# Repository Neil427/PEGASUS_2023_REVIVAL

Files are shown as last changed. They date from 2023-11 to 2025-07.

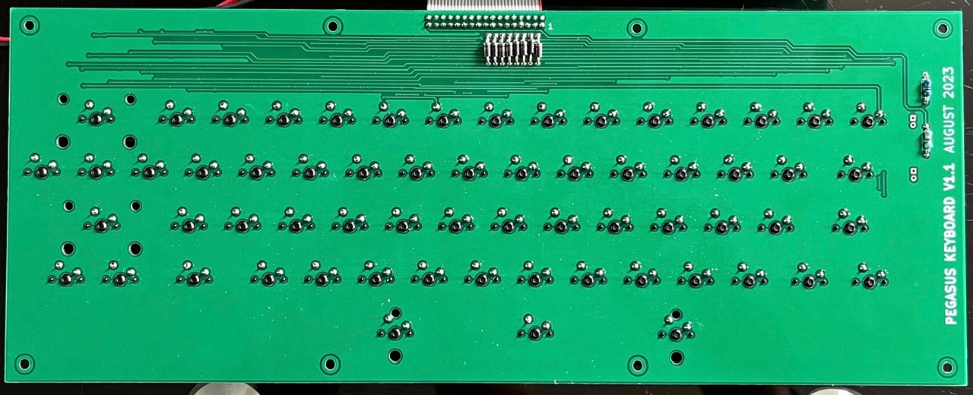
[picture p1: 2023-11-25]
Images/PegasusKeyboardRear.jpeg

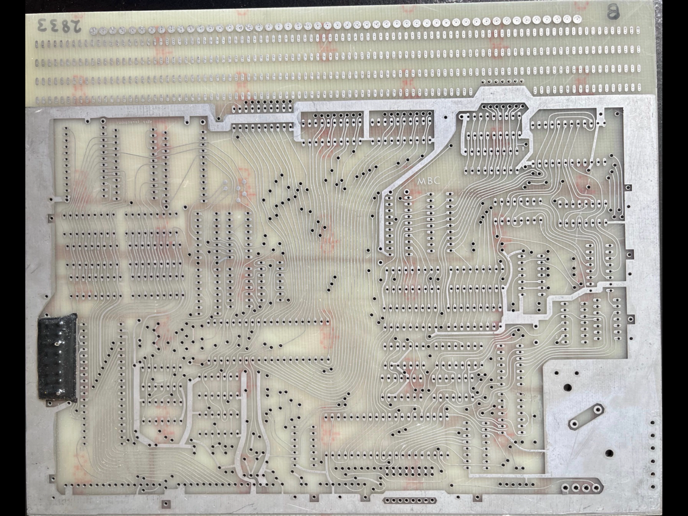
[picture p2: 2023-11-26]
Images/OriginalPCBtop.png

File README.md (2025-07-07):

# PEGASUS_2023_REVIVAL
:

NOTE: FROM 2025 ON DEVELOPMENT WILL CONTINUE ON MY DEDICATED VINTAGE COMPUTER GITHUB "NeilsVintageComputers"

:
AamberPegasus6809

This is a reproduction of the first computer I owned back in 1981
After many years and house moves I now dont know whatever happened to it, it may have been sold or dumped, I have no idea.

One day while sorting through floppy disk backups I found all the Pegasus eprom files I had saved dated 1988, including some extra monitor eproms I had made that I think one was for Baudot printer output and the other was for a modification I had made fitting a 6845 CRT controller.
The discovery of the Eprom files and manual with schematics gave me the idea of building a replica, I mentioned this to a mate Gavin who told me he had a unused blank Pegasus circuit board that I could have and build up.  I decided not to build up the board as a bare board is probably quite rare, and without components on it was a great help in verifying the original schematic and designing this new pcb.

Searching found a huge repository on github of Aamber Pegasus software and information (github/Neoncluster/Aamber-Pegasus-remake), the information is a great recource and thanks to Neoncluster for preserving it. 

It looked like this remake was not completed so I decided to start from scratch from the original Pegasus schematics.
I drew the original schematics from the Pegasus manual into Kicad (thanks to Neoncluster for your Kicad Library), finding a few errors in the original documentation which I could verify on the blank PCB. Then started a new Kicad project for the new PCB, I added in the video jitter mods that were done to correct problems with the original Pegasus video design one of which was designed by Gavin back in the 80s.   NOTE: These jitter mds require the use of MON23a monitor eprom.

I have added a 16K Eprom to the board so as to be able to have the three Xbasic eproms on board without needing an expansion board like I used back in 1981, there is also a switch to select two halves of a 32K eprom giving the equivalent of 8 original 4K eproms. 
Also added are option jumpers for the three TMS2532 eprom sockets to allow selection of either TMS2532 or TMS2732 eproms as the TMS2532 is not easy to find these days, and a LED for tape data indication. 

All ICs used are the original ones as in the original pegasus bom, the 74LS logic chips are still available and most of the rareish chips were available on Ebay and other places. The only expensive (read very rare) one was the MCM66710 character generator which I found on Ebay only.

Amazingly it worked first time! All the hours of tracing out what I thought were errors in the original schematic had paid off. 
There was one minor problem I found, if you have no memory/eprom expansion board plugged in but have the LS245 buffer fitted the firmware can read in random data from the expansion bus when doing its check of RamEnd. This causes Basic (or any other program using RamEnd) to crash when trying to use non-existing memory. By luck after trying a few brands (inclding 74HCT245s) I discovered that a Ti brand SN74LS245N worked (Maybe that brand was used in the original Pegasus as I dont remember this being a problem back in 1981), the memory check now doesnt find non-existant memory on the expansion bus. Some pullup resistors on the expansion bus side of these buffers would be a good idea.

Now I had a working Pegasus all I needed was a keyboard. The manual doesnt have the keyboard schematic so this was a lot of work systematically producing key closures and seeing what character they produced!  The first pcb mostly worked, a few of the non printing keys were wrong, so it took another board to correct these. I havent found any errors yet with the current board.  You cant buy cheap Chinese keycaps exactly the same as the old Pegasus keyboard so I have found a set with logical alternatives (i.e."END" for the Break key etc.), you could of course print some stickers with the correct name.
The keyboard has a 34-pin IDC connector as I am going to use it with another board I am working on. For use on the Pegasus main board the "even" side of the idc connector (pins 2-----32) plug into the SIL connector on the main board, alternatively a 16-pin SIL header can be inserted in keyboard pcb connector positions 2-----32 to allow use of SIL connectors as in the original Pegasus (Though my sketchy memory is telling me the KB end of the cable might have been soldered direct to the pcb).  
There are two unused LEDs on the Keyboard pcb intended for use as Power On and Cassette Data, these appear on the 34-pin connector but are not brought out on the main board.

NOTES/ISSUES:
- The resistor on the rear of the pcb is a pullup on the bit7 input to the video output shift register (not in the original Pegasus design) to try and remove a small video disturbance at the top of the screen before the first video character line when in graphics mode. It definalely helped but there is still a small disturbance. Need to look into this further.
Further investigation found a faulty 6809 driving one or two of the address lines to only about 2.5V
Needs further investigation and maybe a "improved" design board to be produced as it looks like the original Pegasus design has many more than 4 LS-TTL loads, as specified in the 6809 datasheet, on the address and data lines. It did still work ok with six out of seven 6809 chips I tried. Just one didnt work 100% reliably.
- The 127p capacitor C10 on the dotclock oscillator can be adjusted to trim the dotclock frequency. I noticed on my build that the shift register was clocking out a extra bit making the characters wider than they should be, not really noticeable in text mode but in inverse char graphics mode there would be a "lit up" column of dots at the right of each character.  If the dotclock is too slow the oposite will happen which is noticeable in both text and graphics mode as trimming of the right most dot of a character. I ended up with 138pF (120p + 18p).
- The PCB although the same dimension as the original cant be slid into the original Pegasus square white case as I inadvertently laid the power tracks too close to the edge of the pcb!
- The resistor footprint used is a bit large, needs reducing if producing a update to the board.
  
Here are some phtos of the finished "Pegasus"

AamberPegasus1

AamberPegasus2

Neil

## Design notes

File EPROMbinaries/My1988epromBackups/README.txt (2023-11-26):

These eprom binaries will not all work in a Pegasus board, some of them are experimental ones that I made which I will try to remember/discover what for and update this readme.
Anyone building this should use the Mon23a monitor and the combined eprom files set up to go in Rom4 socket.

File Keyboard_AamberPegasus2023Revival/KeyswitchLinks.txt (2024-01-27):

7.5V 3A PLUGPACK

https://www.aliexpress.com/item/1005006269859150.html

NOTE: THERE IS A AU PLUG OPTION ON THIS LISTING

KEYBOARD SWITCHES

https://vi.aliexpress.com/item/32810197006.html?spm=a2g0o.cart.0.0.352b38daK8j2Au&mp=1&gatewayAdapt=glo2vnm

NOTE: ORDER 5-PIN CHERRY TYPE, THE BLACK ONES HAVE THE MOST VINTAGE FEEL.

KEYBOARD KEYCAPS

THESE ARE ONES I FOUND THAT WILL FIT THE SWITCH SPACINGS ON THE PCB

https://vi.aliexpress.com/item/1005005924340896.html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

NOTE: OTHER SETS DON'T ALLWAYS HAVE THE CORRECT LENGTH AND SWITCH CENTER FOR ALL THE CONTROL TYPE KEYS

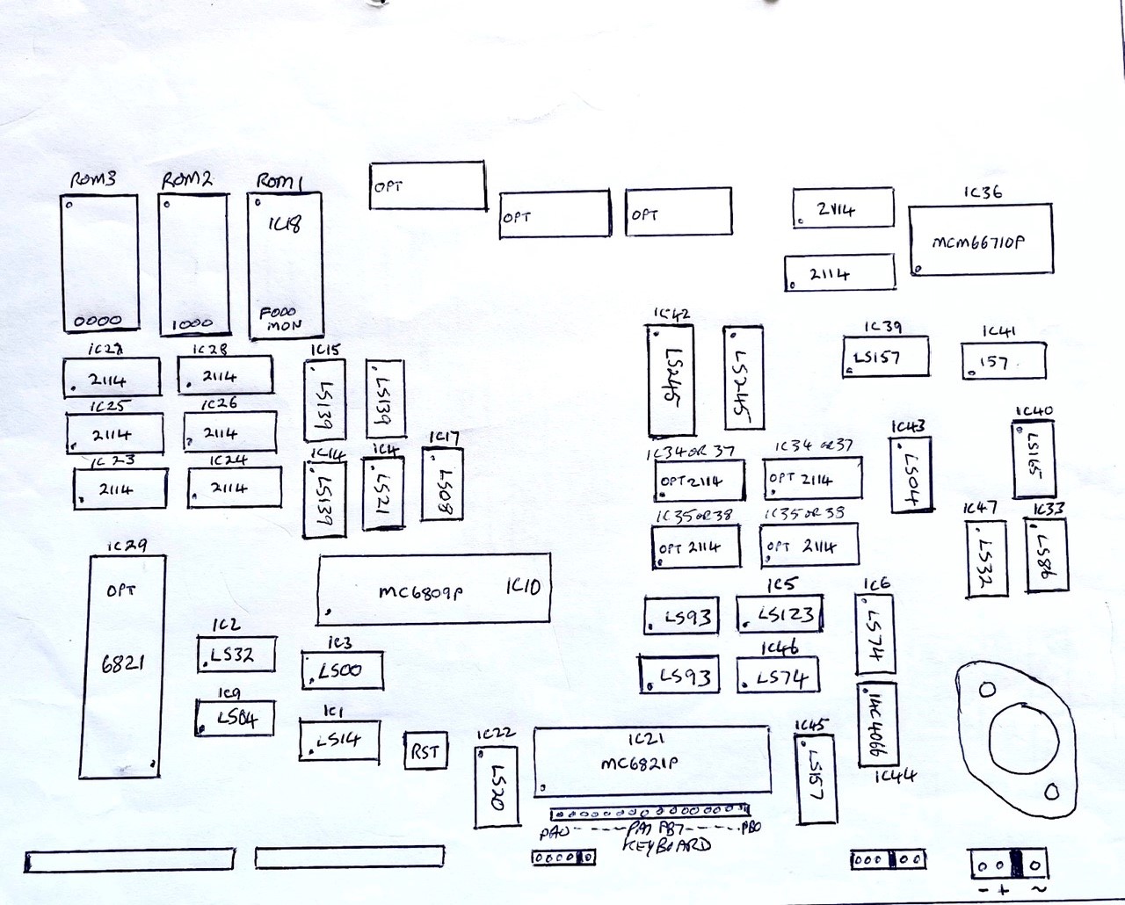
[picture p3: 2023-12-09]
OriginalPegasusSchematic/AamberPegasusOriginalPCBchipLayout.png

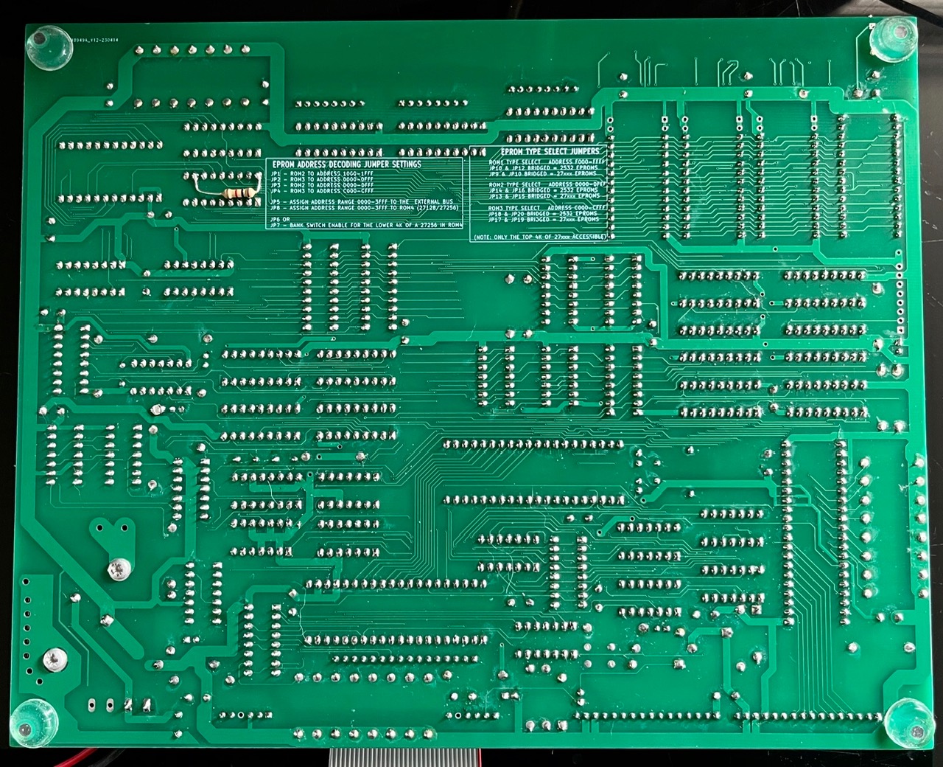
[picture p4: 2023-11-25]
Images/PegasusPcbRear.jpeg

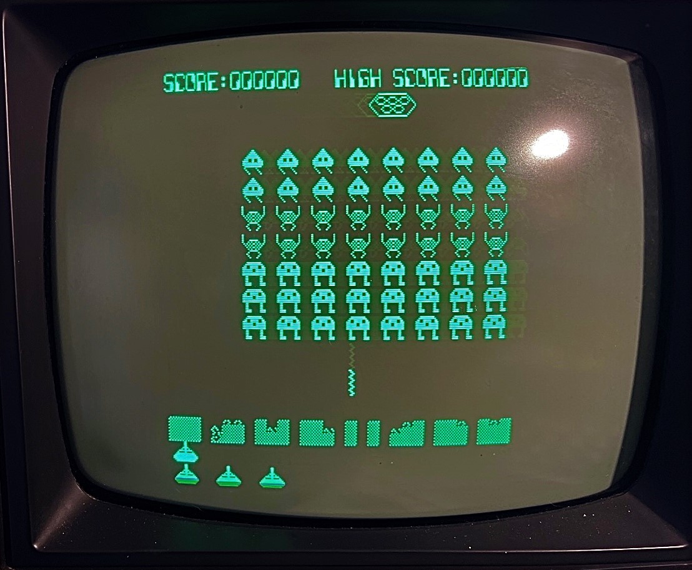
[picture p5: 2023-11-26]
Images/PegasusInvaders (2).jpg

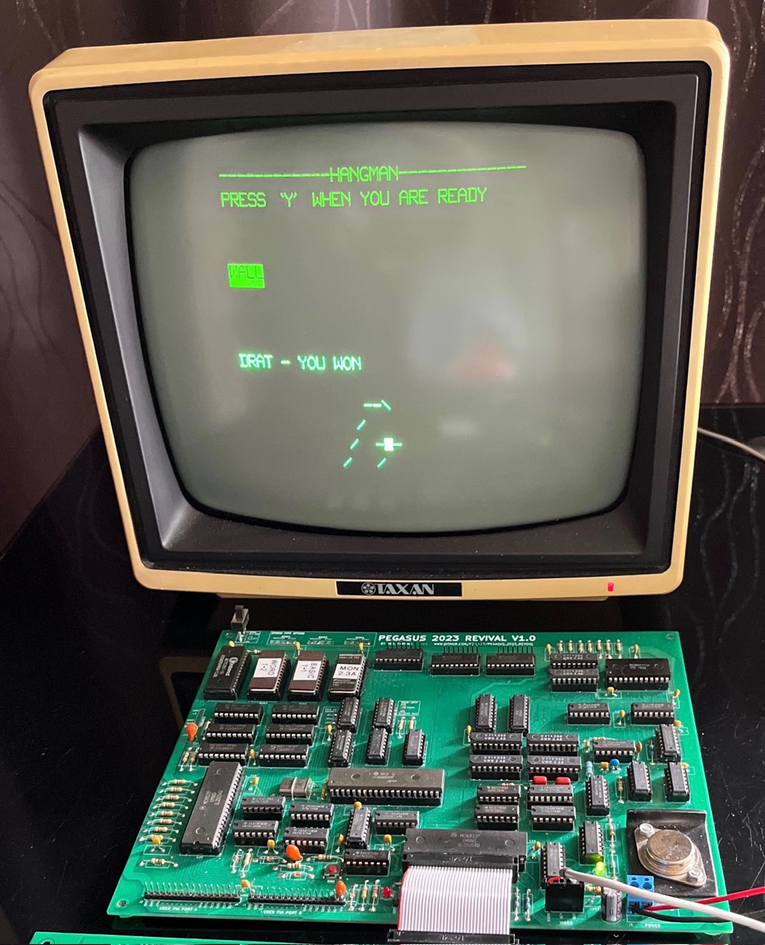
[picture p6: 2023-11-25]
Images/PegasusHangman2.jpeg

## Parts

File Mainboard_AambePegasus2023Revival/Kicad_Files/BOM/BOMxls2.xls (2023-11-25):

Item | Qty | Reference(s) | Value
1 | 1 | C1 | 150N
2 | 1 | C2 | 330N
3 | 1 | C3 | 100N
4 | 1 | C4 | 1uF 35V
5 | 2 | C5, C6 | 27p
6 | 1 | C7 | 1uF 35V Tant
7 | 22 | C8, C12, C13, C14, C15, C16, C17, C18, C19, C20, C21, C22, C23, C24, C25, C26, C27, C28, C29, C30, C31, C103 | 100N
8 | 1 | C9 | 47p | Status
9 | 1 | C10 | 127p
10 | 1 | C11 | 1uF 35V T
11 | 1 | C32 | 1N
12 | 1 | C33 | 47pF
13 | 1 | C34 | 47uF
14 | 1 | D1 | 3mmLED
15 | 1 | D2 | GreenLED
16 | 4 | D3, D4, D5, D6 | 1N4148
17 | 1 | J1 | PIA PortB
18 | 1 | J2 | PIA PortA
19 | 1 | J3 | Cassette Tape
20 | 1 | J4 | Video Out
21 | 1 | J5 | Power
22 | 1 | J8 | External Data Bus
23 | 2 | J9, J10 | External Address Bus
24 | 1 | J11 | SPARE
25 | 1 | J12 | Keyboard
26 | 1 | JP1 | rom2
27 | 1 | JP2 | rom3
28 | 1 | JP3 | rom2 alt
29 | 1 | JP4 | rom3 alt
30 | 2 | JP5, JP8 | opt.
31 | 1 | JP6 | romL
32 | 1 | JP7
33 | 6 | JP9, JP11, JP13, JP15, JP17, JP19 | 27Cxxx
34 | 6 | JP10, JP12, JP14, JP16, JP18, JP20 | 2532
35 | 2 | R1, R2 | 100R
36 | 1 | R3 | 8K2
37 | 1 | R4 | 27K
38 | 1 | R5 | 100K
39 | 1 | R6 | 1M
40 | 24 | R7, R8, R9, R10, R11, R12, R13, R16, R17, R18, R19, R20, R21, R22, R23, R28, R29, R30, R31, R32, R33, R34, R35, R44 | 1K
41 | 1 | R14 | 470R
42 | 10 | R15, R36, R37, R38, R39, R40, R41, R42, R43, R45 | 4K7
43 | 1 | R24 | 220R
44 | 1 | R25 | 470
45 | 1 | R26 | 390R
46 | 1 | R27 | 2K7
47 | 1 | SW1 | NMI
48 | 1 | U1 | 74LS14
49 | 2 | U2, U47 | 74LS32
50 | 1 | U3 | 74LS00
51 | 1 | U4 | 74LS21
52 | 1 | U5 | 74LS123
53 | 2 | U6, U46 | 74LS74
54 | 2 | U7, U8 | 74LS93
55 | 2 | U9, U43 | 74LS04
56 | 1 | U10 | MC6809
57 | 3 | U11, U30, U42 | 74LS245
58 | 2 | U12, U13 | 74LS241
59 | 3 | U14, U15, U16 | 74LS139
60 | 1 | U17 | 74LS08
61 | 3 | U18, U19, U20 | EPROM
62 | 2 | U21, U29 | 6821
63 | 2 | U22, U49 | 74LS20
64 | 6 | U23, U24, U25, U26, U27, U28 | MC2114RAM
65 | 6 | U31, U32, U34, U35, U37, U38 | MC2114
66 | 1 | U33 | 74LS86
67 | 1 | U36 | MC66710
68 | 3 | U39, U41, U45 | 74LS157
69 | 1 | U40 | 74LS165
70 | 1 | U44 | 4066
71 | 1 | U48 | 4020
72 | 1 | U50 | 27128/27256
73 | 1 | Ureg1 | LM309K
74 | 1 | Y1 | 4MHz
 |  |  |  | Obsolete NonStock
 |  |  |  | Status
 |  |  |  | Obsolete NonStock

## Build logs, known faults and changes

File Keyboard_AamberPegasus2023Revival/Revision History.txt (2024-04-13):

V1.0 	- Development version with only alpha-numeric switches routed
V1.1 	- First production version
V1.2 	- Spacebar moved to row 7 as original Pegasus KB(works in row 5 as well as in V1.1)
	- Swapped ESC and BREAK keys, they were inadvertently swapped in V1.1
	- Added unused Repeat Key and 2x unused extra keys

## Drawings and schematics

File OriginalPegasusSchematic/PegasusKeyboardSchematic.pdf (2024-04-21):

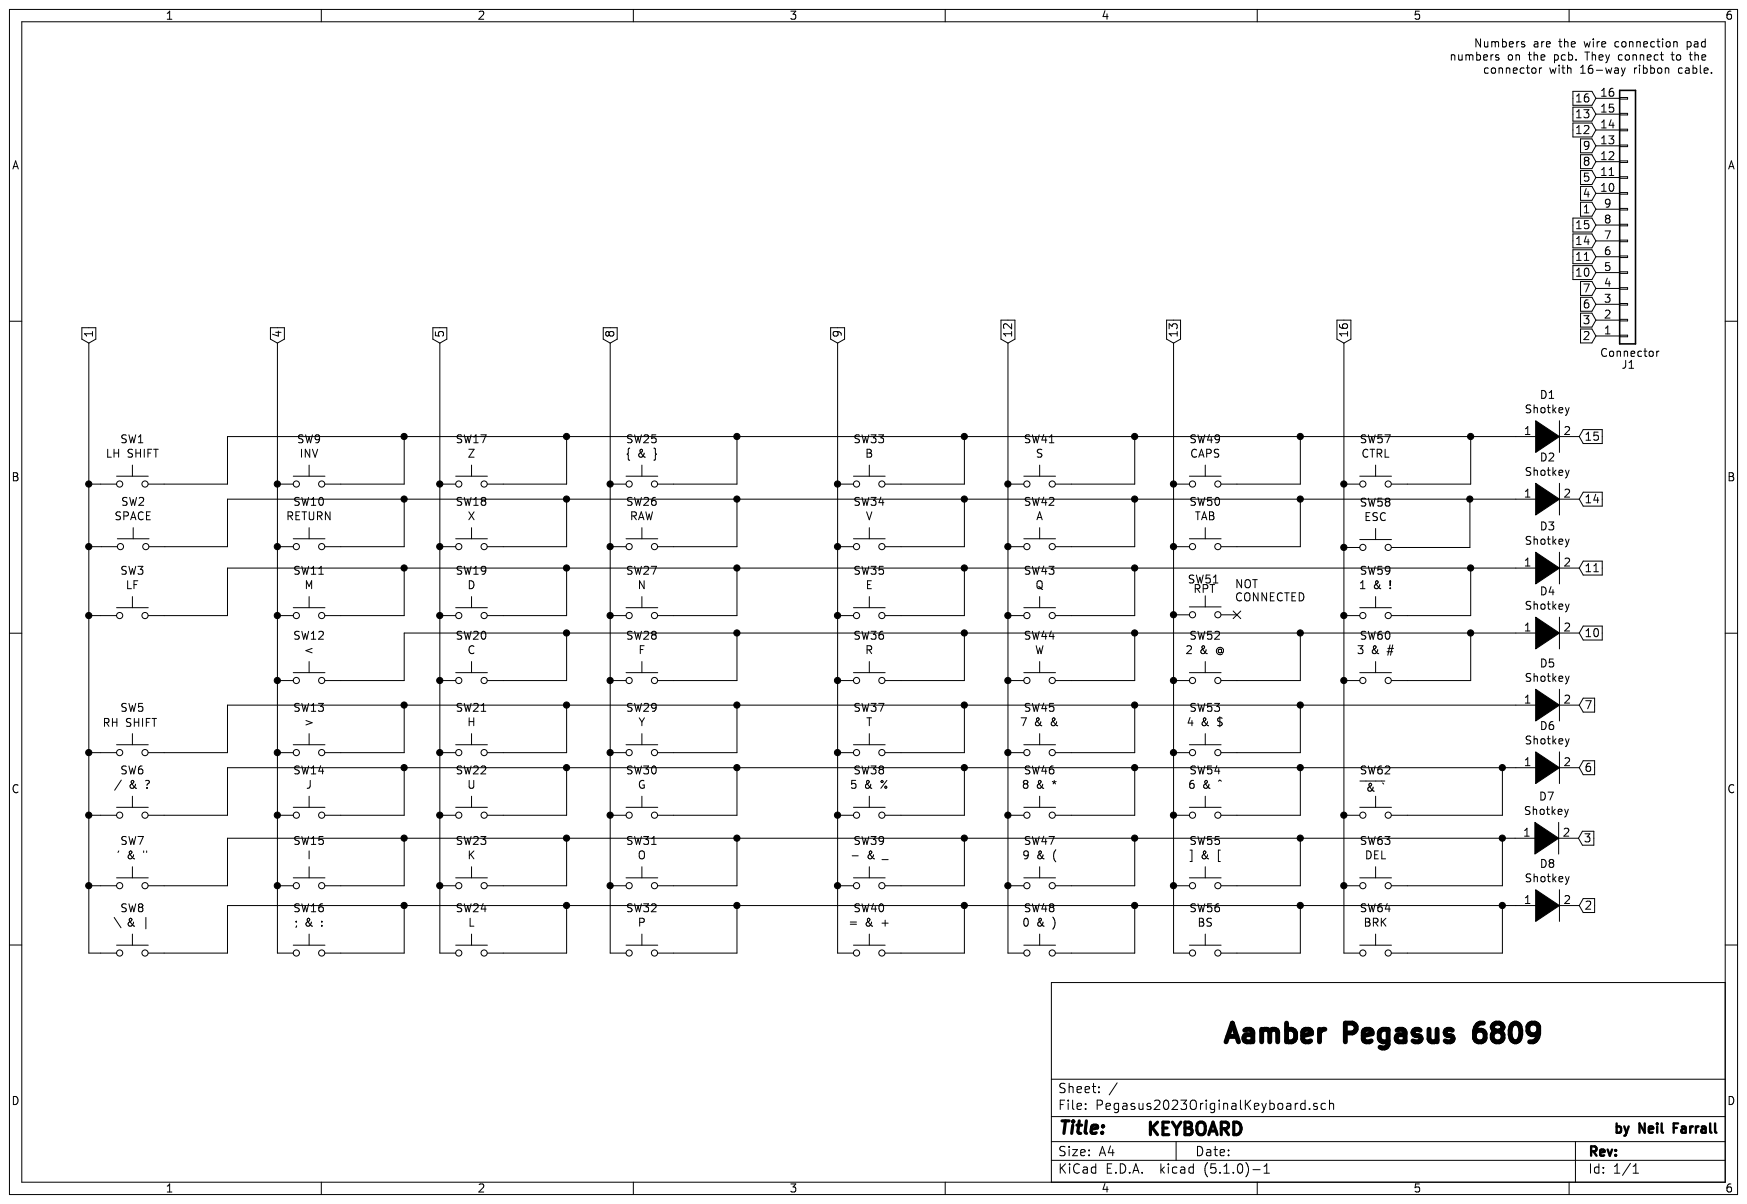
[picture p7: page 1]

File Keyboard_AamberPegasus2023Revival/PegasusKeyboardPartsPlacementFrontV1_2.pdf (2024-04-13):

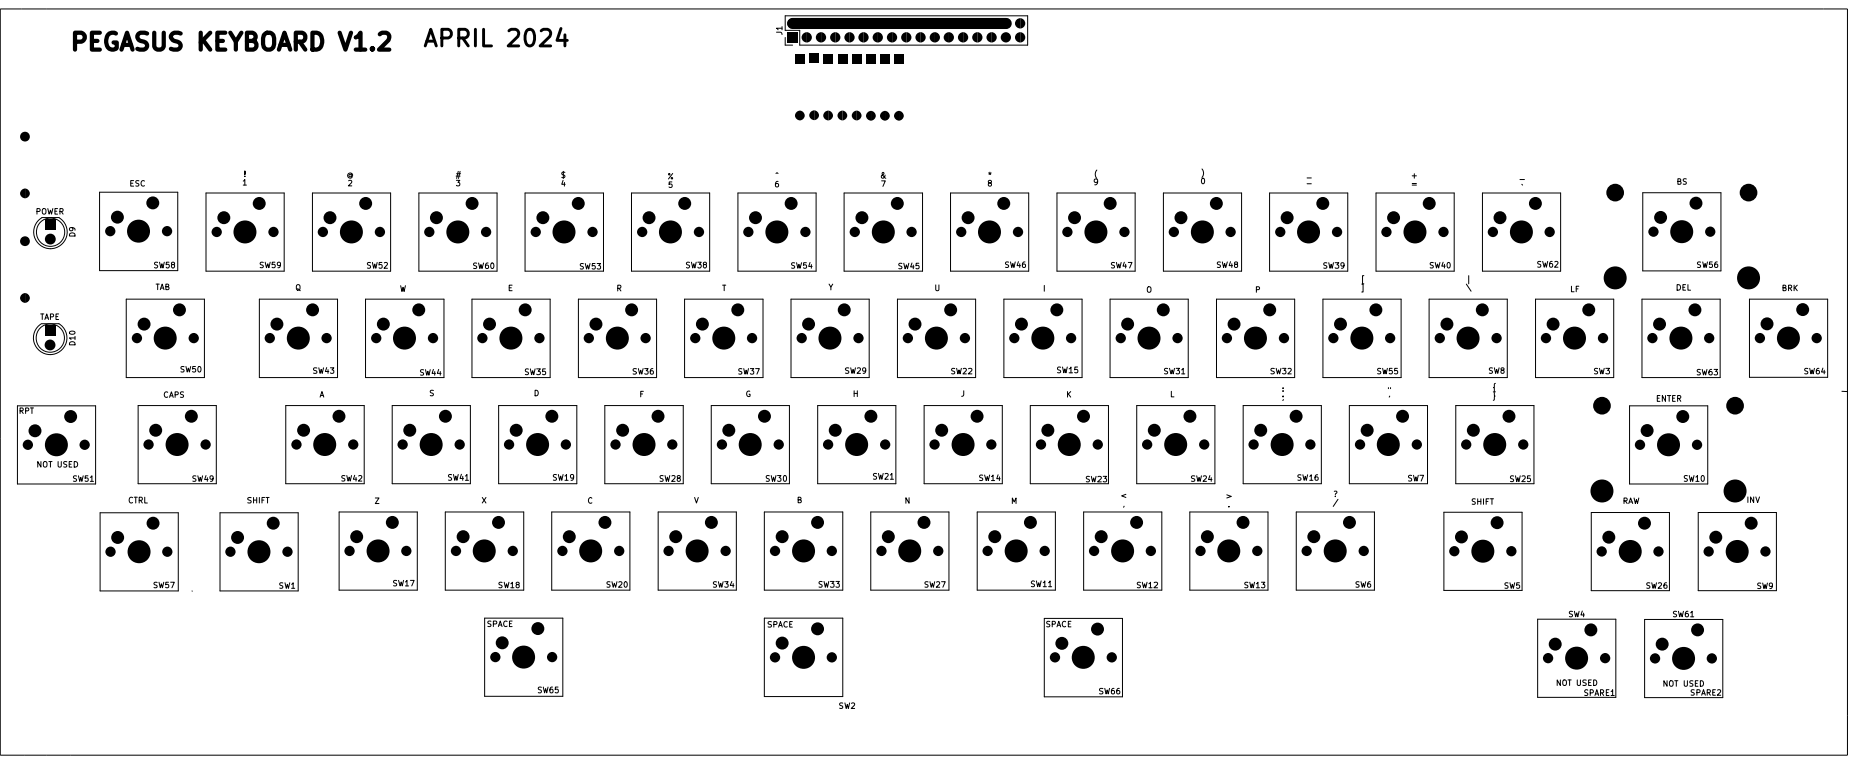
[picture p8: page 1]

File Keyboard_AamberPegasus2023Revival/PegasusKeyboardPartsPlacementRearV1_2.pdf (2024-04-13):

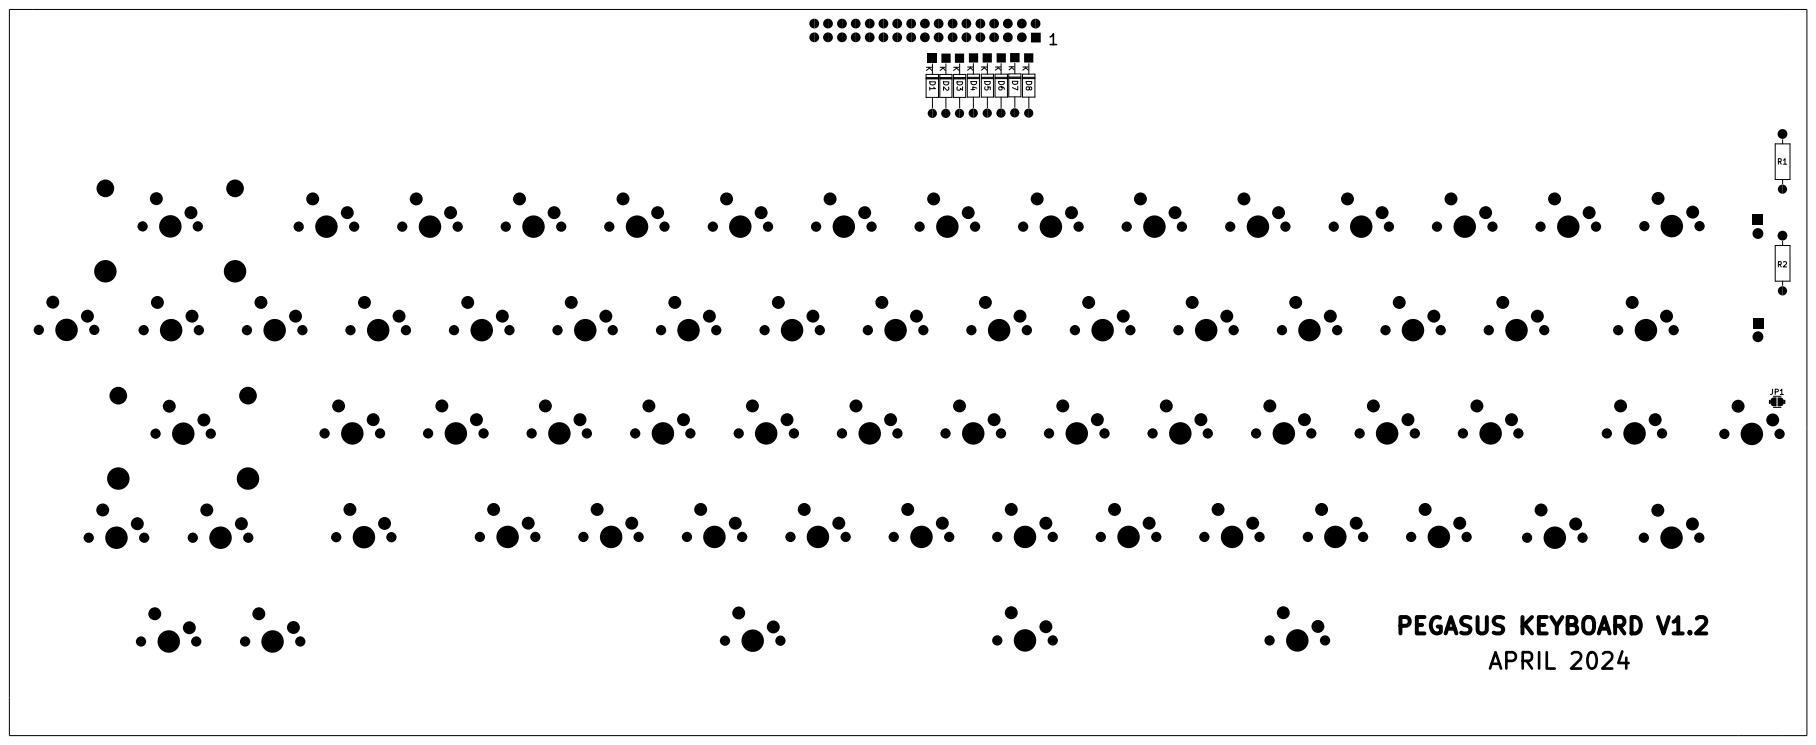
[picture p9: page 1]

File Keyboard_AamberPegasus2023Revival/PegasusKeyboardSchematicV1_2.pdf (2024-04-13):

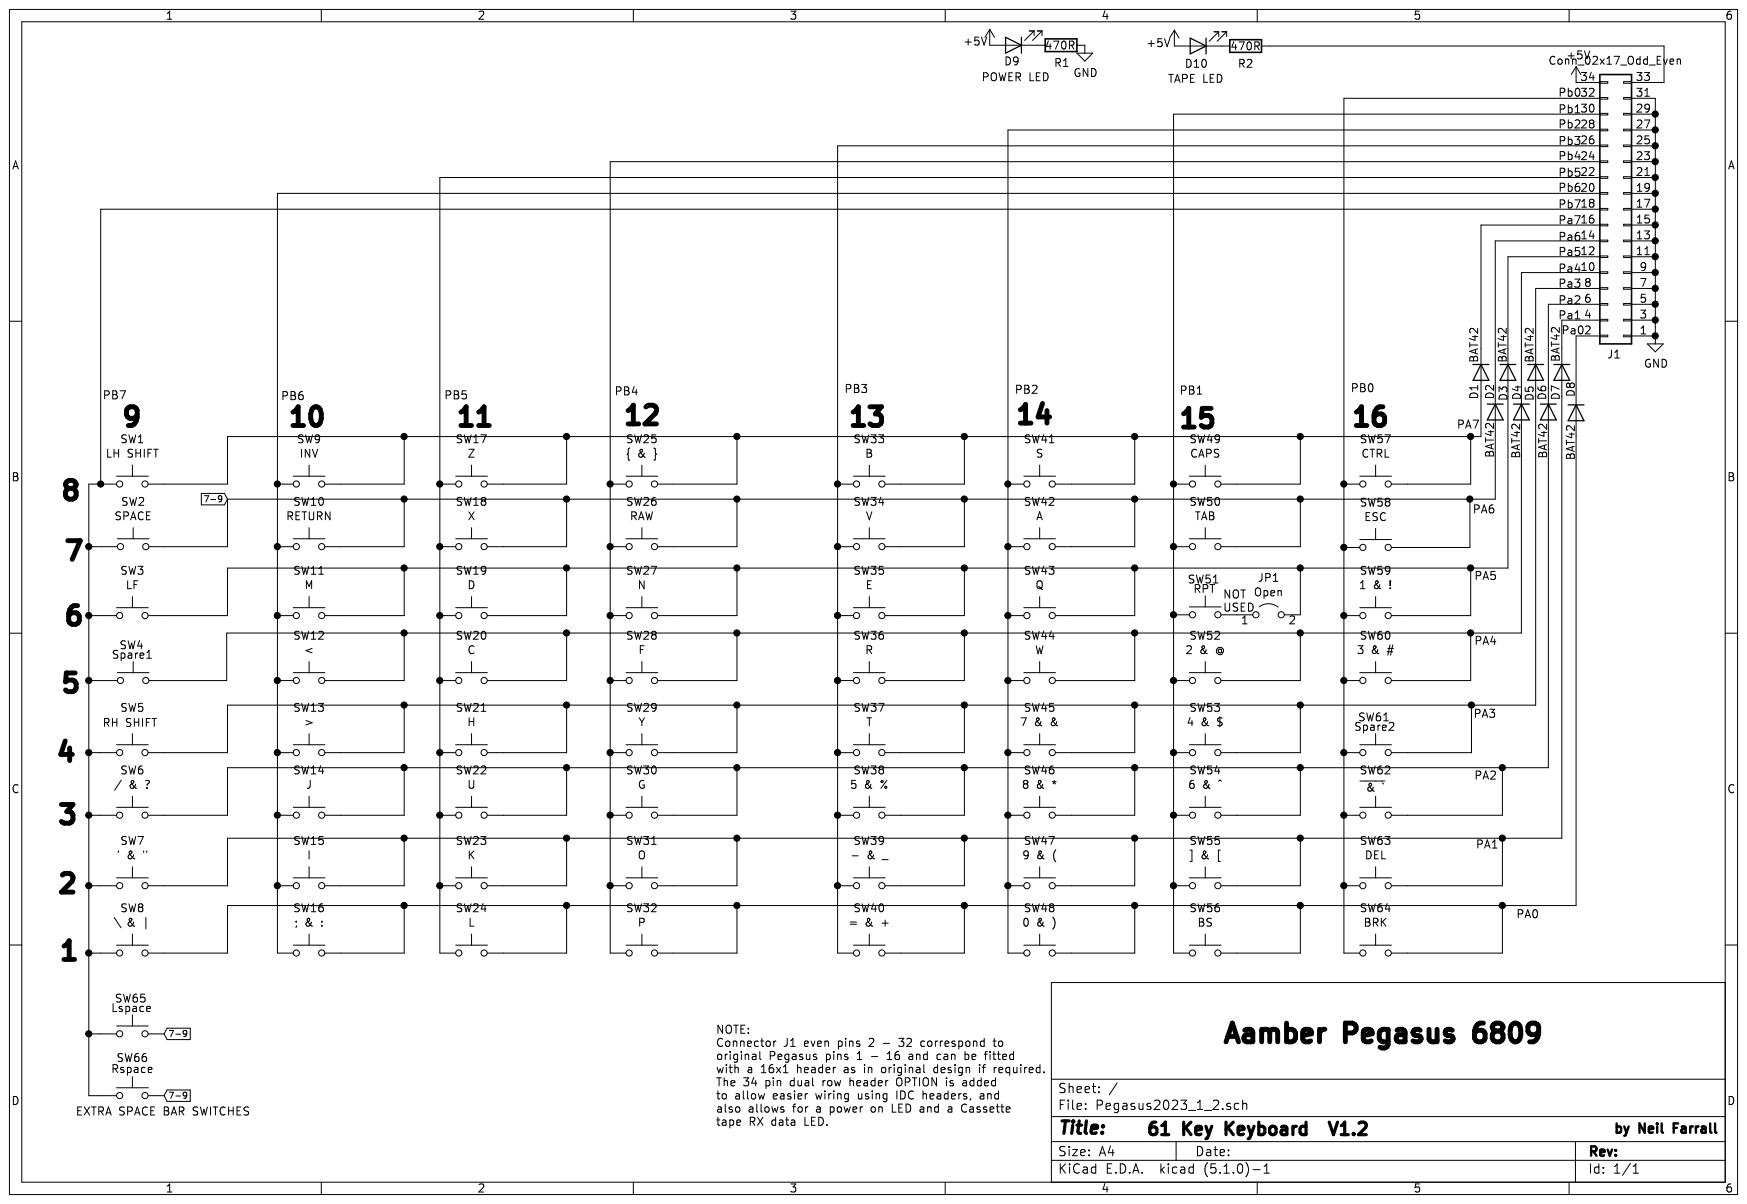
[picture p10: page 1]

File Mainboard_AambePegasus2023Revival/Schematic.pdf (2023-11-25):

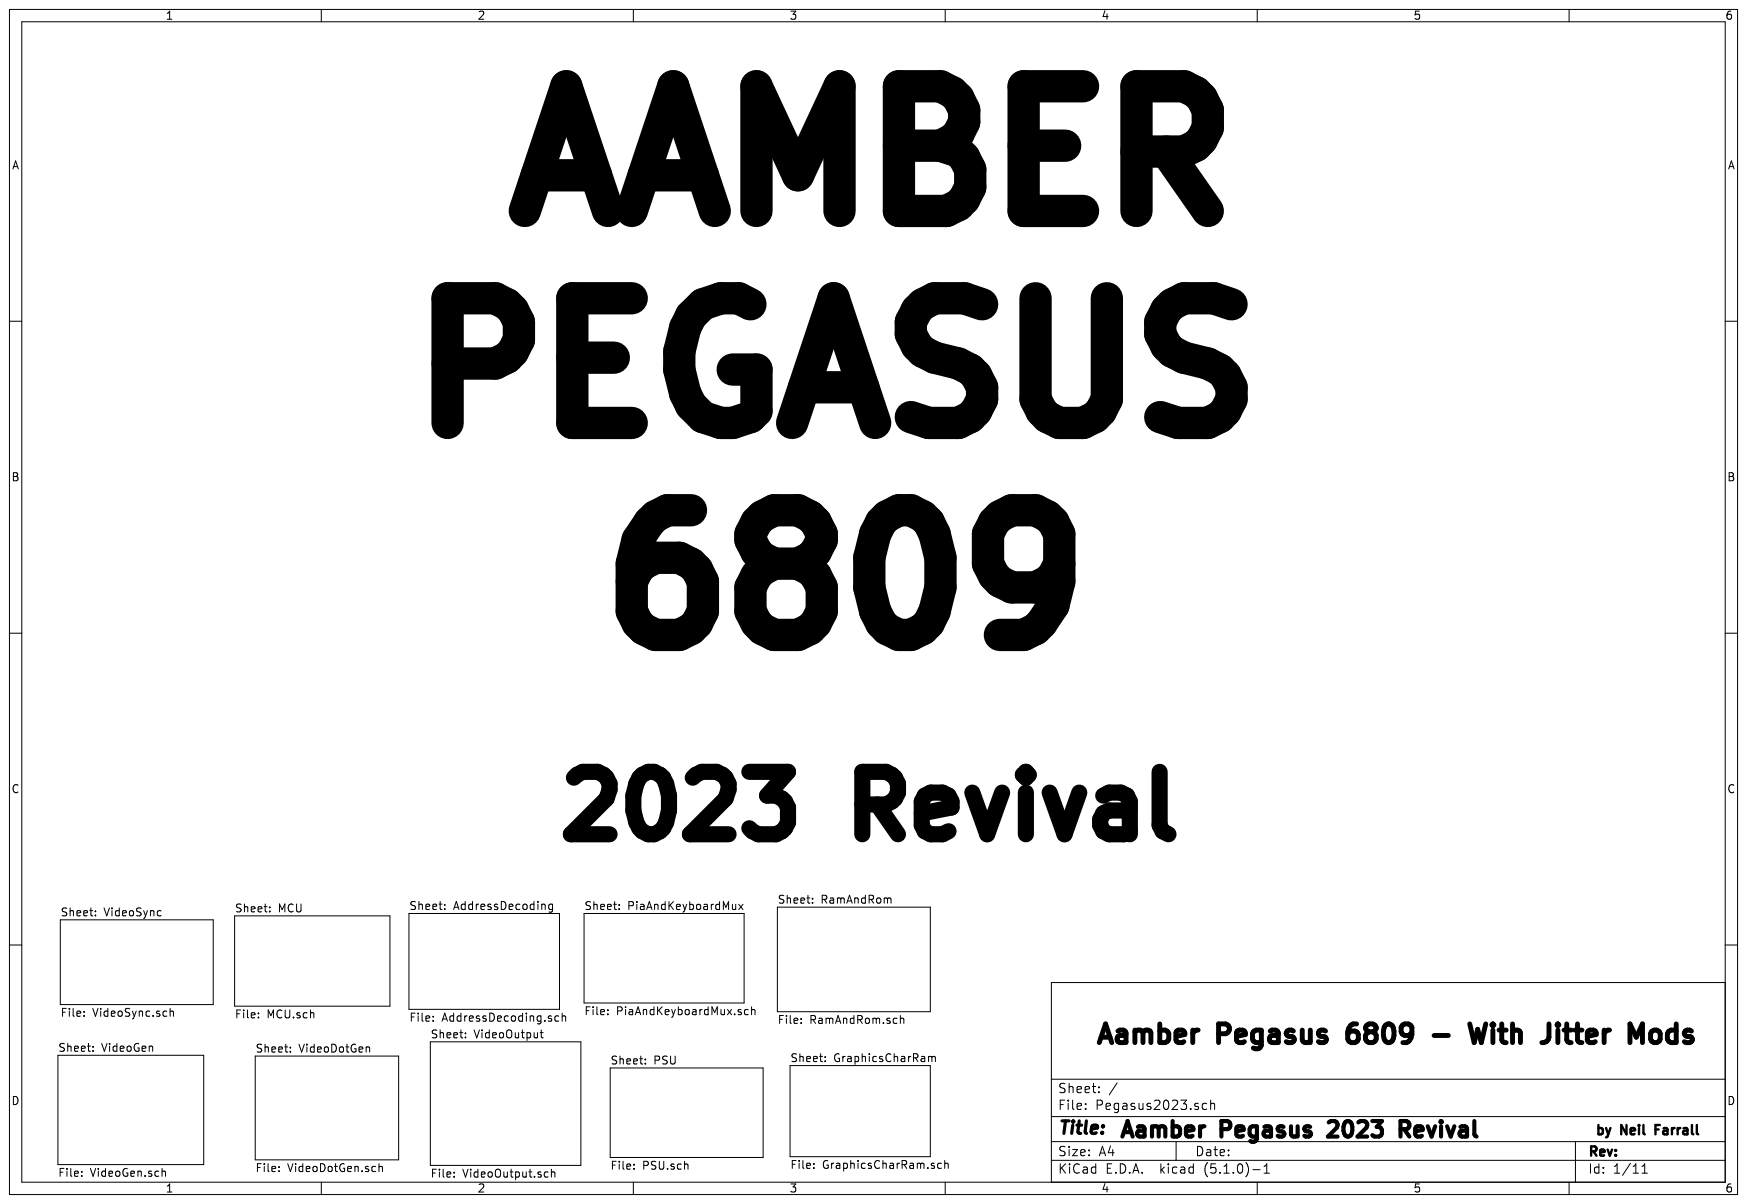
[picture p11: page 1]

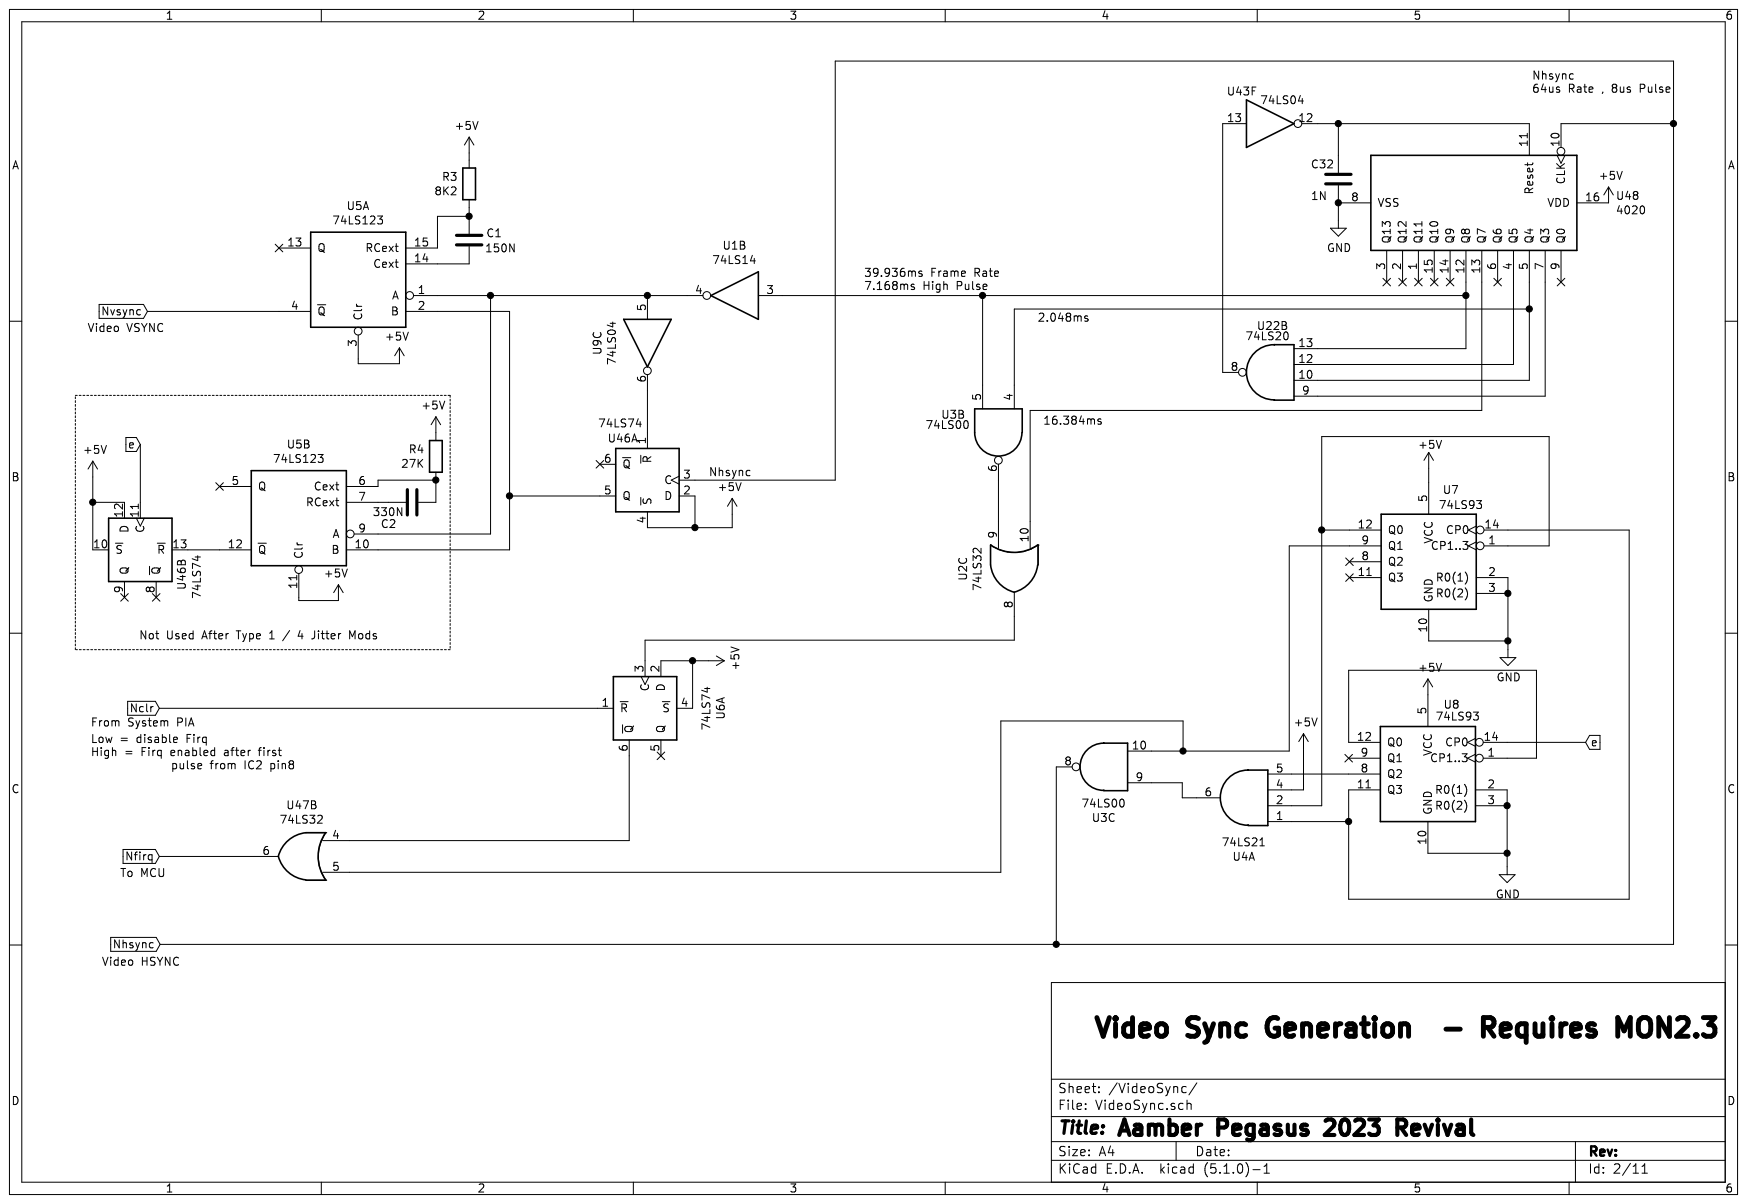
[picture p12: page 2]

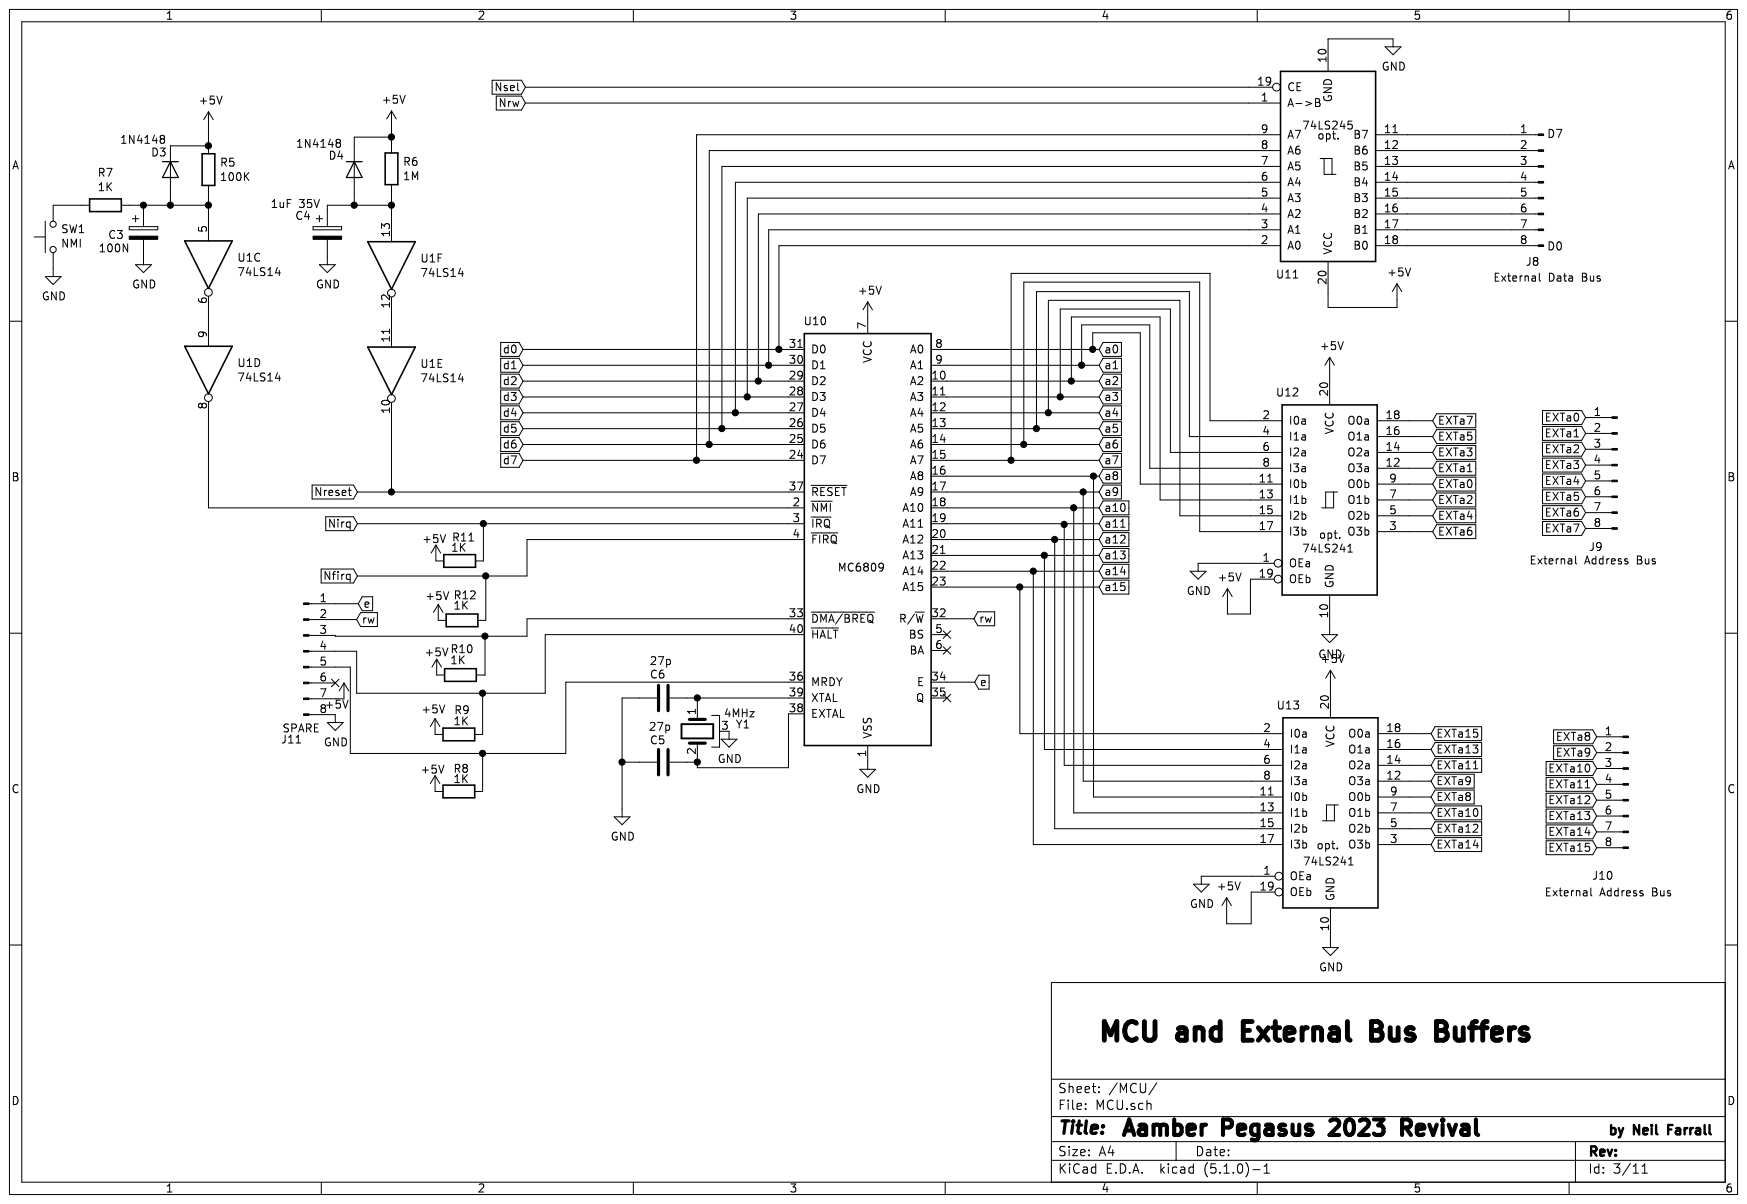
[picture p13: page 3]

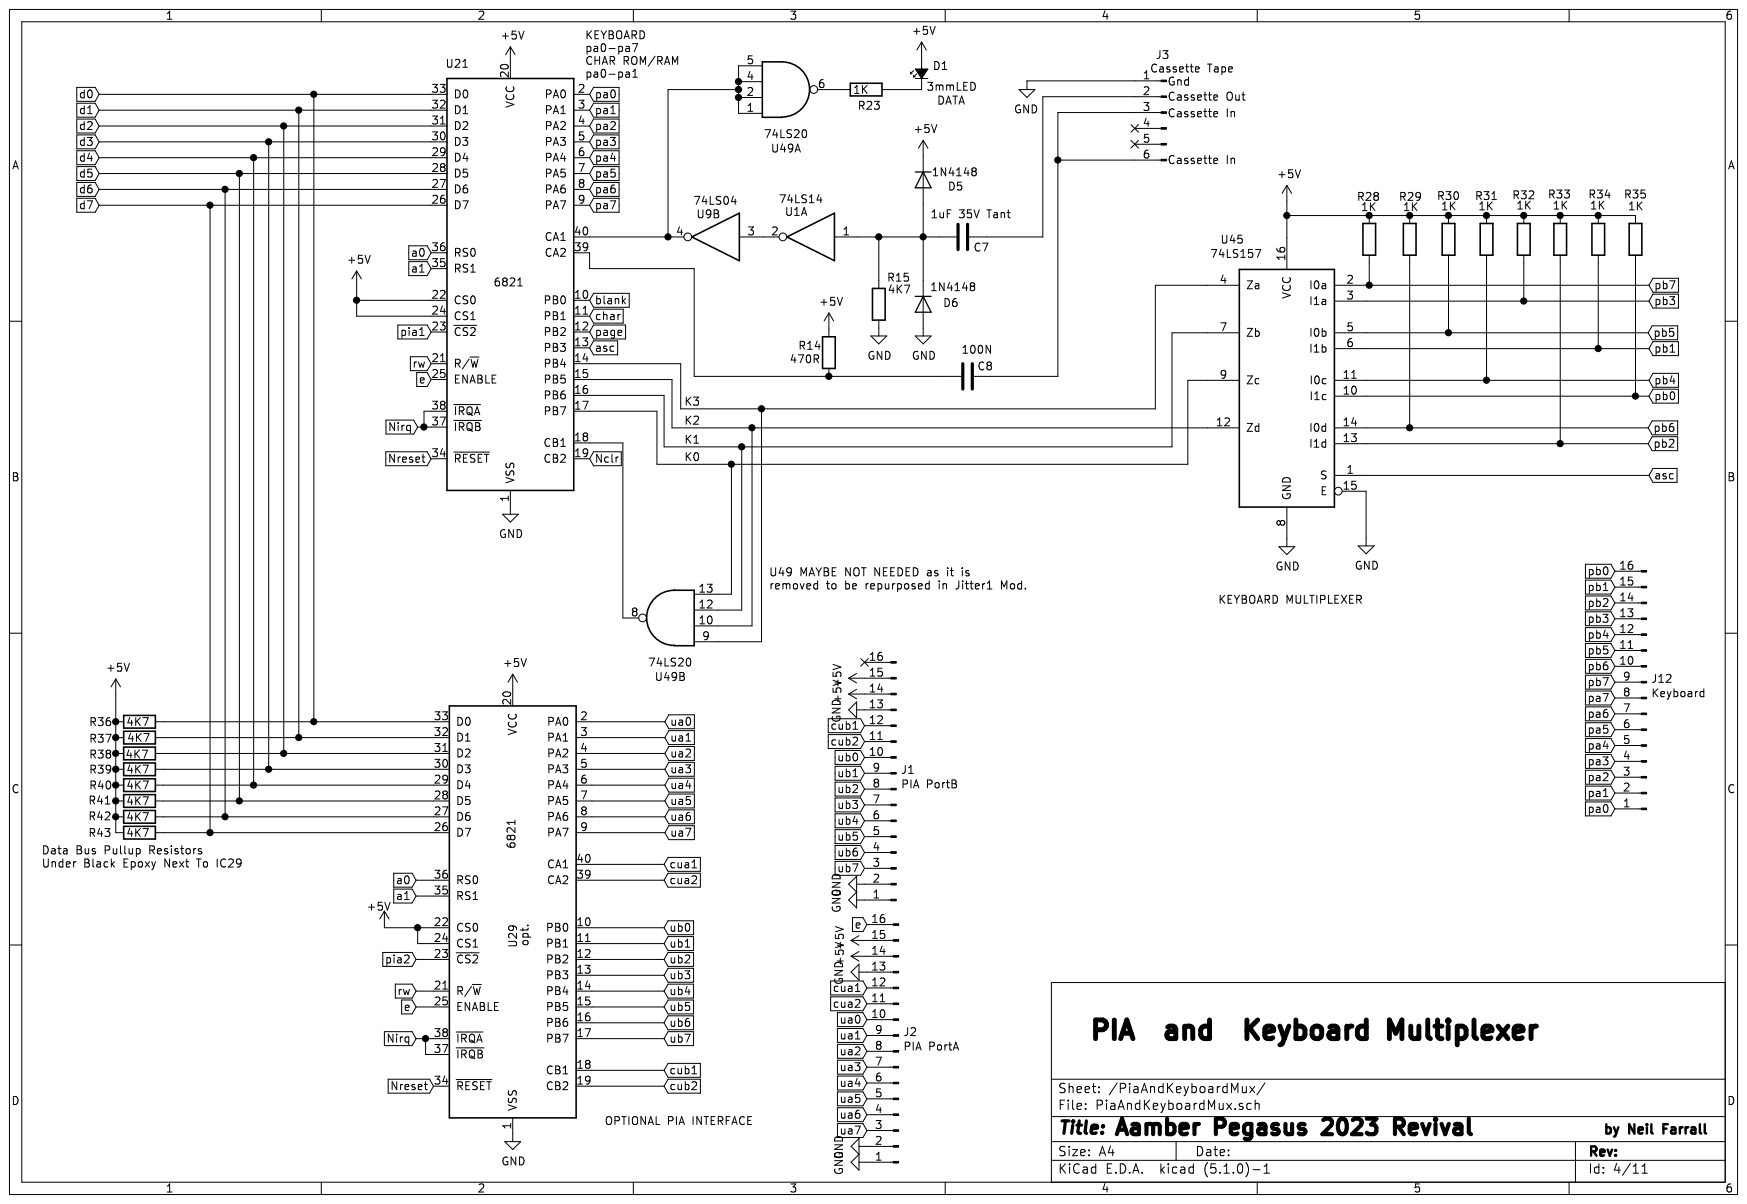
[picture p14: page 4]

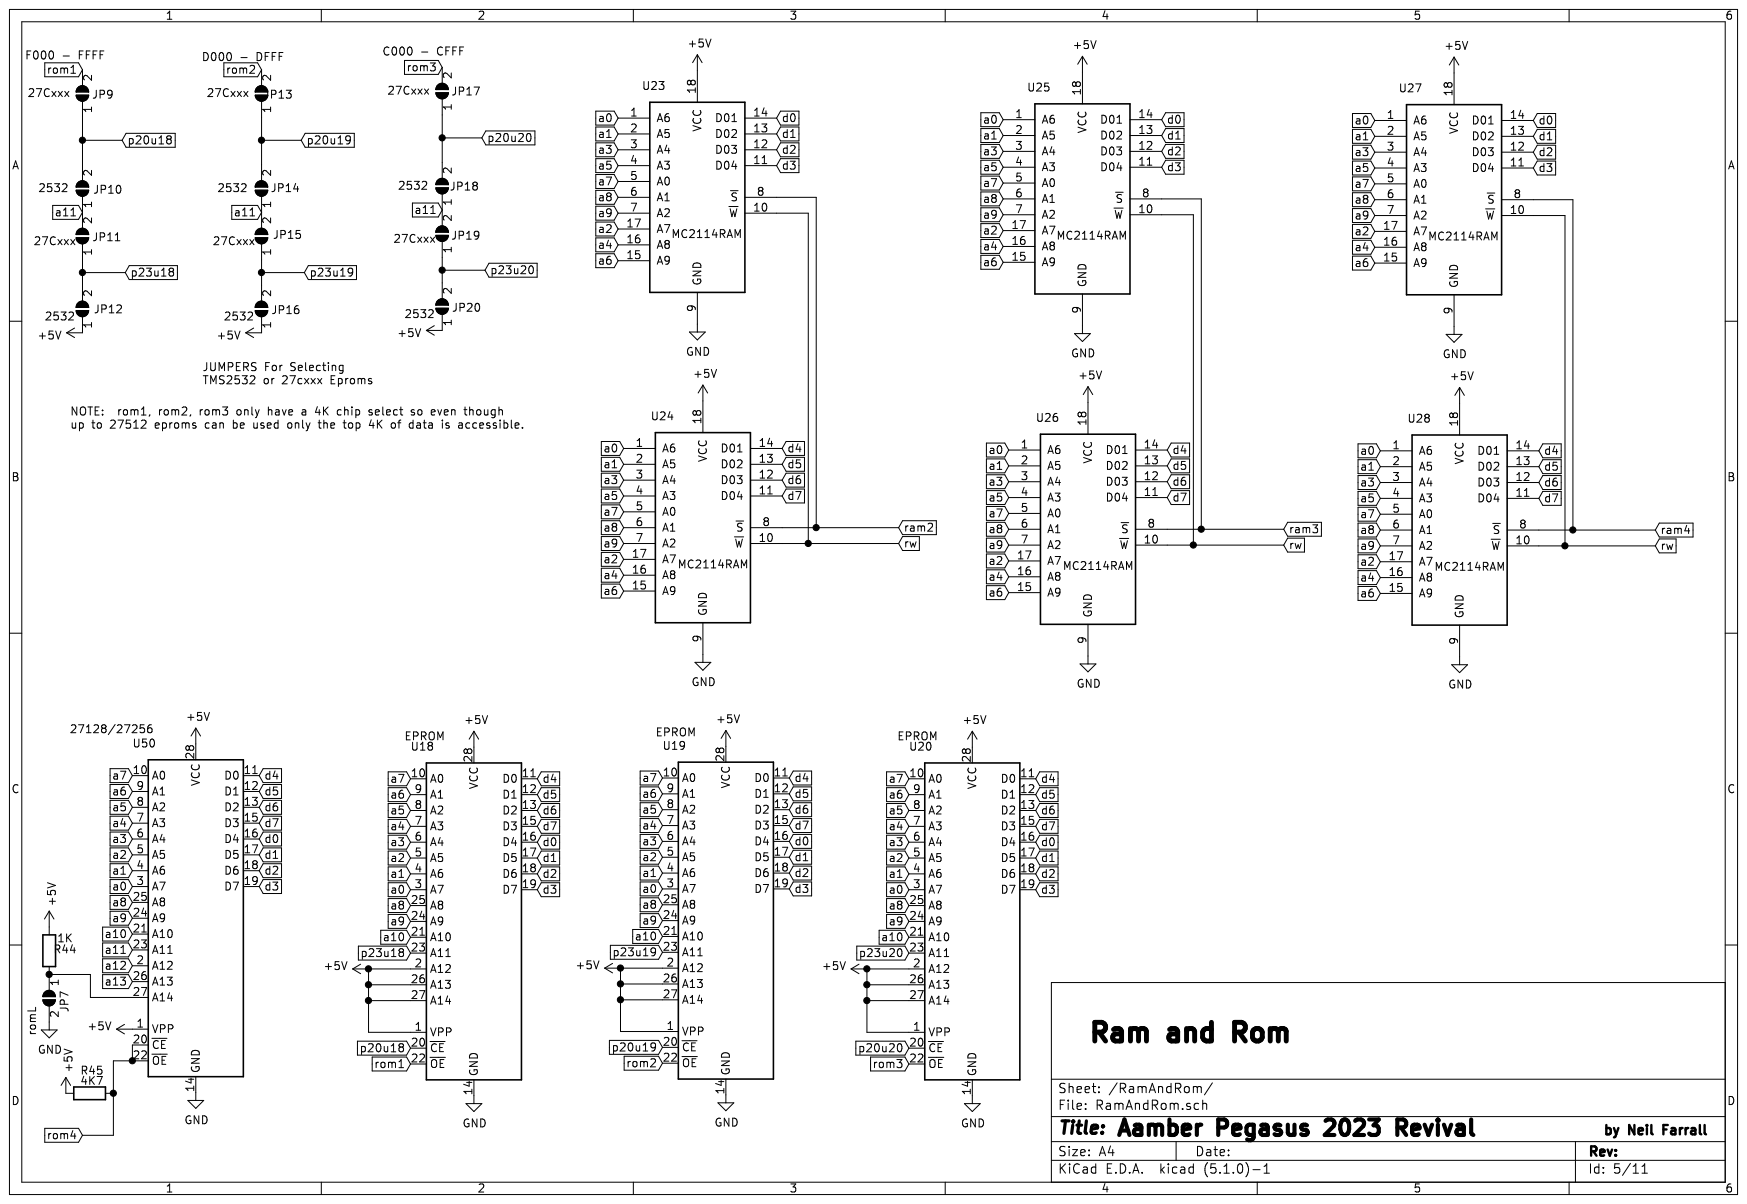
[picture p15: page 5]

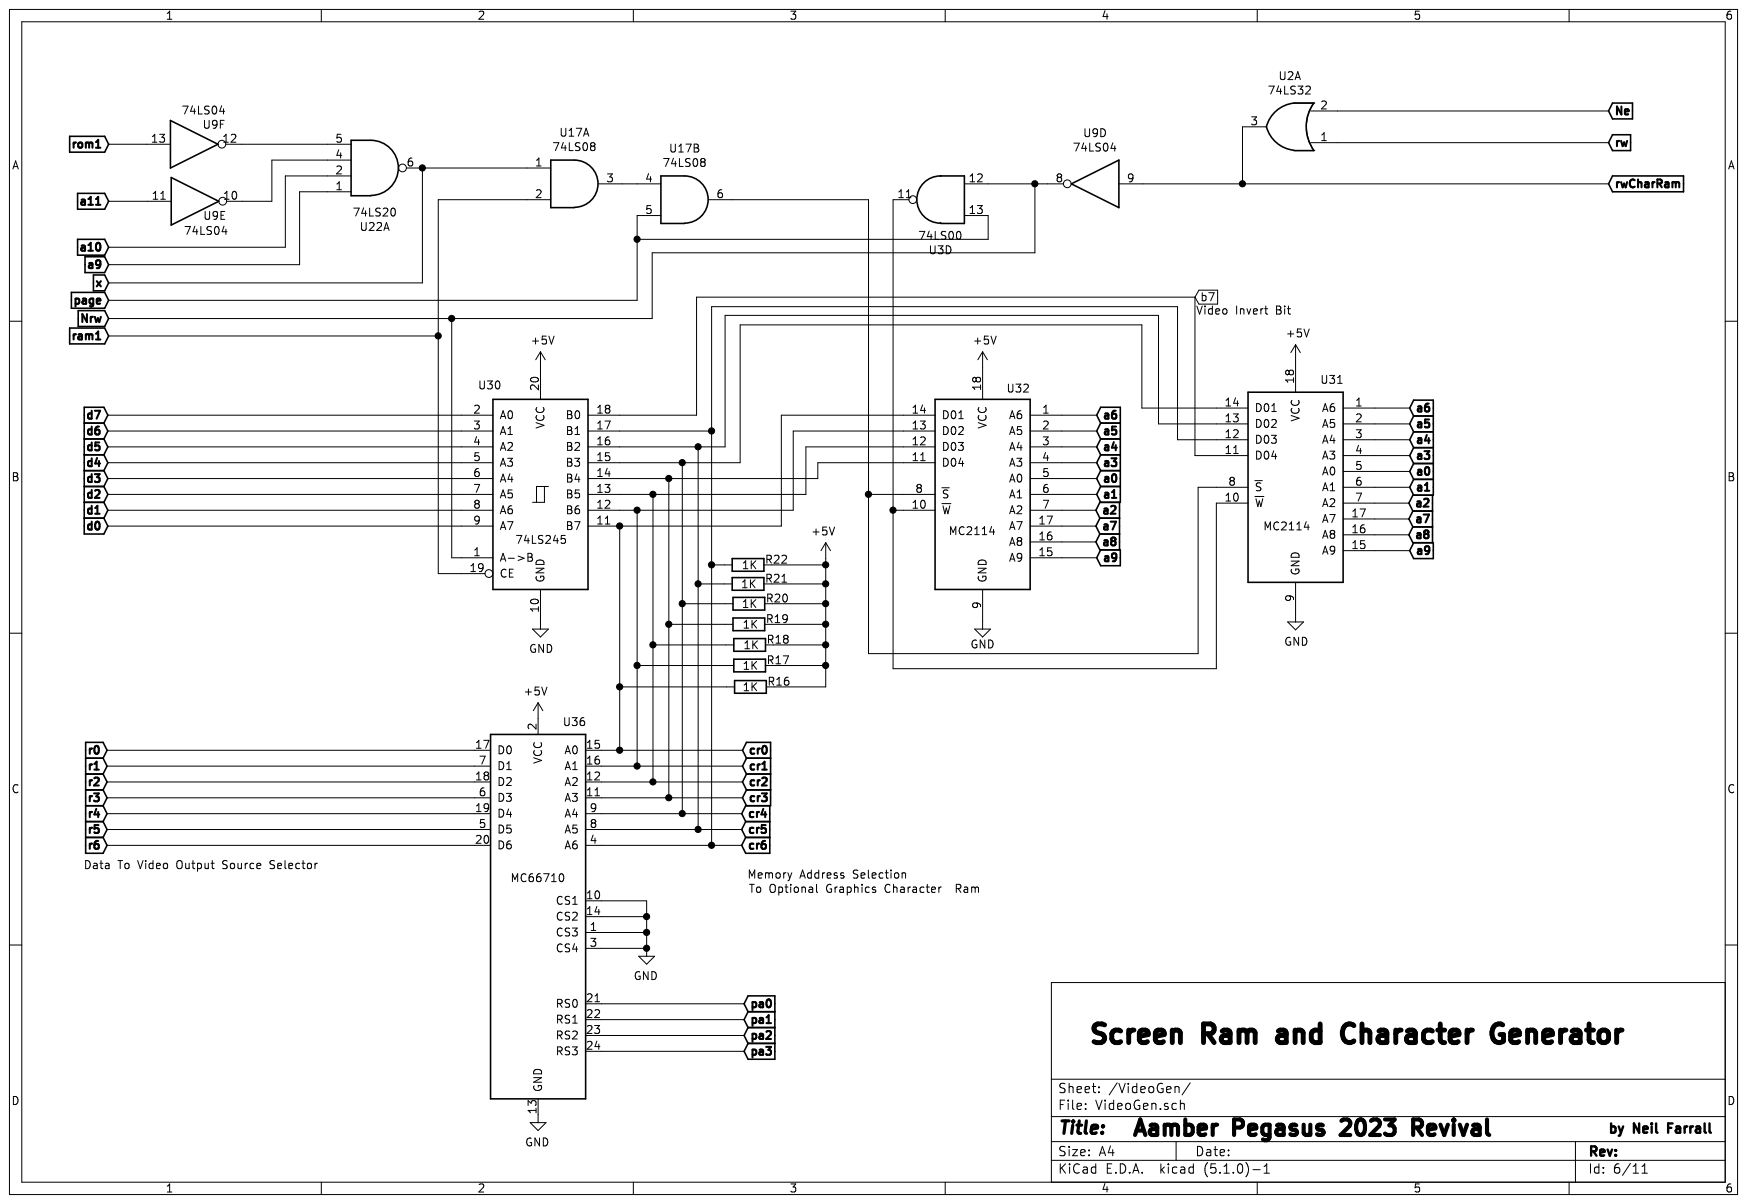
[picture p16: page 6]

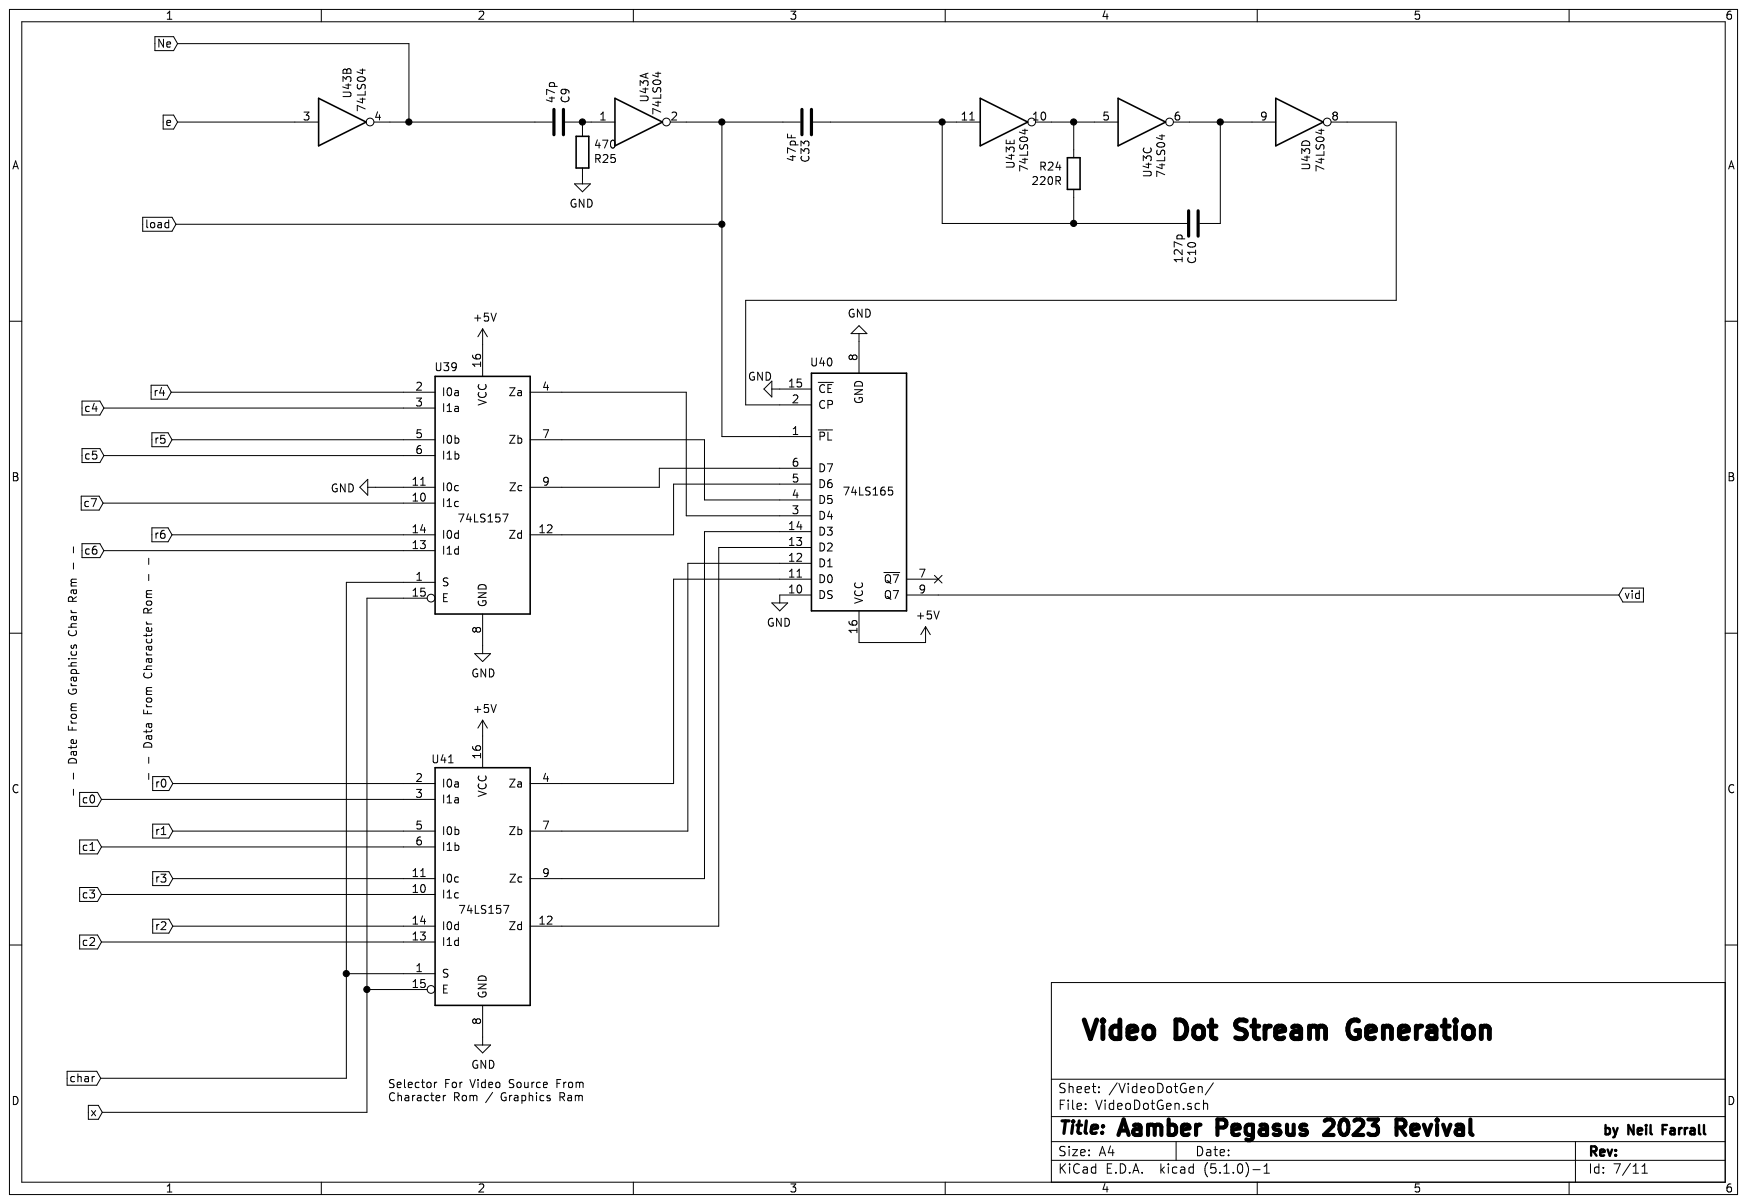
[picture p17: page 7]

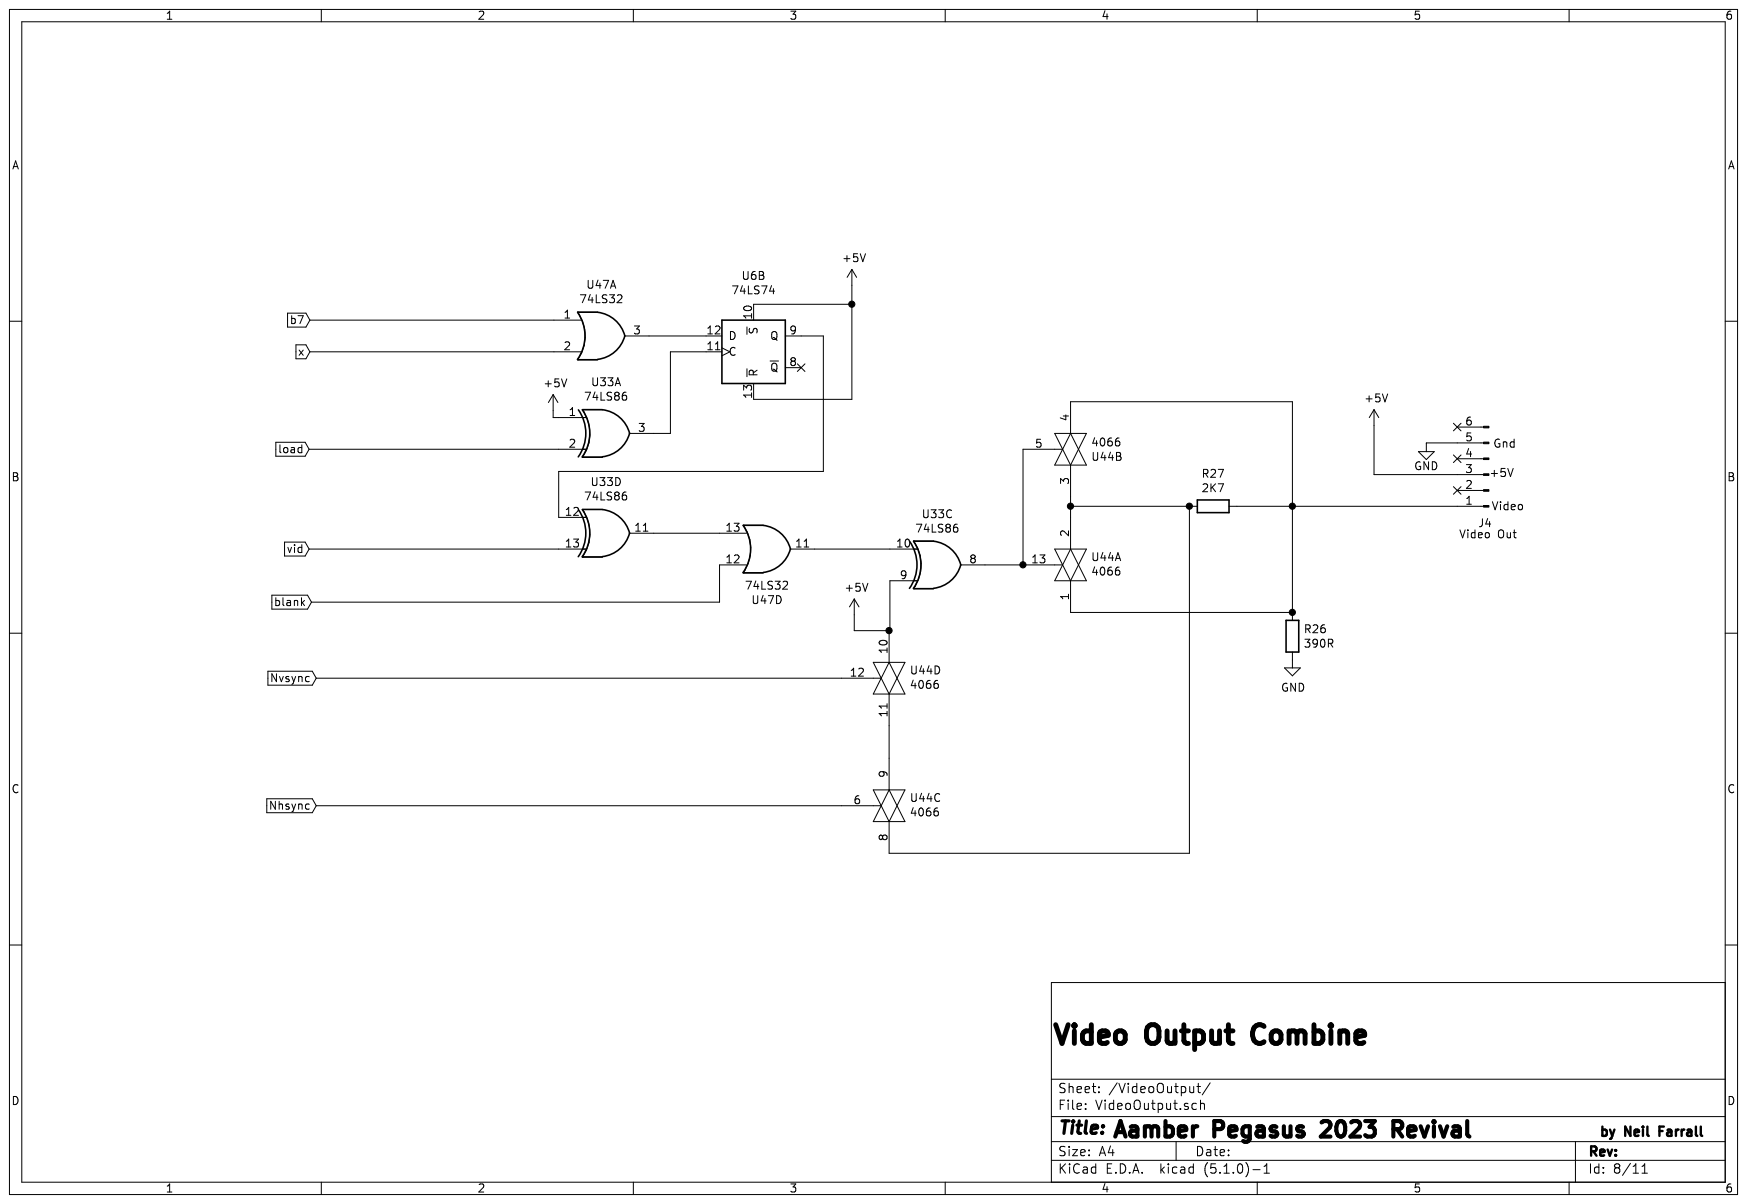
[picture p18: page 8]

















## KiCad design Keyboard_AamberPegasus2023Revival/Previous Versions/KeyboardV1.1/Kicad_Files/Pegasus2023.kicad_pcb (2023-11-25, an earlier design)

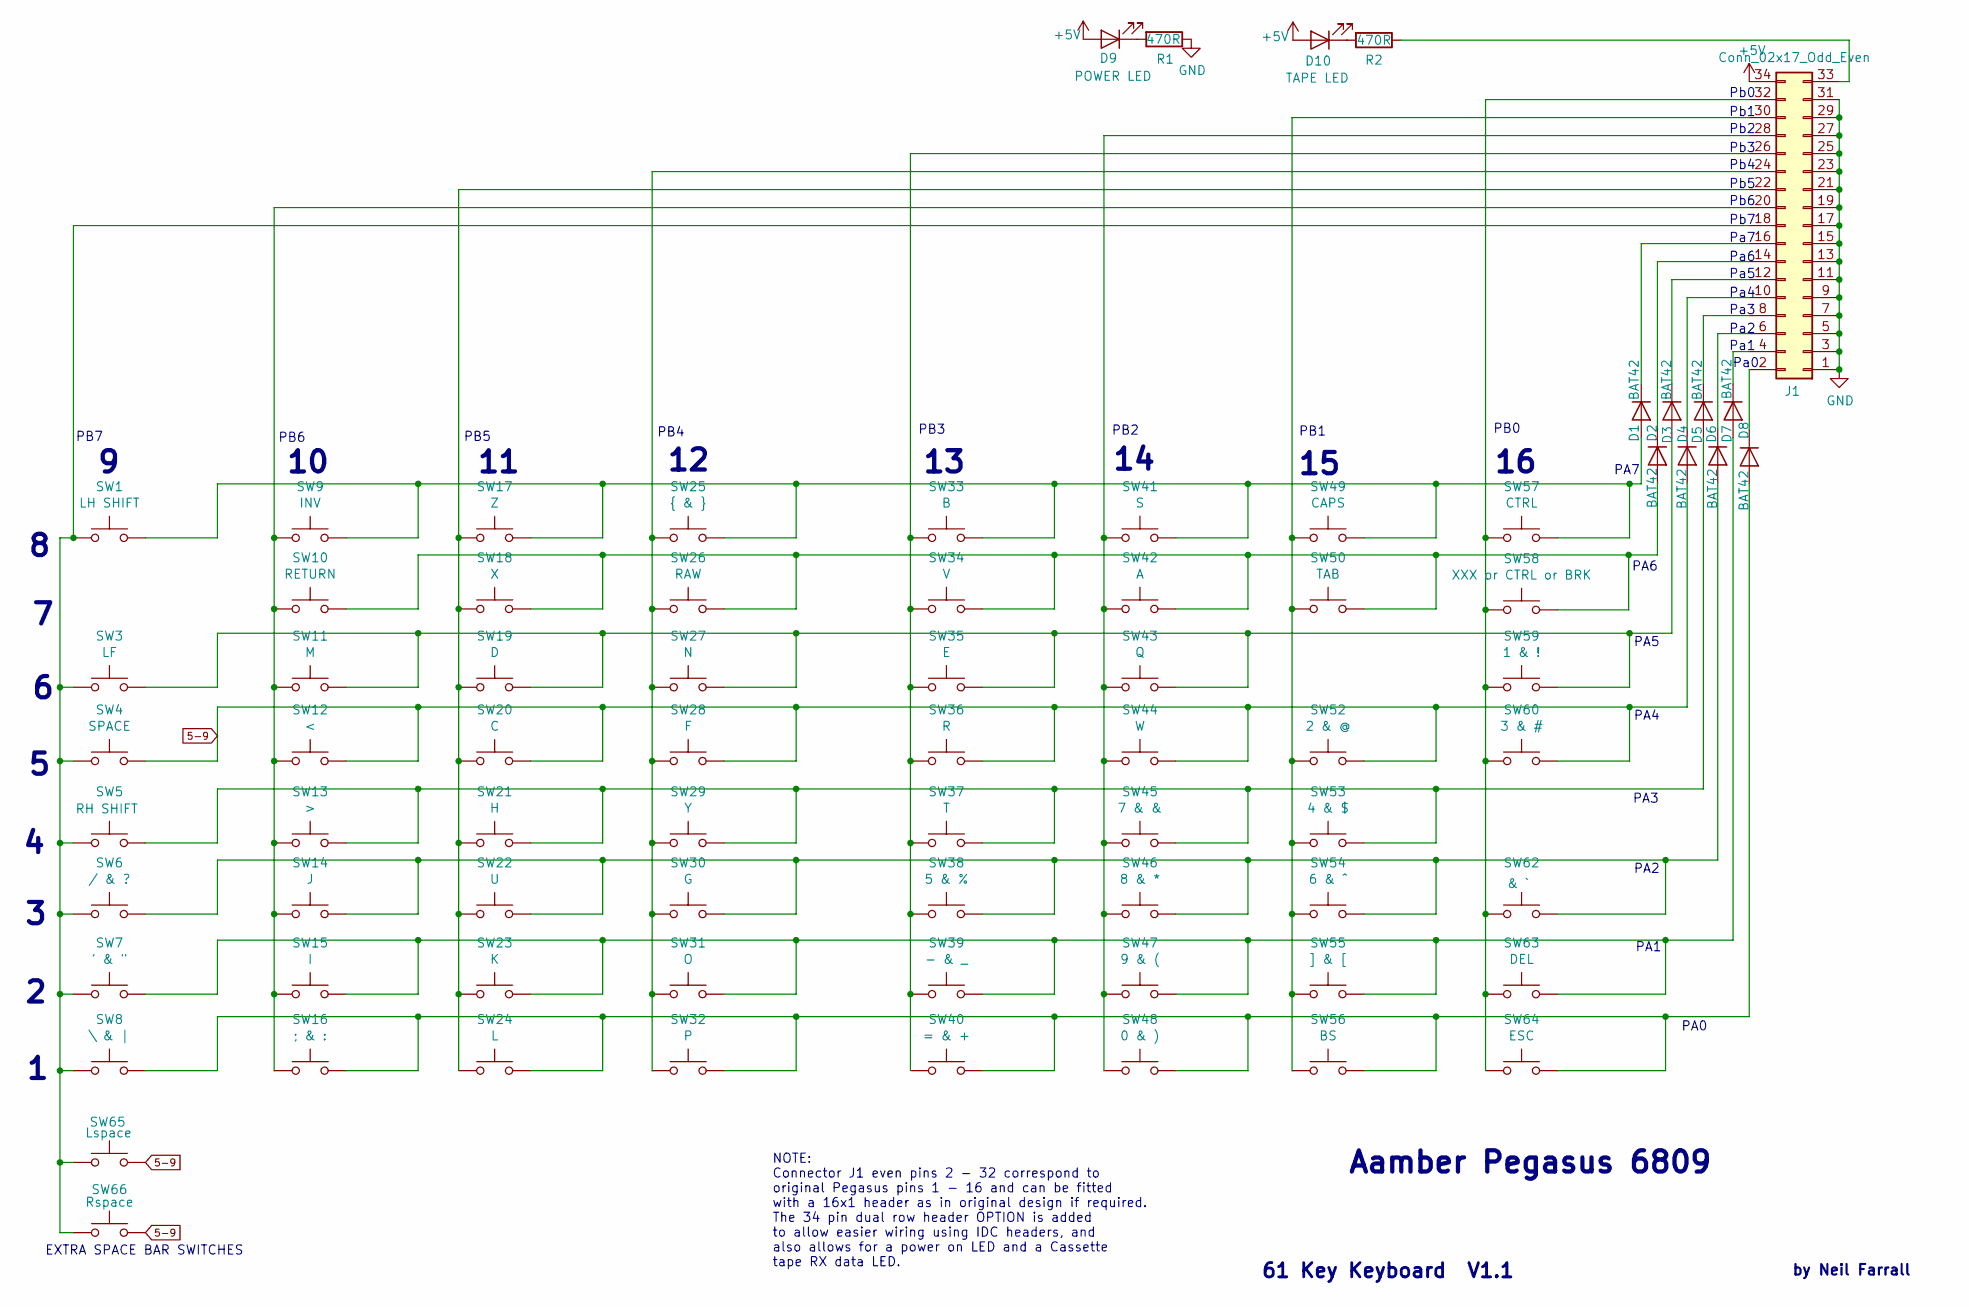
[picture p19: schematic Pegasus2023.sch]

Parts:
D1, D2, D3, D4, D5, D6, D7, D8: BAT42; D_DO-35_SOD27_P10.16mm_Horizontal
D9: POWER LED; LED_D5.0mm
D10: TAPE LED; LED_D5.0mm
J1: Conn_02x17_Odd_Even; PinHeader_2x17_P2.54mm_Vertical
R1, R2: 470R; R_Axial_DIN0309_L9.0mm_D3.2mm_P15.24mm_Horizontal
SW1: LH SHIFT; SW_Cherry_MX_1.00u_PCB
SW3: LF; SW_Cherry_MX_1.00u_PCB
SW4: SPACE; SW_Cherry_MX_1.00u_PCB
SW5: RH SHIFT; SW_Cherry_MX_1.00u_PCB
SW6: / & ?; SW_Cherry_MX_1.00u_PCB
SW7: ' & \"; SW_Cherry_MX_1.00u_PCB
SW8: \\ & |; SW_Cherry_MX_1.00u_PCB
SW9: INV; SW_Cherry_MX_1.00u_PCB
SW10: RETURN; SW_Cherry_MX_1.00u_PCB
SW11: M; SW_Cherry_MX_1.00u_PCB
SW12: <; SW_Cherry_MX_1.00u_PCB
SW13: >; SW_Cherry_MX_1.00u_PCB
SW14: J; SW_Cherry_MX_1.00u_PCB
SW15: I; SW_Cherry_MX_1.00u_PCB
SW16: ; & :; SW_Cherry_MX_1.00u_PCB
SW17: Z; SW_Cherry_MX_1.00u_PCB
SW18: X; SW_Cherry_MX_1.00u_PCB
SW19: D; SW_Cherry_MX_1.00u_PCB
SW20: C; SW_Cherry_MX_1.00u_PCB
SW21: H; SW_Cherry_MX_1.00u_PCB
SW22: U; SW_Cherry_MX_1.00u_PCB
SW23: K; SW_Cherry_MX_1.00u_PCB
SW24: L; SW_Cherry_MX_1.00u_PCB
SW25: { & }; SW_Cherry_MX_1.00u_PCB
SW26: RAW; SW_Cherry_MX_1.00u_PCB
SW27: N; SW_Cherry_MX_1.00u_PCB
SW28: F; SW_Cherry_MX_1.00u_PCB
SW29: Y; SW_Cherry_MX_1.00u_PCB
SW30: G; SW_Cherry_MX_1.00u_PCB
SW31: O; SW_Cherry_MX_1.00u_PCB
SW32: P; SW_Cherry_MX_1.00u_PCB
SW33: B; SW_Cherry_MX_1.00u_PCB
SW34: V; SW_Cherry_MX_1.00u_PCB
SW35: E; SW_Cherry_MX_1.00u_PCB
SW36: R; SW_Cherry_MX_1.00u_PCB
SW37: T; SW_Cherry_MX_1.00u_PCB
SW38: 5 & %; SW_Cherry_MX_1.00u_PCB
SW39: - & _; SW_Cherry_MX_1.00u_PCB
SW40: = & +; SW_Cherry_MX_1.00u_PCB
SW41: S; SW_Cherry_MX_1.00u_PCB
SW42: A; SW_Cherry_MX_1.00u_PCB
SW43: Q; SW_Cherry_MX_1.00u_PCB
SW44: W; SW_Cherry_MX_1.00u_PCB
SW45: 7 & &; SW_Cherry_MX_1.00u_PCB
SW46: 8 & *; SW_Cherry_MX_1.00u_PCB
SW47: 9 & (; SW_Cherry_MX_1.00u_PCB
SW48: 0 & ); SW_Cherry_MX_1.00u_PCB
SW49: CAPS; SW_Cherry_MX_1.00u_PCB
SW50: TAB; SW_Cherry_MX_1.00u_PCB
SW52: 2 & @; SW_Cherry_MX_1.00u_PCB
SW53: 4 & $; SW_Cherry_MX_1.00u_PCB
SW54: 6 & ^; SW_Cherry_MX_1.00u_PCB
SW55: ] & [; SW_Cherry_MX_1.00u_PCB
SW56: BS; SW_Cherry_MX_1.00u_PCB
SW57: CTRL; SW_Cherry_MX_1.00u_PCB
SW58: XXX or CTRL or BRK; SW_Cherry_MX_1.00u_PCB
SW59: 1 & !; SW_Cherry_MX_1.00u_PCB
SW60: 3 & #; SW_Cherry_MX_1.00u_PCB
SW62: ~ & `; SW_Cherry_MX_1.00u_PCB
SW63: DEL; SW_Cherry_MX_1.00u_PCB
SW64: ESC; SW_Cherry_MX_1.00u_PCB
SW65: Lspace; SW_Cherry_MX_1.00u_PCB
SW66: Rspace; SW_Cherry_MX_1.00u_PCB

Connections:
5-9: D4.2 (A), SW4.2, SW12.2, SW20.2, SW28.2, SW36.2, SW44.2, SW52.2, SW60.2, SW65.2, SW66.2
+5V: D9.2 (A), D10.2 (A), J1.34
GND: J1.1, J1.3, J1.5, J1.7, J1.9, J1.11, J1.13, J1.15, J1.17, J1.19, J1.21, J1.23, J1.25, J1.27, J1.29, J1.31, R1.1
unnamed: D1.1 (K), J1.16
unnamed: D1.2 (A), SW1.2, SW9.2, SW17.2, SW25.2, SW33.2, SW41.2, SW49.2, SW57.2
unnamed: D2.1 (K), J1.14
unnamed: D2.2 (A), SW10.2, SW18.2, SW26.2, SW34.2, SW42.2, SW50.2, SW58.2
unnamed: D3.1 (K), J1.12
unnamed: D3.2 (A), SW3.2, SW11.2, SW19.2, SW27.2, SW35.2, SW43.2, SW59.2
unnamed: D4.1 (K), J1.10
unnamed: D5.1 (K), J1.8
unnamed: D5.2 (A), SW5.2, SW13.2, SW21.2, SW29.2, SW37.2, SW45.2, SW53.2
unnamed: D6.1 (K), J1.6
unnamed: D6.2 (A), SW6.2, SW14.2, SW22.2, SW30.2, SW38.2, SW46.2, SW54.2, SW62.2
unnamed: D7.1 (K), J1.4
unnamed: D7.2 (A), SW7.2, SW15.2, SW23.2, SW31.2, SW39.2, SW47.2, SW55.2, SW63.2
unnamed: D8.1 (K), J1.2
unnamed: D8.2 (A), SW8.2, SW16.2, SW24.2, SW32.2, SW40.2, SW48.2, SW56.2, SW64.2
unnamed: D9.1 (K), R1.2
unnamed: D10.1 (K), R2.2
unnamed: J1.18, SW1.1, SW3.1, SW4.1, SW5.1, SW6.1, SW7.1, SW8.1, SW65.1, SW66.1
unnamed: J1.20, SW9.1, SW10.1, SW11.1, SW12.1, SW13.1, SW14.1, SW15.1, SW16.1
unnamed: J1.22, SW17.1, SW18.1, SW19.1, SW20.1, SW21.1, SW22.1, SW23.1, SW24.1
unnamed: J1.24, SW25.1, SW26.1, SW27.1, SW28.1, SW29.1, SW30.1, SW31.1, SW32.1
unnamed: J1.26, SW33.1, SW34.1, SW35.1, SW36.1, SW37.1, SW38.1, SW39.1, SW40.1
unnamed: J1.28, SW41.1, SW42.1, SW43.1, SW44.1, SW45.1, SW46.1, SW47.1, SW48.1
unnamed: J1.30, SW49.1, SW50.1, SW52.1, SW53.1, SW54.1, SW55.1, SW56.1
unnamed: J1.32, SW57.1, SW58.1, SW59.1, SW60.1, SW62.1, SW63.1, SW64.1
unnamed: J1.33, R2.1

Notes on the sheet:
by Neil Farrall
Aamber Pegasus 6809
Pa0
Pa1
Pa2
Pa3
Pa4
Pa5
Pa6
Pa7
Pb0
Pb1
Pb2
Pb3
Pb4
Pb5
Pb6
Pb7
PB7
PB6
PB5
PB4
PB3
PB2
PB1
PB0
PA0
PA1
PA2
PA3
PA4
PA5
PA6
PA7
61 Key Keyboard V1.1
EXTRA SPACE BAR SWITCHES
NOTE: Connector J1 even pins 2 - 32 correspond to original Pegasus pins 1 - 16 and can be fitted with a 16x1 header as in original design if required. The 34 pin dual row header OPTION is added to allow easier wiring using IDC headers, and also allows for a power on LED and a Cassette tape RX data 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

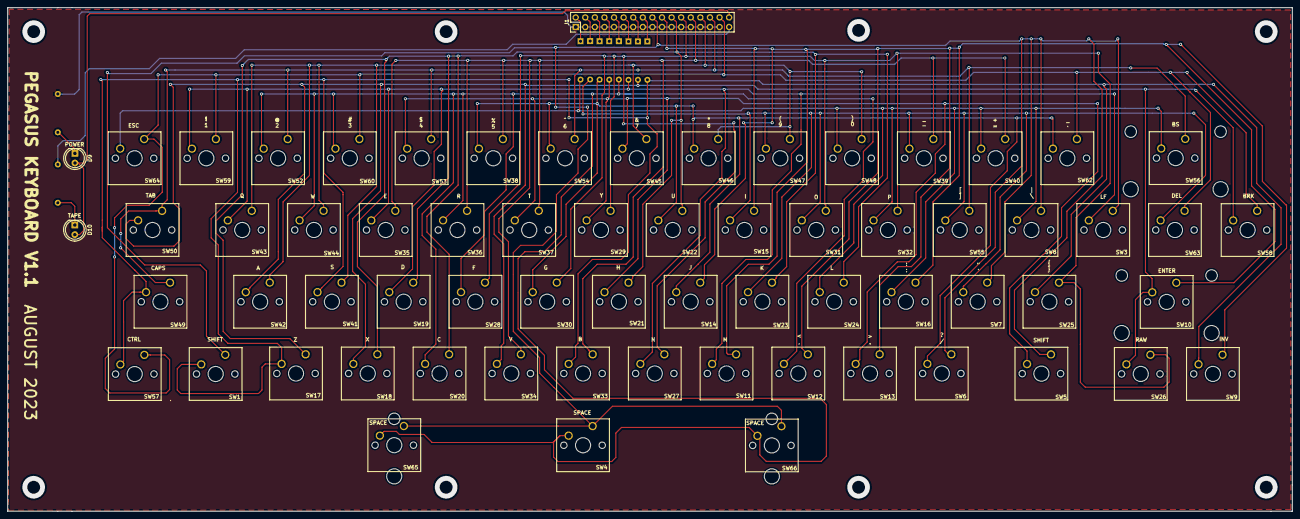
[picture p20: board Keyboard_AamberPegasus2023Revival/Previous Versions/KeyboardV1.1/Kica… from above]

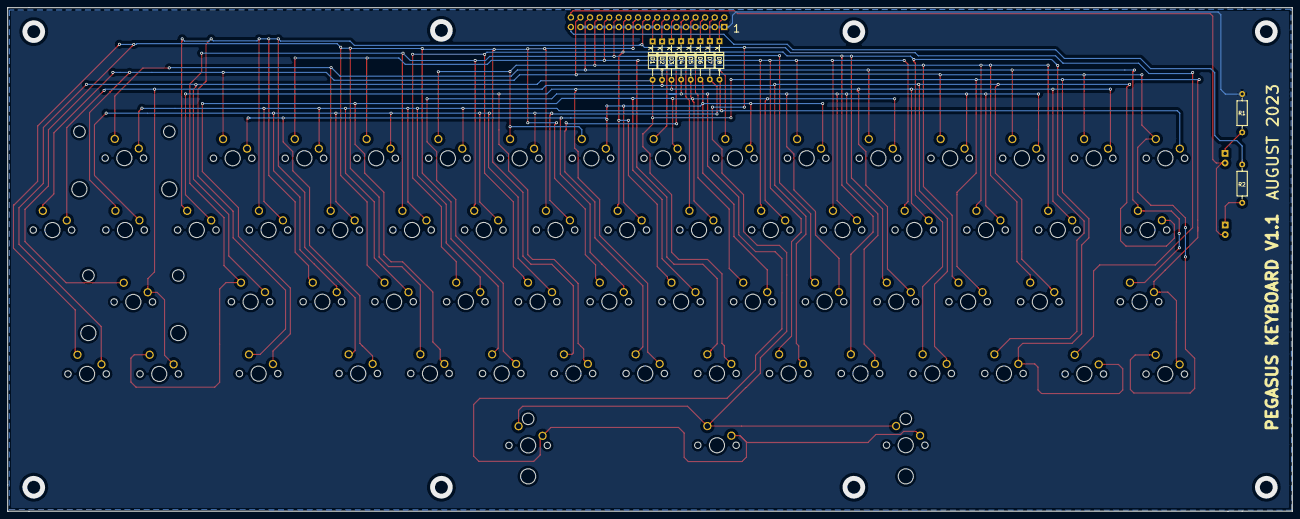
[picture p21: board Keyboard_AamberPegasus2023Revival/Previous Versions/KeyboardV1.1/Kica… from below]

Board: 2 copper layers, 340.2 x 133.4 mm, 76 parts (10 on the bottom side), 29 nets.

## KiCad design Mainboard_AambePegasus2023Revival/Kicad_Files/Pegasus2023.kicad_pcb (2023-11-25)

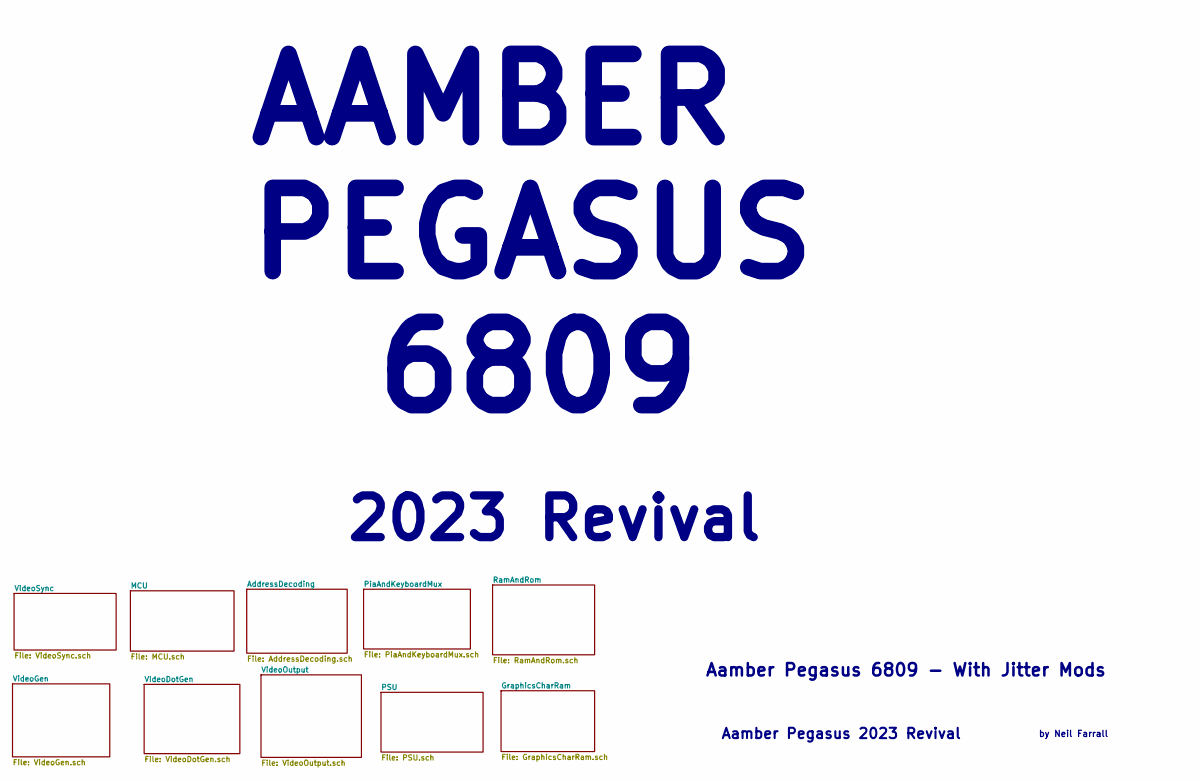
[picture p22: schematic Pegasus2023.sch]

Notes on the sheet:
Aamber Pegasus 2023 Revival
by Neil Farrall
Aamber Pegasus 6809 - With Jitter Mods
AAMBER PEGASUS 6809
2023 Revival

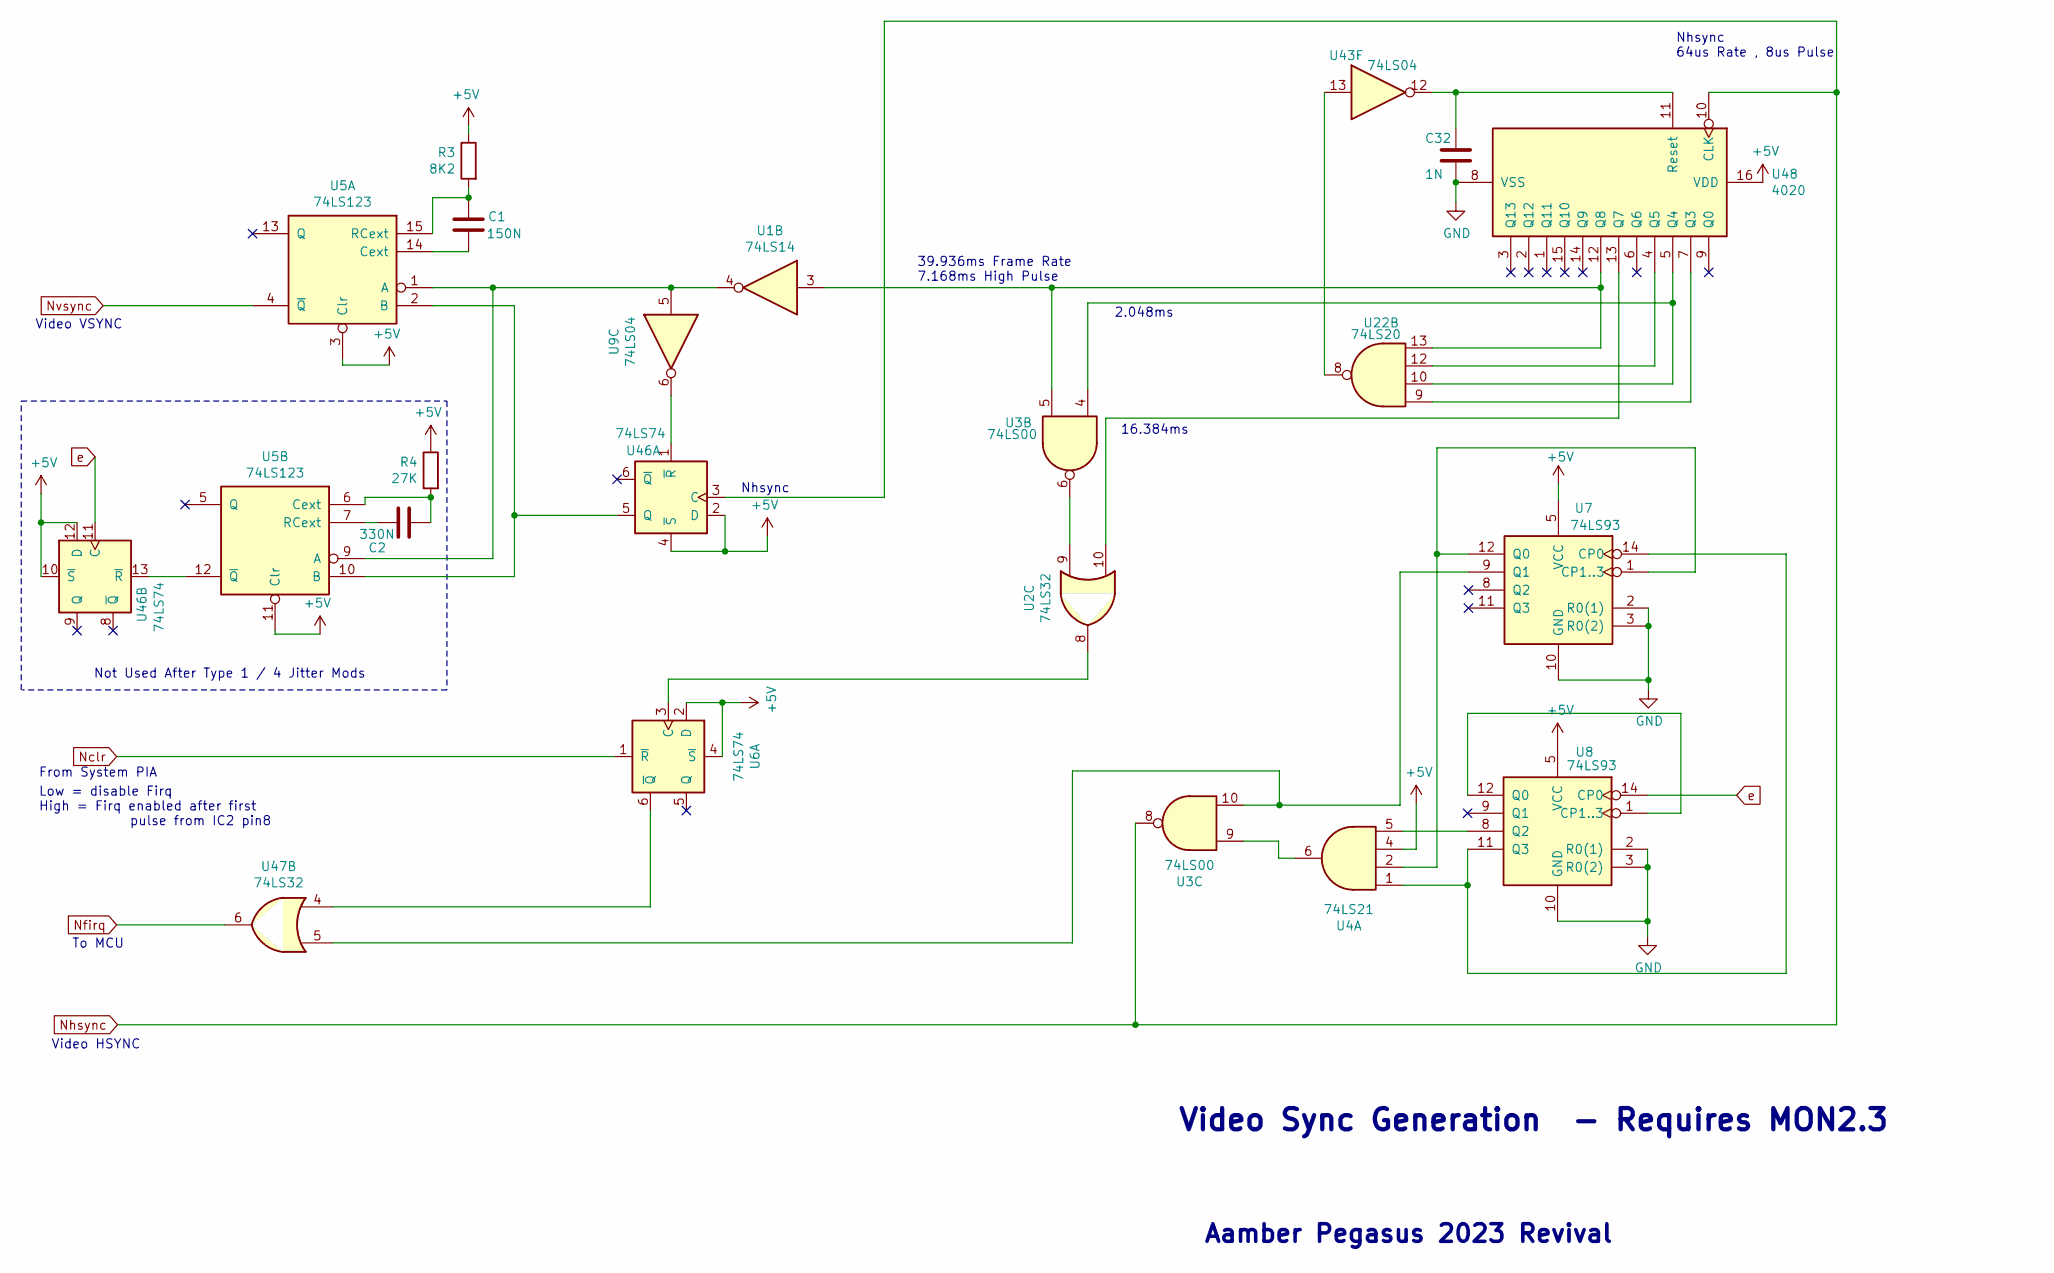
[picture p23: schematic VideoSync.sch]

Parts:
C1: 150N; C_Rect_L7.5mm_W6.5mm_P5.00mm
C2: 330N; C_Rect_L7.5mm_W6.5mm_P5.00mm
C32: 1N; C_Disc_D4.3mm_W1.9mm_P5.00mm
R3: 8K2; R_Axial_DIN0411_L9.9mm_D3.6mm_P15.24mm_Horizontal
R4: 27K; R_Axial_DIN0411_L9.9mm_D3.6mm_P15.24mm_Horizontal
U1: 74LS14; DIP-14_W7.62mm_Socket_LongPads
U2, U47: 74LS32; DIP-14_W7.62mm_Socket_LongPads
U3: 74LS00; DIP-14_W7.62mm_Socket_LongPads
U4: 74LS21; DIP-14_W7.62mm_Socket_LongPads
U5: 74LS123; DIP-16_W7.62mm_Socket_LongPads
U6, U46: 74LS74; DIP-14_W7.62mm_Socket_LongPads
U7, U8: 74LS93; DIP-14_W7.62mm_Socket_LongPads
U9, U43: 74LS04; DIP-14_W7.62mm_Socket_LongPads
U22: 74LS20; DIP-14_W7.62mm_Socket_LongPads
U48: 4020; DIP-16_W7.62mm_Socket_LongPads

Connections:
Nclr: U6.1 (~R); also elsewhere on the board
unnamed: C1.1, R3.2, U5.15 (RCext)
unnamed: C1.2, U5.14 (Cext)
unnamed: C2.1, R4.2, U5.6 (Cext)
unnamed: C2.2, U5.7 (RCext)
unnamed: C32.1, U43.12, U48.11 (Reset)
unnamed: U1.3, U3.5, U22.13, U48.12 (Q8)
unnamed: U1.4, U5.1 (A), U5.9 (A), U9.5
unnamed: U2.8, U6.3 (C)
unnamed: U2.9, U3.6
unnamed: U2.10, U48.13 (Q7)
unnamed: U3.9, U4.6
unnamed: U3.10, U7.9 (Q1), U47.5
unnamed: U4.1, U7.14 (CP0), U8.11 (Q3)
unnamed: U4.2, U7.1 (CP1..3), U7.12 (Q0)
unnamed: U4.5, U8.8 (Q2)
unnamed: U8.1 (CP1..3), U8.12 (Q0)
unnamed: U22.8, U43.13
unnamed: U22.9, U48.7 (Q3)
unnamed: U3.4, U22.10, U48.5 (Q4)
unnamed: U22.12, U48.4 (Q5)
unnamed: U9.6, U46.1 (~R)
unnamed: U5.2 (B), U5.10 (B), U46.5 (Q)
unnamed: U5.12 (~Q), U46.13 (~R)
unnamed: U6.6 (~Q), U47.4
Nfirq: U47.6; also elsewhere on the board
Nhsync: U3.8, U46.3 (C), U48.10 (CLK); also elsewhere on the board
Nvsync: U5.4 (~Q); also elsewhere on the board
e: U8.14 (CP0), U46.11 (C); also elsewhere on the board

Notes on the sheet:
Aamber Pegasus 2023 Revival
Video Sync Generation - Requires MON2.3
From System PIA
To MCU
Video HSYNC
Video VSYNC
Not Used After Type 1 / 4 Jitter Mods
Nhsync
Nhsync 64us Rate , 8us Pulse
Low = disable Firq High = Firq enabled after first pulse from IC2 pin8
39.936ms Frame Rate 7.168ms High Pulse
2.048ms
16.384ms

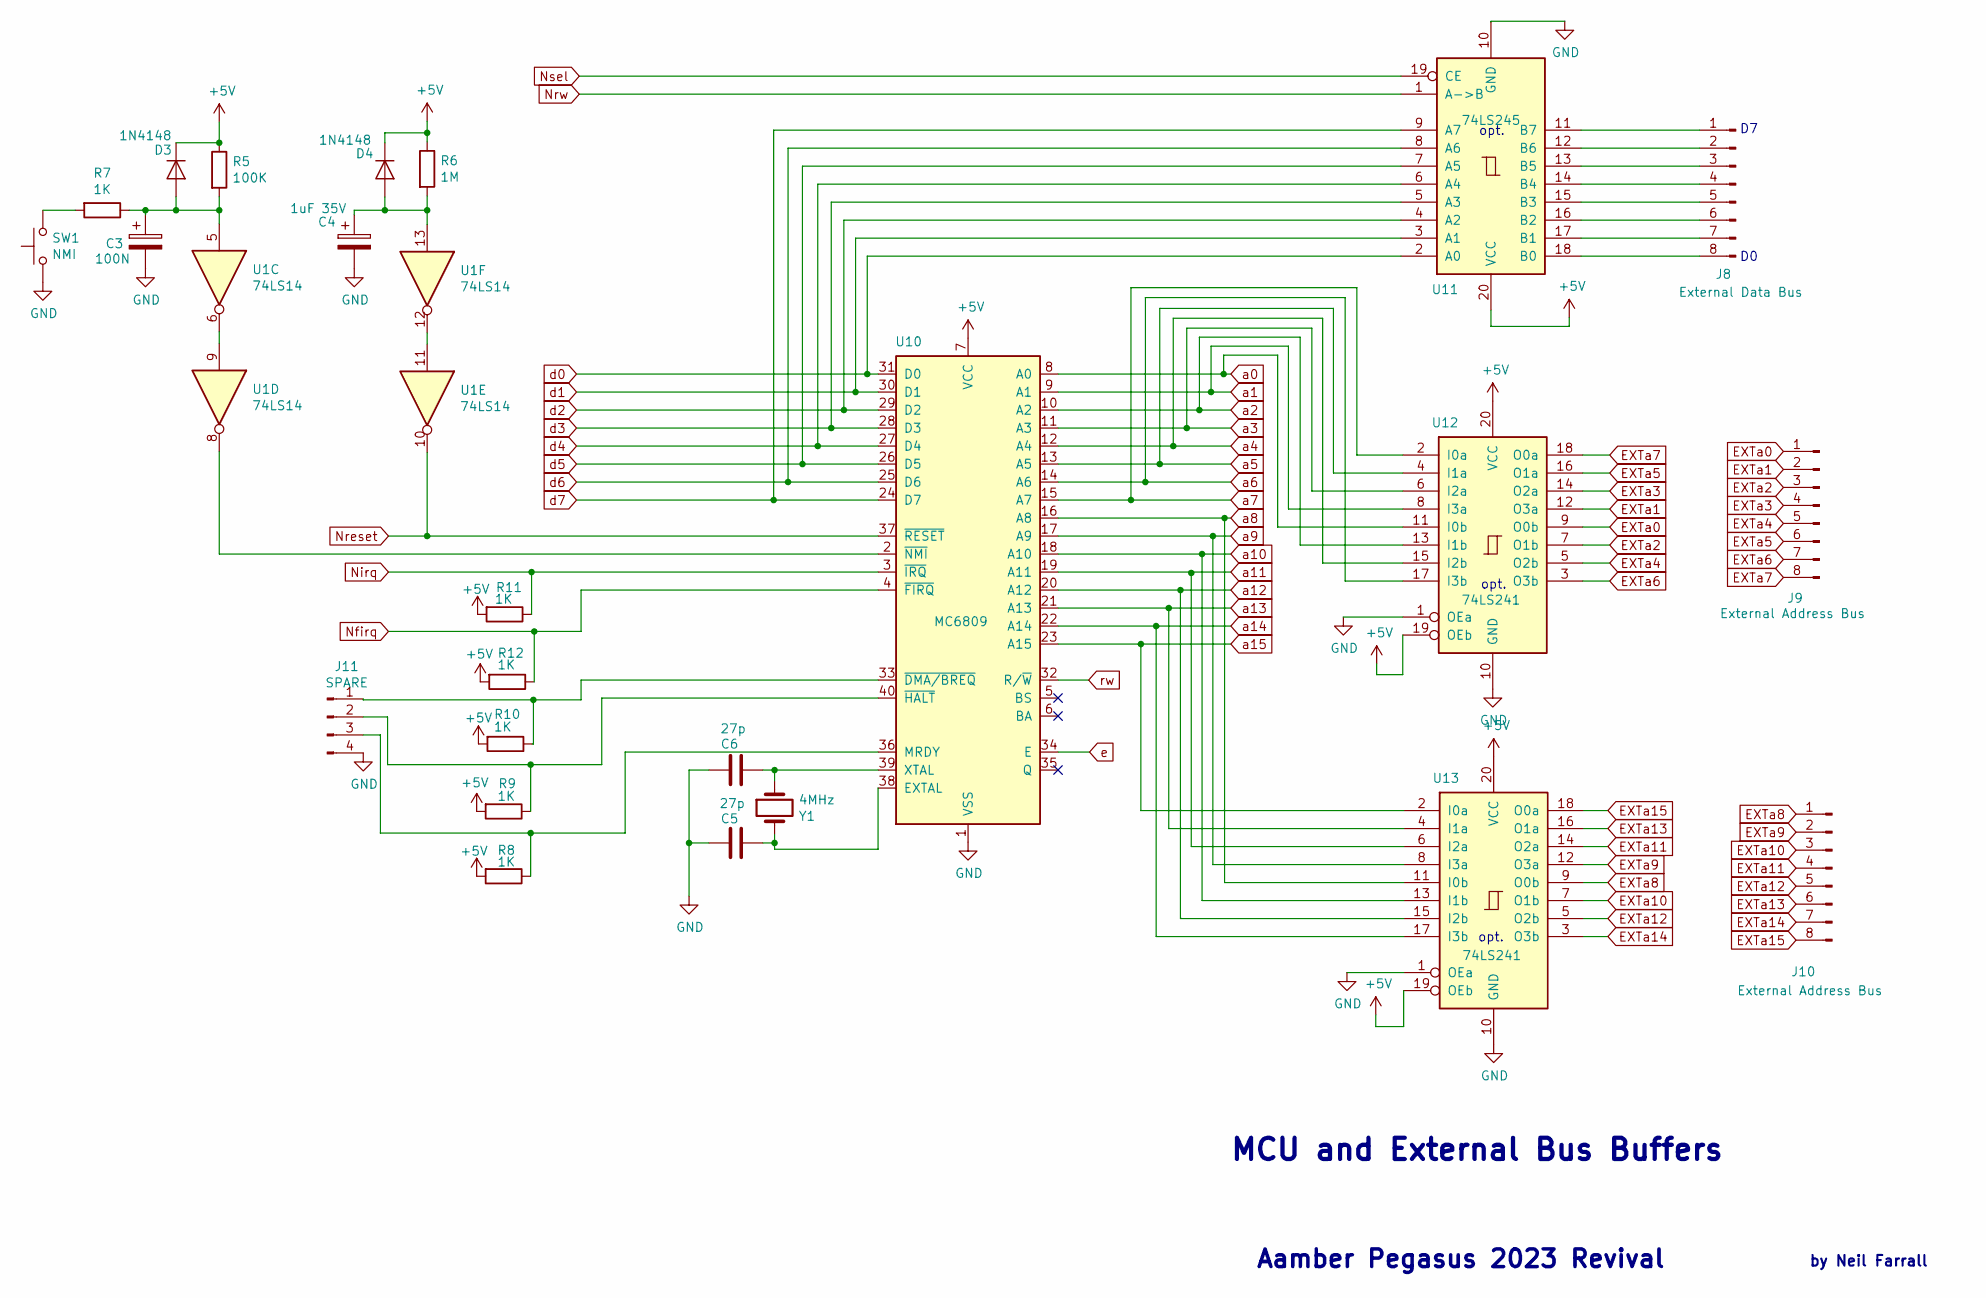
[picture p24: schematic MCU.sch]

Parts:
C3: 100N; C_Disc_D11.0mm_W5.0mm_P5.00mm
C4: 1uF 35V; CP_Radial_D5.0mm_P2.50mm
C5, C6: 27p; C_Disc_D3.8mm_W2.6mm_P2.50mm
D3, D4: 1N4148; D_DO-15_P12.70mm_Horizontal
J8: External Data Bus; PinHeader_1x08_P2.54mm_Horizontal
J9, J10: External Address Bus; PinHeader_1x08_P2.54mm_Horizontal
J11: SPARE; PinHeader_1x04_P2.54mm_Vertical
R5: 100K; R_Axial_DIN0411_L9.9mm_D3.6mm_P15.24mm_Horizontal
R6: 1M; R_Axial_DIN0411_L9.9mm_D3.6mm_P15.24mm_Horizontal
R7, R8, R9, R10, R11, R12: 1K; R_Axial_DIN0411_L9.9mm_D3.6mm_P15.24mm_Horizontal
SW1: NMI; SW_PUSH_6mm_H5mm
U1: 74LS14; DIP-14_W7.62mm_Socket_LongPads
U10: MC6809; DIP-40_W15.24mm_Socket_LongPads
U11: 74LS245; DIP-20_W7.62mm_Socket_LongPads
U12, U13: 74LS241; DIP-20_W7.62mm_Socket_LongPads
Y1: 4MHz; Crystal_HC49-U_Horizontal_1EP_style2

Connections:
EXTa0: J9.1, U12.9 (O0b)
EXTa1: J9.2, U12.12 (O3a)
EXTa2: J9.3, U12.7 (O1b)
EXTa3: J9.4, U12.14 (O2a)
EXTa4: J9.5, U12.5 (O2b)
EXTa5: J9.6, U12.16 (O1a)
EXTa6: J9.7, U12.3 (O3b)
EXTa7: J9.8, U12.18 (O0a)
EXTa8: J10.1, U13.9 (O0b)
EXTa9: J10.2, U13.12 (O3a)
EXTa10: J10.3, U13.7 (O1b)
EXTa11: J10.4, U13.14 (O2a)
EXTa12: J10.5, U13.5 (O2b)
EXTa13: J10.6, U13.16 (O1a)
EXTa14: J10.7, U13.3 (O3b)
EXTa15: J10.8, U13.18 (O0a)
unnamed: C3.1, D3.2 (A), R5.2, R7.1, U1.5
unnamed: C4.1, D4.2 (A), R6.2, U1.13
unnamed: C5.1, U10.38 (EXTAL), Y1.2
unnamed: C6.1, U10.39 (XTAL), Y1.1
unnamed: J8.1, U11.11 (B7)
unnamed: J8.2, U11.12 (B6)
unnamed: J8.3, U11.13 (B5)
unnamed: J8.4, U11.14 (B4)
unnamed: J8.5, U11.15 (B3)
unnamed: J8.6, U11.16 (B2)
unnamed: J8.7, U11.17 (B1)
unnamed: J8.8, U11.18 (B0)
unnamed: J11.1, R10.1, U10.33 (~DMA/BREQ)
unnamed: J11.2, R9.1, U10.40 (~HALT)
unnamed: J11.3, R8.1, U10.36 (MRDY)
unnamed: R7.2, SW1.2
unnamed: U1.6, U1.9
unnamed: U1.8, U10.2 (~NMI)
unnamed: U1.11, U1.12
Nfirq: R12.1, U10.4 (~FIRQ); also elsewhere on the board
Nirq: R11.1, U10.3 (~IRQ); also elsewhere on the board
Nreset: U1.10, U10.37 (~RESET); also elsewhere on the board
Nrw: U11.1 (A->B); also elsewhere on the board
Nsel: U11.19 (CE); also elsewhere on the board
a0: U10.8 (A0), U12.11 (I0b); also elsewhere on the board
a1: U10.9 (A1), U12.8 (I3a); also elsewhere on the board
a2: U10.10 (A2), U12.13 (I1b); also elsewhere on the board
a3: U10.11 (A3), U12.6 (I2a); also elsewhere on the board
a4: U10.12 (A4), U12.15 (I2b); also elsewhere on the board
a5: U10.13 (A5), U12.4 (I1a); also elsewhere on the board
a6: U10.14 (A6), U12.17 (I3b); also elsewhere on the board
a7: U10.15 (A7), U12.2 (I0a); also elsewhere on the board
a8: U10.16 (A8), U13.11 (I0b); also elsewhere on the board
a9: U10.17 (A9), U13.8 (I3a); also elsewhere on the board
a10: U10.18 (A10), U13.13 (I1b); also elsewhere on the board
a11: U10.19 (A11), U13.6 (I2a); also elsewhere on the board
a12: U10.20 (A12), U13.15 (I2b); also elsewhere on the board
a13: U10.21 (A13), U13.4 (I1a); also elsewhere on the board
a14: U10.22 (A14), U13.17 (I3b); also elsewhere on the board
a15: U10.23 (A15), U13.2 (I0a); also elsewhere on the board
d0: U10.31 (D0), U11.2 (A0); also elsewhere on the board
d1: U10.30 (D1), U11.3 (A1); also elsewhere on the board
d2: U10.29 (D2), U11.4 (A2); also elsewhere on the board
d3: U10.28 (D3), U11.5 (A3); also elsewhere on the board
d4: U10.27 (D4), U11.6 (A4); also elsewhere on the board
d5: U10.26 (D5), U11.7 (A5); also elsewhere on the board
d6: U10.25 (D6), U11.8 (A6); also elsewhere on the board
d7: U10.24 (D7), U11.9 (A7); also elsewhere on the board
e: U10.34 (E); also elsewhere on the board
rw: U10.32 (R/~W); also elsewhere on the board

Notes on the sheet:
opt.
MCU and External Bus Buffers
Aamber Pegasus 2023 Revival
by Neil Farrall

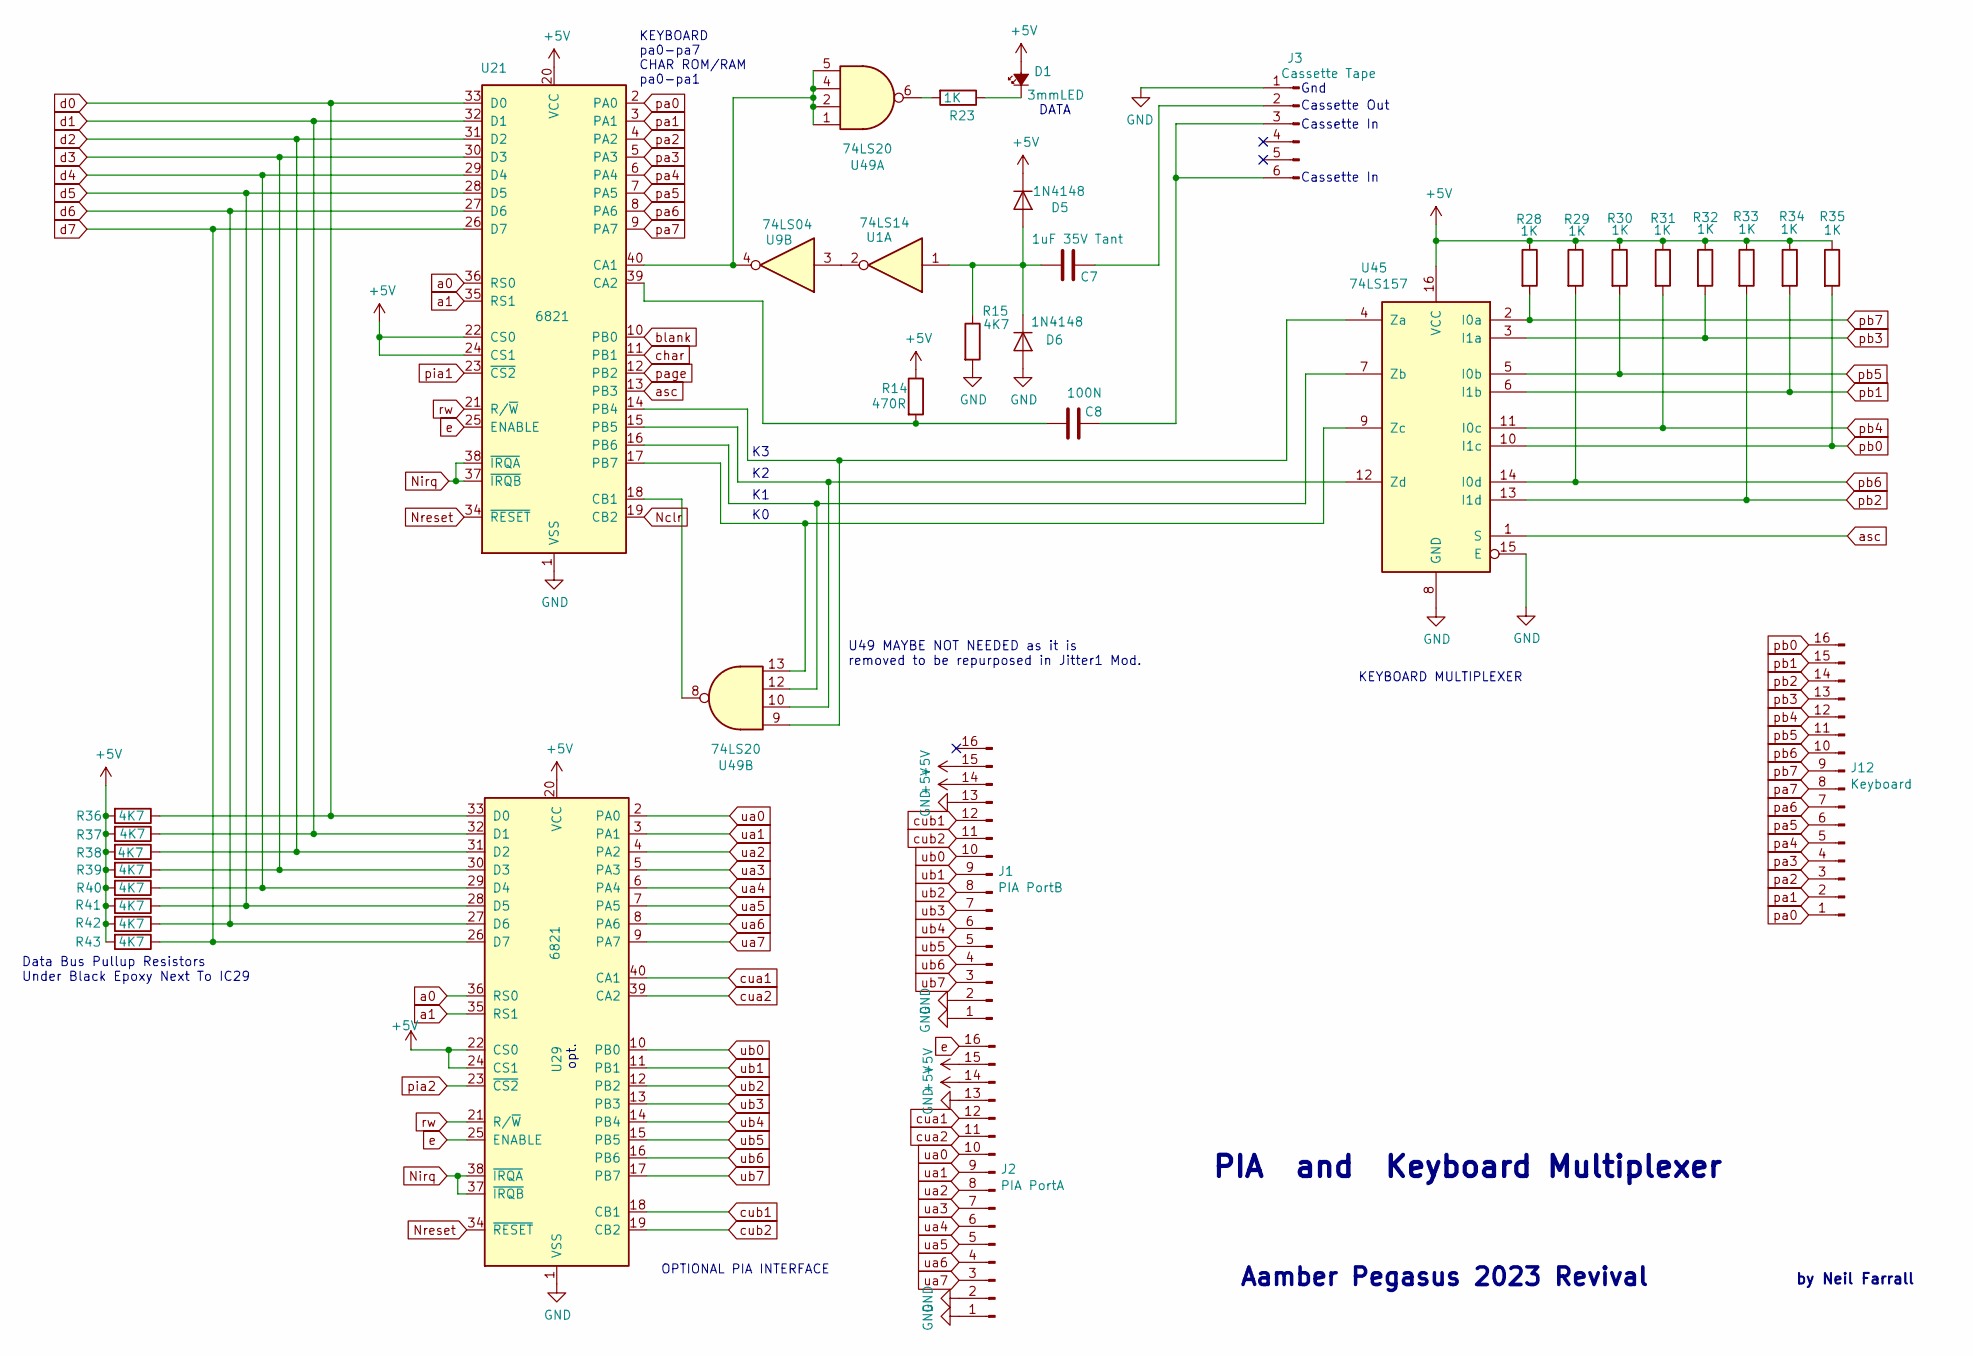
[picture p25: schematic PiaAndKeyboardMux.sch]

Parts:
C7: 1uF 35V Tant; CP_Radial_Tantal_D5.0mm_P2.50mm
C8: 100N; C_Disc_D11.0mm_W5.0mm_P5.00mm
D1: 3mmLED; LED_D5.0mm
D5, D6: 1N4148; D_DO-15_P12.70mm_Horizontal
J1: PIA PortB; PinHeader_1x16_P2.54mm_Horizontal
J2: PIA PortA; PinHeader_1x16_P2.54mm_Horizontal
J3: Cassette Tape; PinHeader_1x06_P2.54mm_Horizontal
J12: Keyboard; PinHeader_1x16_P2.54mm_Horizontal
R14: 470R; R_Axial_DIN0411_L9.9mm_D3.6mm_P15.24mm_Horizontal
R15, R36, R37, R38, R39, R40, R41, R42, R43: 4K7; R_Axial_DIN0411_L9.9mm_D3.6mm_P15.24mm_Horizontal
R23, R28, R29, R30, R31, R32, R33, R34, R35: 1K; R_Axial_DIN0411_L9.9mm_D3.6mm_P15.24mm_Horizontal
U1: 74LS14; DIP-14_W7.62mm_Socket_LongPads
U9: 74LS04; DIP-14_W7.62mm_Socket_LongPads
U21, U29: 6821; DIP-40_W15.24mm_Socket_LongPads
U45: 74LS157; DIP-16_W7.62mm_Socket_LongPads
U49: 74LS20; DIP-14_W7.62mm_Socket_LongPads

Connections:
Nclr: U21.19 (CB2); also elsewhere on the board
unnamed: C7.1, J3.2
unnamed: C7.2, D5.2 (A), D6.1 (K), R15.1, U1.1
unnamed: C8.1, J3.3, J3.6
unnamed: C8.2, R14.2, U21.39 (CA2)
unnamed: D1.1 (K), R23.1
unnamed: R23.2, U49.6
unnamed: U1.2, U9.3
unnamed: U21.14 (PB4), U45.4 (Za), U49.9
unnamed: U21.15 (PB5), U45.12 (Zd), U49.10
unnamed: U21.16 (PB6), U45.7 (Zb), U49.12
unnamed: U21.17 (PB7), U45.9 (Zc), U49.13
unnamed: U21.18 (CB1), U49.8
unnamed: U9.4, U21.40 (CA1), U49.1, U49.2, U49.4, U49.5
Nirq: U21.37 (~IRQB), U21.38 (~IRQA), U29.37 (~IRQB), U29.38 (~IRQA); also elsewhere on the board
Nreset: U21.34 (~RESET), U29.34 (~RESET); also elsewhere on the board
a0: U21.36 (RS0), U29.36 (RS0); also elsewhere on the board
a1: U21.35 (RS1), U29.35 (RS1); also elsewhere on the board
asc: U21.13 (PB3), U45.1 (S)
blank: U21.10 (PB0); also elsewhere on the board
char: U21.11 (PB1); also elsewhere on the board
cua1: J2.12, U29.40 (CA1)
cua2: J2.11, U29.39 (CA2)
cub1: J1.12, U29.18 (CB1)
cub2: J1.11, U29.19 (CB2)
d0: R36.1, U21.33 (D0), U29.33 (D0); also elsewhere on the board
d1: R37.1, U21.32 (D1), U29.32 (D1); also elsewhere on the board
d2: R38.1, U21.31 (D2), U29.31 (D2); also elsewhere on the board
d3: R39.1, U21.30 (D3), U29.30 (D3); also elsewhere on the board
d4: R40.1, U21.29 (D4), U29.29 (D4); also elsewhere on the board
d5: R41.1, U21.28 (D5), U29.28 (D5); also elsewhere on the board
d6: R42.1, U21.27 (D6), U29.27 (D6); also elsewhere on the board
d7: R43.1, U21.26 (D7), U29.26 (D7); also elsewhere on the board
e: J2.16, U21.25 (ENABLE), U29.25 (ENABLE); also elsewhere on the board
pa0: J12.1, U21.2 (PA0); also elsewhere on the board
pa1: J12.2, U21.3 (PA1); also elsewhere on the board
pa2: J12.3, U21.4 (PA2); also elsewhere on the board
pa3: J12.4, U21.5 (PA3); also elsewhere on the board
pa4: J12.5, U21.6 (PA4)
pa5: J12.6, U21.7 (PA5)
pa6: J12.7, U21.8 (PA6)
pa7: J12.8, U21.9 (PA7)
page: U21.12 (PB2); also elsewhere on the board
pb0: J12.16, R35.2, U45.10 (I1c)
pb1: J12.15, R34.2, U45.6 (I1b)
pb2: J12.14, R33.2, U45.13 (I1d)
pb3: J12.13, R32.2, U45.3 (I1a)
pb4: J12.12, R31.2, U45.11 (I0c)
pb5: J12.11, R30.2, U45.5 (I0b)
pb6: J12.10, R29.2, U45.14 (I0d)
pb7: J12.9, R28.2, U45.2 (I0a)
pia1: U21.23 (~CS2); also elsewhere on the board
pia2: U29.23 (~CS2); also elsewhere on the board
rw: U21.21 (R/~W), U29.21 (R/~W); also elsewhere on the board
ua0: J2.10, U29.2 (PA0)
ua1: J2.9, U29.3 (PA1)
ua2: J2.8, U29.4 (PA2)
ua3: J2.7, U29.5 (PA3)
ua4: J2.6, U29.6 (PA4)
ua5: J2.5, U29.7 (PA5)
ua6: J2.4, U29.8 (PA6)
ua7: J2.3, U29.9 (PA7)
ub0: J1.10, U29.10 (PB0)
ub1: J1.9, U29.11 (PB1)
ub2: J1.8, U29.12 (PB2)
ub3: J1.7, U29.13 (PB3)
ub4: J1.6, U29.14 (PB4)
ub5: J1.5, U29.15 (PB5)
ub6: J1.4, U29.16 (PB6)
ub7: J1.3, U29.17 (PB7)

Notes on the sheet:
Aamber Pegasus 2023 Revival
by Neil Farrall
PIA and Keyboard Multiplexer
KEYBOARD MULTIPLEXER
OPTIONAL PIA INTERFACE
opt.
U49 MAYBE NOT NEEDED as it is removed to be repurposed in Jitter1 Mod.
Cassette Out
Cassette In
Gnd
Data Bus Pullup Resistors Under Black Epoxy Next To IC29
KEYBOARD pa0-pa7 CHAR ROM/RAM pa0-pa1
DATA

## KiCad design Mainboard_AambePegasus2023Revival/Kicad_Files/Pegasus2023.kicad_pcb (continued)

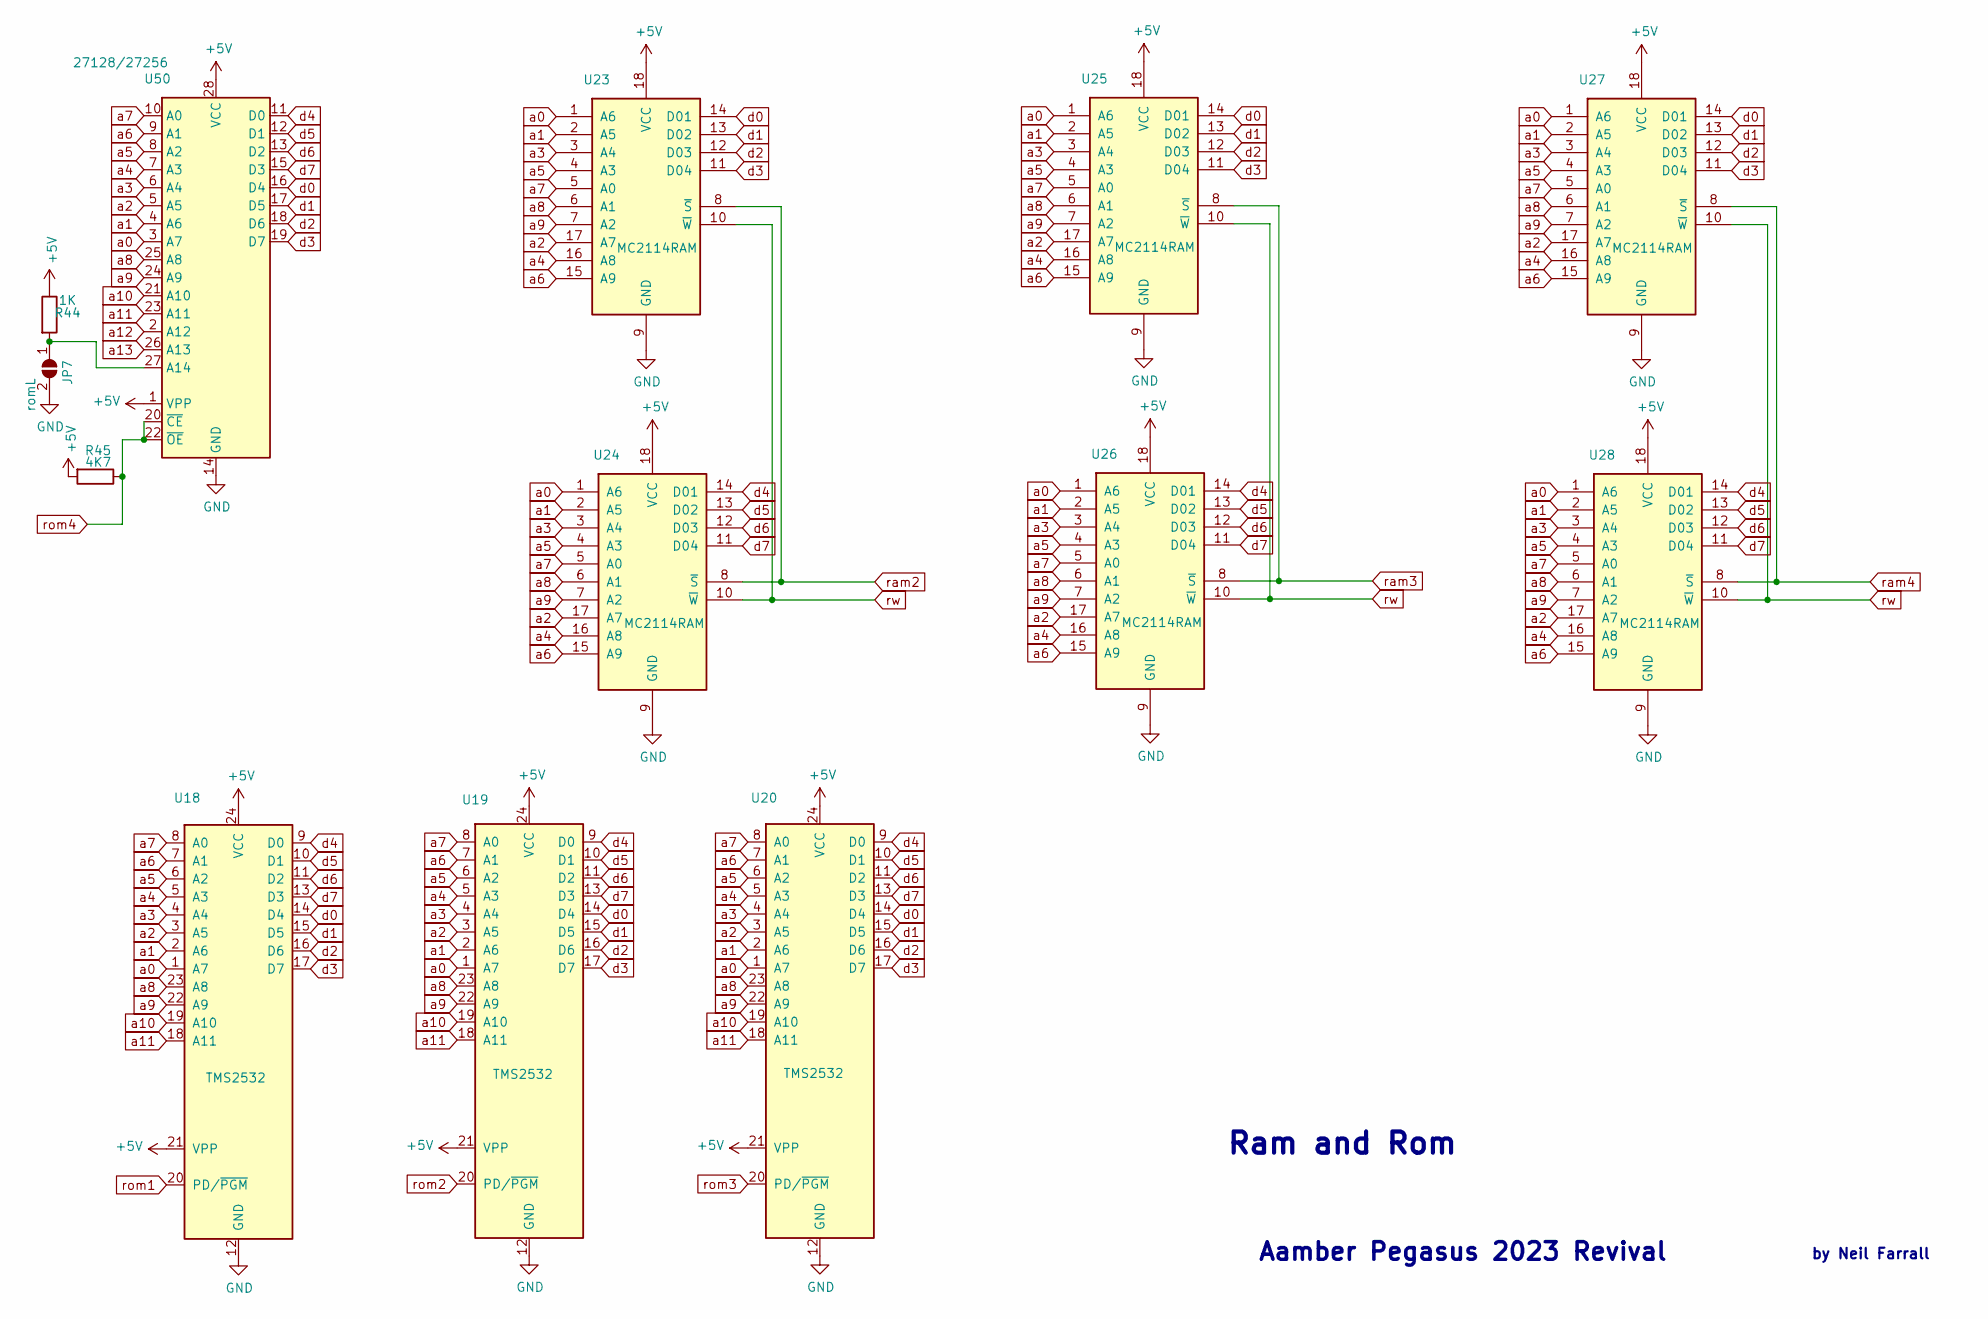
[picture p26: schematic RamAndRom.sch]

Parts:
JP7: romL; SolderJumper-2_P1.3mm_Open_Pad1.0x1.5mm
R44: 1K; R_Axial_DIN0411_L9.9mm_D3.6mm_P15.24mm_Horizontal
R45: 4K7; R_Axial_DIN0411_L9.9mm_D3.6mm_P15.24mm_Horizontal
U18, U19, U20: TMS2532; DIP-24_W15.24mm_Socket_LongPads
U23, U24, U25, U26, U27, U28: MC2114RAM; DIP-18_W7.62mm_Socket_LongPads
U50: 27128/27256; DIP-28_W15.24mm

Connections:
unnamed: JP7.1 (A), R44.2, U50.27 (A14)
a0: U18.1 (A7), U19.1 (A7), U20.1 (A7), U23.1 (A6), U24.1 (A6), U25.1 (A6), U26.1 (A6), U27.1 (A6), U28.1 (A6), U50.3 (A7); also elsewhere on the board
a1: U18.2 (A6), U19.2 (A6), U20.2 (A6), U23.2 (A5), U24.2 (A5), U25.2 (A5), U26.2 (A5), U27.2 (A5), U28.2 (A5), U50.4 (A6); also elsewhere on the board
a2: U18.3 (A5), U19.3 (A5), U20.3 (A5), U23.17 (A7), U24.17 (A7), U25.17 (A7), U26.17 (A7), U27.17 (A7), U28.17 (A7), U50.5 (A5); also elsewhere on the board
a3: U18.4 (A4), U19.4 (A4), U20.4 (A4), U23.3 (A4), U24.3 (A4), U25.3 (A4), U26.3 (A4), U27.3 (A4), U28.3 (A4), U50.6 (A4); also elsewhere on the board
a4: U18.5 (A3), U19.5 (A3), U20.5 (A3), U23.16 (A8), U24.16 (A8), U25.16 (A8), U26.16 (A8), U27.16 (A8), U28.16 (A8), U50.7 (A3); also elsewhere on the board
a5: U18.6 (A2), U19.6 (A2), U20.6 (A2), U23.4 (A3), U24.4 (A3), U25.4 (A3), U26.4 (A3), U27.4 (A3), U28.4 (A3), U50.8 (A2); also elsewhere on the board
a6: U18.7 (A1), U19.7 (A1), U20.7 (A1), U23.15 (A9), U24.15 (A9), U25.15 (A9), U26.15 (A9), U27.15 (A9), U28.15 (A9), U50.9 (A1); also elsewhere on the board
a7: U18.8 (A0), U19.8 (A0), U20.8 (A0), U23.5 (A0), U24.5 (A0), U25.5 (A0), U26.5 (A0), U27.5 (A0), U28.5 (A0), U50.10 (A0); also elsewhere on the board
a8: U18.23 (A8), U19.23 (A8), U20.23 (A8), U23.6 (A1), U24.6 (A1), U25.6 (A1), U26.6 (A1), U27.6 (A1), U28.6 (A1), U50.25 (A8); also elsewhere on the board
a9: U18.22 (A9), U19.22 (A9), U20.22 (A9), U23.7 (A2), U24.7 (A2), U25.7 (A2), U26.7 (A2), U27.7 (A2), U28.7 (A2), U50.24 (A9); also elsewhere on the board
a10: U18.19 (A10), U19.19 (A10), U20.19 (A10), U50.21 (A10); also elsewhere on the board
a11: U18.18 (A11), U19.18 (A11), U20.18 (A11), U50.23 (A11); also elsewhere on the board
a12: U50.2 (A12); also elsewhere on the board
a13: U50.26 (A13); also elsewhere on the board
d0: U18.14 (D4), U19.14 (D4), U20.14 (D4), U23.14 (D01), U25.14 (D01), U27.14 (D01), U50.16 (D4); also elsewhere on the board
d1: U18.15 (D5), U19.15 (D5), U20.15 (D5), U23.13 (D02), U25.13 (D02), U27.13 (D02), U50.17 (D5); also elsewhere on the board
d2: U18.16 (D6), U19.16 (D6), U20.16 (D6), U23.12 (D03), U25.12 (D03), U27.12 (D03), U50.18 (D6); also elsewhere on the board
d3: U18.17 (D7), U19.17 (D7), U20.17 (D7), U23.11 (D04), U25.11 (D04), U27.11 (D04), U50.19 (D7); also elsewhere on the board
d4: U18.9 (D0), U19.9 (D0), U20.9 (D0), U24.14 (D01), U26.14 (D01), U28.14 (D01), U50.11 (D0); also elsewhere on the board
d5: U18.10 (D1), U19.10 (D1), U20.10 (D1), U24.13 (D02), U26.13 (D02), U28.13 (D02), U50.12 (D1); also elsewhere on the board
d6: U18.11 (D2), U19.11 (D2), U20.11 (D2), U24.12 (D03), U26.12 (D03), U28.12 (D03), U50.13 (D2); also elsewhere on the board
d7: U18.13 (D3), U19.13 (D3), U20.13 (D3), U24.11 (D04), U26.11 (D04), U28.11 (D04), U50.15 (D3); also elsewhere on the board
ram2: U23.8 (~S), U24.8 (~S); also elsewhere on the board
ram3: U25.8 (~S), U26.8 (~S); also elsewhere on the board
ram4: U27.8 (~S), U28.8 (~S); also elsewhere on the board
rom1: U18.20 (PD/~PGM); also elsewhere on the board
rom2: U19.20 (PD/~PGM); also elsewhere on the board
rom3: U20.20 (PD/~PGM); also elsewhere on the board
rom4: R45.1, U50.20 (~CE), U50.22 (~OE); also elsewhere on the board
rw: U23.10 (~W), U24.10 (~W), U25.10 (~W), U26.10 (~W), U27.10 (~W), U28.10 (~W); also elsewhere on the board

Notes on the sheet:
Aamber Pegasus 2023 Revival
by Neil Farrall
Ram and Rom

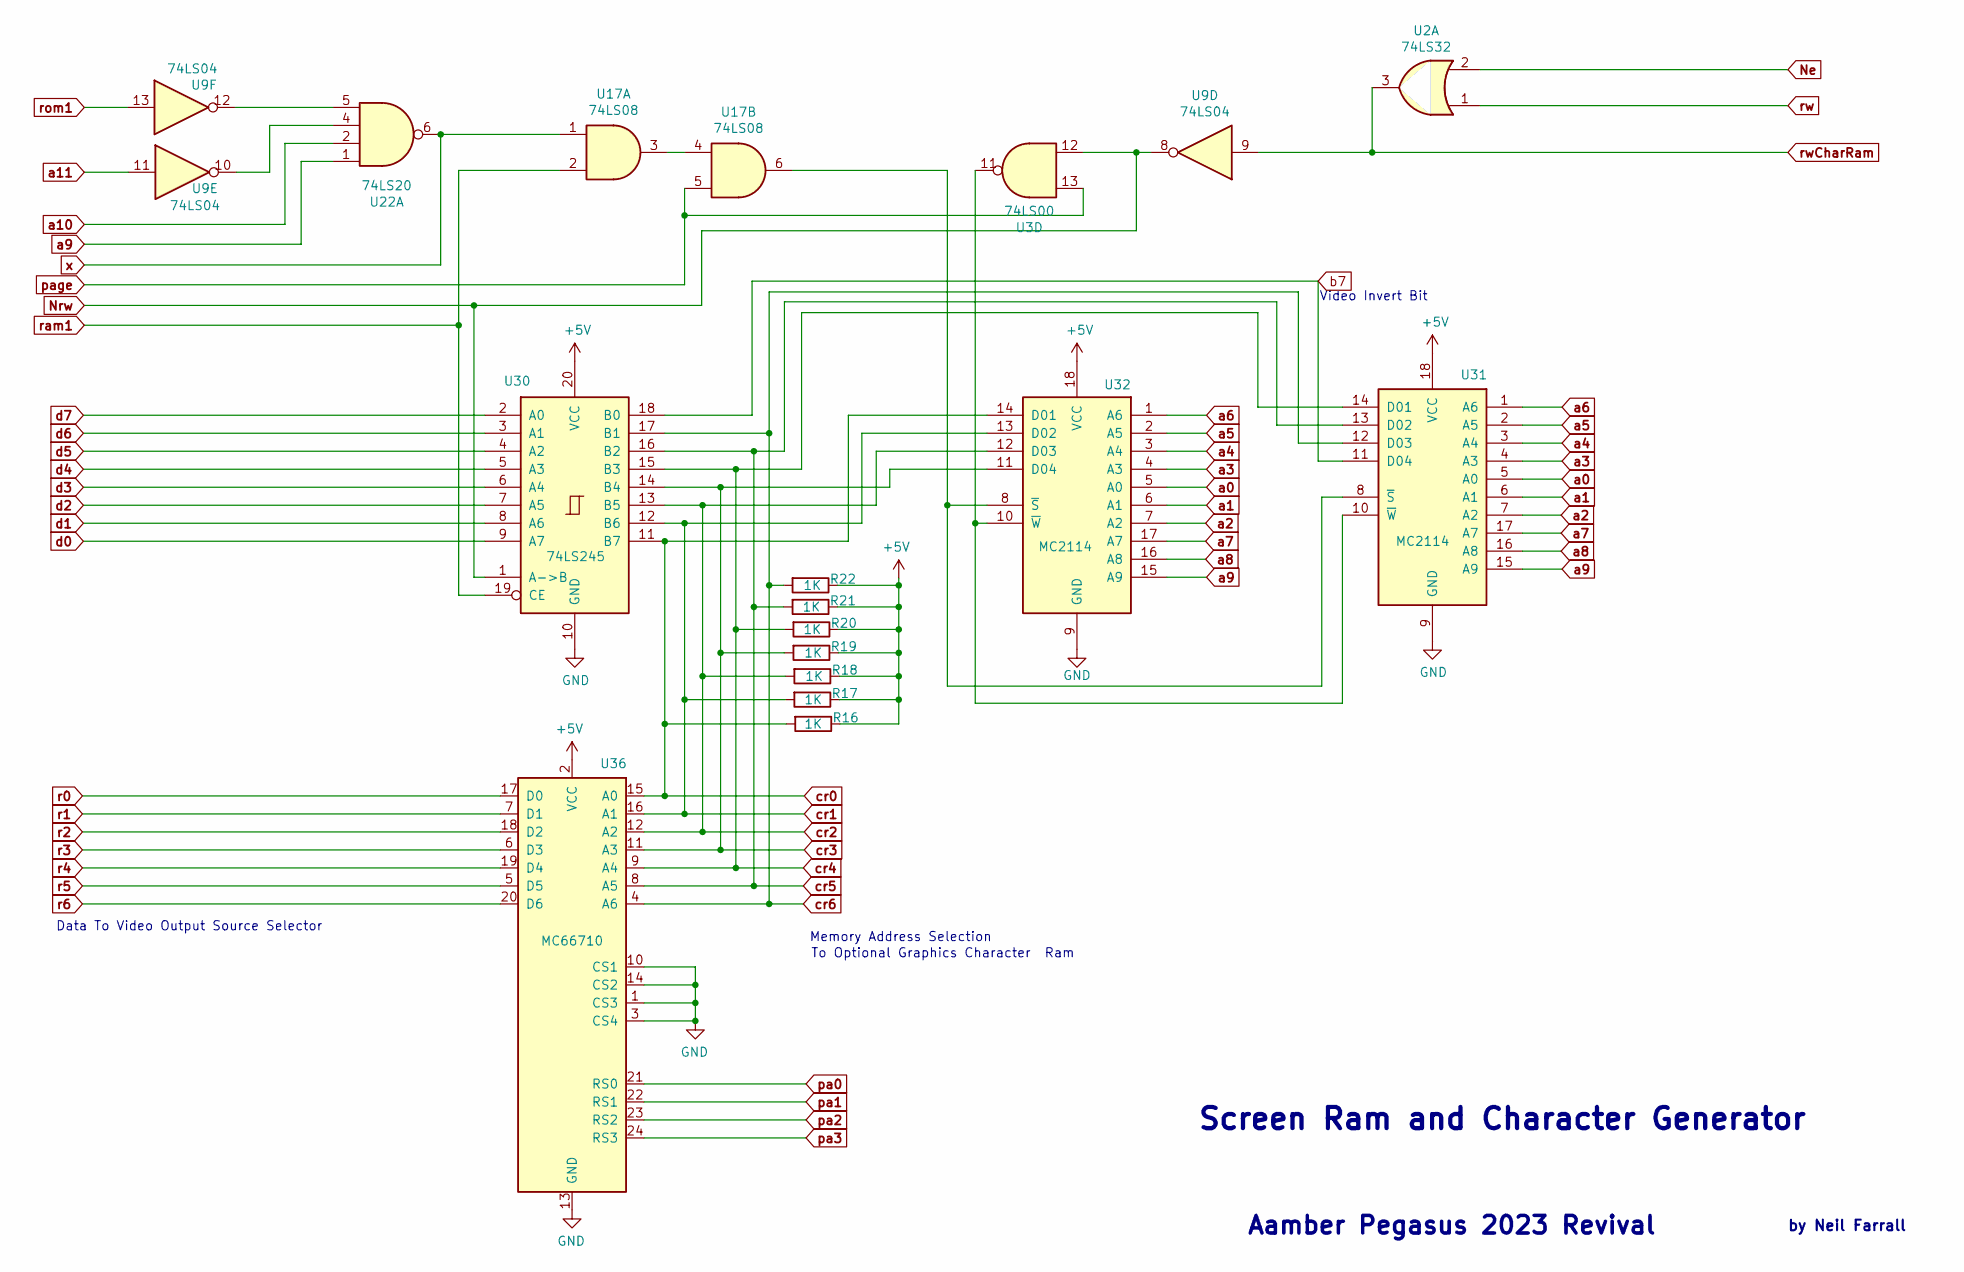
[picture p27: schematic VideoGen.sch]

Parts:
R16, R17, R18, R19, R20, R21, R22: 1K; R_Axial_DIN0411_L9.9mm_D3.6mm_P15.24mm_Horizontal
U2: 74LS32; DIP-14_W7.62mm_Socket_LongPads
U3: 74LS00; DIP-14_W7.62mm_Socket_LongPads
U9: 74LS04; DIP-14_W7.62mm_Socket_LongPads
U17: 74LS08; DIP-14_W7.62mm_Socket_LongPads
U22: 74LS20; DIP-14_W7.62mm_Socket_LongPads
U30: 74LS245; DIP-20_W7.62mm_Socket_LongPads
U31, U32: MC2114; DIP-18_W7.62mm_Socket_LongPads
U36: MC66710; DIP-24_W15.24mm_Socket_LongPads

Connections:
Ne: U2.2; also elsewhere on the board
unnamed: U3.11, U31.10 (~W), U32.10 (~W)
unnamed: U17.3, U17.4
unnamed: U17.6, U31.8 (~S), U32.8 (~S)
unnamed: U9.10, U22.4
unnamed: U9.12, U22.5
Nrw: U3.12, U9.8, U30.1 (A->B); also elsewhere on the board
a0: U31.5 (A0), U32.5 (A0); also elsewhere on the board
a1: U31.6 (A1), U32.6 (A1); also elsewhere on the board
a2: U31.7 (A2), U32.7 (A2); also elsewhere on the board
a3: U31.4 (A3), U32.4 (A3); also elsewhere on the board
a4: U31.3 (A4), U32.3 (A4); also elsewhere on the board
a5: U31.2 (A5), U32.2 (A5); also elsewhere on the board
a6: U31.1 (A6), U32.1 (A6); also elsewhere on the board
a7: U31.17 (A7), U32.17 (A7); also elsewhere on the board
a8: U31.16 (A8), U32.16 (A8); also elsewhere on the board
a9: U22.1, U31.15 (A9), U32.15 (A9); also elsewhere on the board
a10: U22.2; also elsewhere on the board
a11: U9.11; also elsewhere on the board
b7: U30.18 (B0), U31.11 (D04); also elsewhere on the board
cr0: R16.2, U30.11 (B7), U32.14 (D01), U36.15 (A0); also elsewhere on the board
cr1: R17.2, U30.12 (B6), U32.13 (D02), U36.16 (A1); also elsewhere on the board
cr2: R18.2, U30.13 (B5), U32.12 (D03), U36.12 (A2); also elsewhere on the board
cr3: R19.2, U30.14 (B4), U32.11 (D04), U36.11 (A3); also elsewhere on the board
cr4: R20.2, U30.15 (B3), U31.14 (D01), U36.9 (A4); also elsewhere on the board
cr5: R21.2, U30.16 (B2), U31.13 (D02), U36.8 (A5); also elsewhere on the board
cr6: R22.2, U30.17 (B1), U31.12 (D03), U36.4 (A6); also elsewhere on the board
d0: U30.9 (A7); also elsewhere on the board
d1: U30.8 (A6); also elsewhere on the board
d2: U30.7 (A5); also elsewhere on the board
d3: U30.6 (A4); also elsewhere on the board
d4: U30.5 (A3); also elsewhere on the board
d5: U30.4 (A2); also elsewhere on the board
d6: U30.3 (A1); also elsewhere on the board
d7: U30.2 (A0); also elsewhere on the board
pa0: U36.21 (RS0); also elsewhere on the board
pa1: U36.22 (RS1); also elsewhere on the board
pa2: U36.23 (RS2); also elsewhere on the board
pa3: U36.24 (RS3); also elsewhere on the board
page: U3.13, U17.5; also elsewhere on the board
r0: U36.17 (D0); also elsewhere on the board
r1: U36.7 (D1); also elsewhere on the board
r2: U36.18 (D2); also elsewhere on the board
r3: U36.6 (D3); also elsewhere on the board
r4: U36.19 (D4); also elsewhere on the board
r5: U36.5 (D5); also elsewhere on the board
r6: U36.20 (D6); also elsewhere on the board
ram1: U17.2, U30.19 (CE); also elsewhere on the board
rom1: U9.13; also elsewhere on the board
rw: U2.1; also elsewhere on the board
rwCharRam: U2.3, U9.9; also elsewhere on the board
x: U17.1, U22.6; also elsewhere on the board

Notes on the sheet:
Aamber Pegasus 2023 Revival
by Neil Farrall
Screen Ram and Character Generator
Memory Address Selection
Data To Video Output Source Selector
To Optional Graphics Character Ram
Video Invert Bit

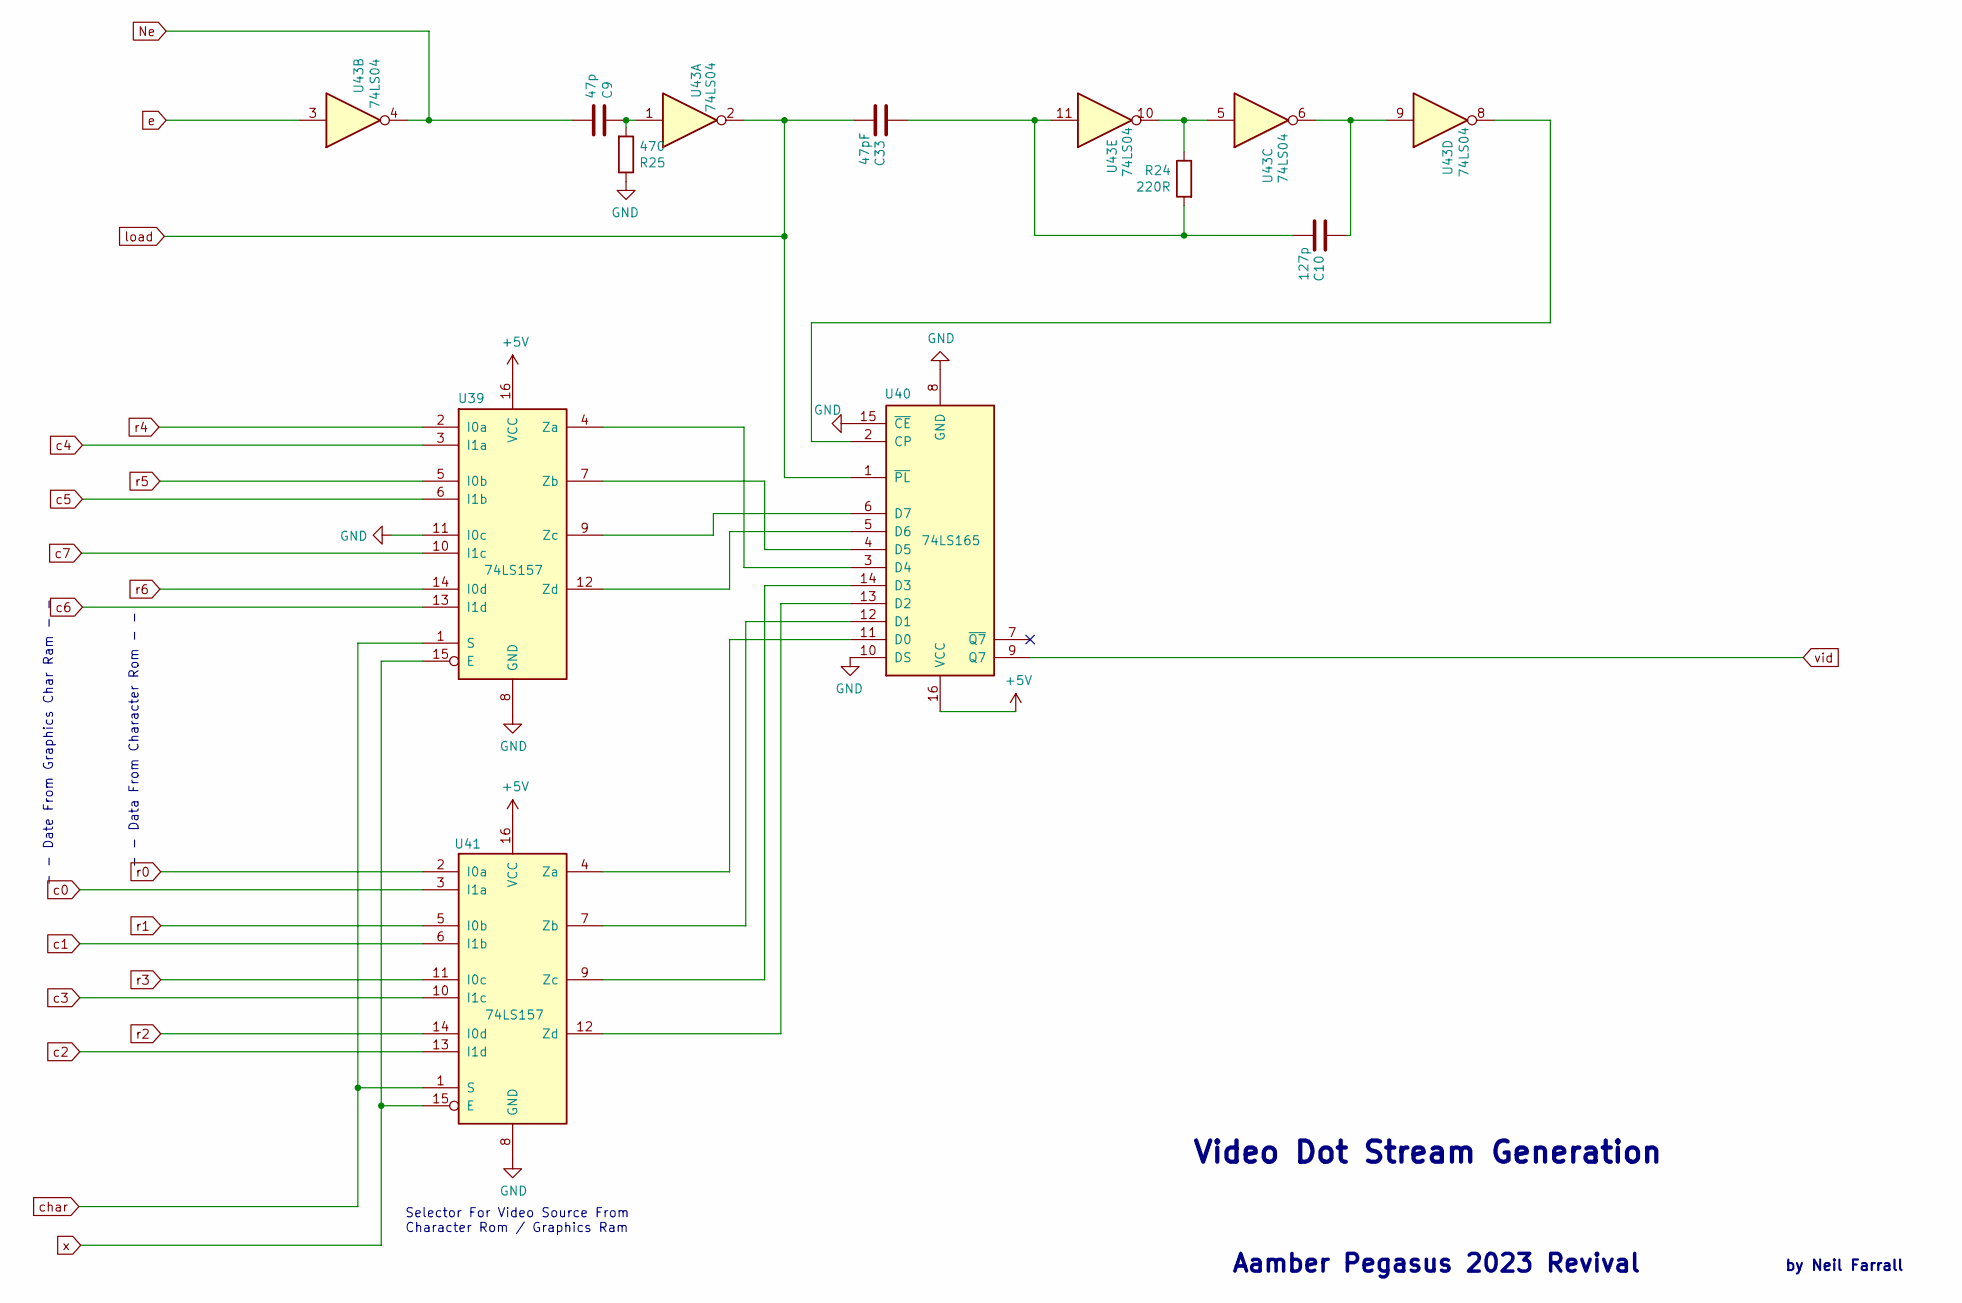
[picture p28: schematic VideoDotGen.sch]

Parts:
C9: 47p; C_Disc_D3.8mm_W2.6mm_P2.50mm
C10: 127p; C_Disc_D3.8mm_W2.6mm_P2.50mm
C33: 47pF; C_Disc_D3.8mm_W2.6mm_P2.50mm
R24: 220R; R_Axial_DIN0411_L9.9mm_D3.6mm_P15.24mm_Horizontal
R25: 470; R_Axial_DIN0411_L9.9mm_D3.6mm_P15.24mm_Horizontal
U39, U41: 74LS157; DIP-16_W7.62mm_Socket_LongPads
U40: 74LS165; DIP-16_W7.62mm_Socket_LongPads
U43: 74LS04; DIP-14_W7.62mm_Socket_LongPads

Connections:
Ne: C9.2, U43.4; also elsewhere on the board
unnamed: C9.1, R25.2, U43.1
unnamed: C10.1, U43.6, U43.9
unnamed: C10.2, C33.1, R24.2, U43.11
unnamed: R24.1, U43.5, U43.10
unnamed: U39.4 (Za), U40.3 (D4)
unnamed: U39.7 (Zb), U40.4 (D5)
unnamed: U39.9 (Zc), U40.6 (D7)
unnamed: U39.12 (Zd), U40.5 (D6)
unnamed: U40.2 (CP), U43.8
unnamed: U40.11 (D0), U41.4 (Za)
unnamed: U40.12 (D1), U41.7 (Zb)
unnamed: U40.13 (D2), U41.12 (Zd)
unnamed: U40.14 (D3), U41.9 (Zc)
c0: U41.3 (I1a); also elsewhere on the board
c1: U41.6 (I1b); also elsewhere on the board
c2: U41.13 (I1d); also elsewhere on the board
c3: U41.10 (I1c); also elsewhere on the board
c4: U39.3 (I1a); also elsewhere on the board
c5: U39.6 (I1b); also elsewhere on the board
c6: U39.13 (I1d); also elsewhere on the board
c7: U39.10 (I1c); also elsewhere on the board
char: U39.1 (S), U41.1 (S); also elsewhere on the board
e: U43.3; also elsewhere on the board
load: C33.2, U40.1 (~PL), U43.2; also elsewhere on the board
r0: U41.2 (I0a); also elsewhere on the board
r1: U41.5 (I0b); also elsewhere on the board
r2: U41.14 (I0d); also elsewhere on the board
r3: U41.11 (I0c); also elsewhere on the board
r4: U39.2 (I0a); also elsewhere on the board
r5: U39.5 (I0b); also elsewhere on the board
r6: U39.14 (I0d); also elsewhere on the board
vid: U40.9 (Q7); also elsewhere on the board
x: U39.15 (E), U41.15 (E); also elsewhere on the board

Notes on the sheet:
Aamber Pegasus 2023 Revival
by Neil Farrall
Video Dot Stream Generation
Selector For Video Source From Character Rom / Graphics Ram
- - Date From Graphics Char Ram - -
- - Data From Character Rom - -

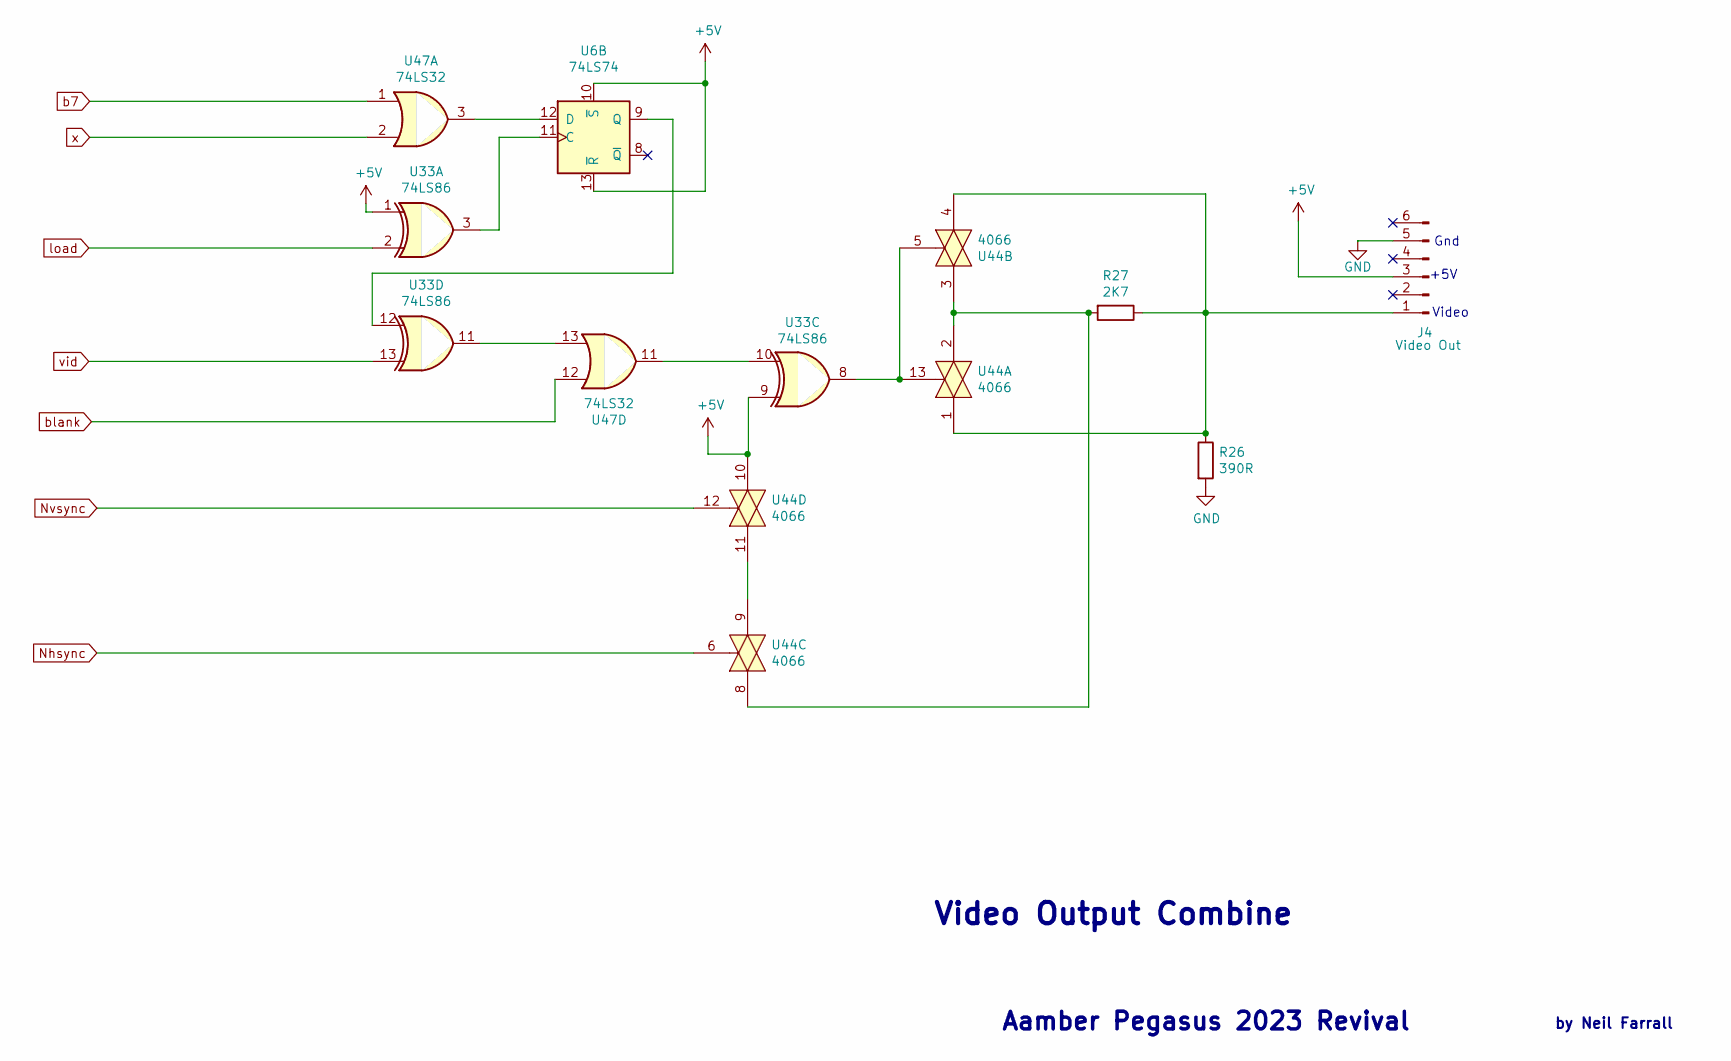
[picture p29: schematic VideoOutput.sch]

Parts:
J4: Video Out; PinHeader_1x06_P2.54mm_Horizontal
R26: 390R; R_Axial_DIN0411_L9.9mm_D3.6mm_P15.24mm_Horizontal
R27: 2K7; R_Axial_DIN0411_L9.9mm_D3.6mm_P15.24mm_Horizontal
U6: 74LS74; DIP-14_W7.62mm_Socket_LongPads
U33: 74LS86; DIP-14_W7.62mm_Socket_LongPads
U44: 4066; DIP-14_W7.62mm_Socket_LongPads
U47: 74LS32; DIP-14_W7.62mm_Socket_LongPads

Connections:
unnamed: J4.1, R26.1, R27.1, U44.1, U44.4
unnamed: R27.2, U44.2, U44.3, U44.8
unnamed: U6.11 (C), U33.3
unnamed: U33.8, U44.5, U44.13
unnamed: U33.10, U47.11
unnamed: U33.11, U47.13
unnamed: U6.9 (Q), U33.12
unnamed: U44.9, U44.11
unnamed: U6.12 (D), U47.3
Nhsync: U44.6; also elsewhere on the board
Nvsync: U44.12; also elsewhere on the board
b7: U47.1; also elsewhere on the board
blank: U47.12; also elsewhere on the board
load: U33.2; also elsewhere on the board
vid: U33.13; also elsewhere on the board
x: U47.2; also elsewhere on the board

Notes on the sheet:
Aamber Pegasus 2023 Revival
by Neil Farrall
Video Output Combine
Gnd
+5V
Video

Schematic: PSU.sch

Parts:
C11: 1uF 35V T; CP_Radial_Tantal_D5.0mm_P2.50mm
C12, C13, C14, C15, C16, C17, C18, C19, C20, C21, C22, C23, C24, C25, C26, C27, C28, C29, C30, C31, C103: 100N; C_Disc_D11.0mm_W5.0mm_P5.00mm
C34: 47uF; CP_Radial_Tantal_D8.0mm_P5.00mm
D2: GreenLED; LED_D5.0mm
J5: Power; PhoenixContact_MC_1,5_4-G-5.08_1x04_P5.08mm_Horizontal
R1, R2: 100R; R_Axial_DIN0411_L9.9mm_D3.6mm_P15.24mm_Horizontal
U1: 74LS14; DIP-14_W7.62mm_Socket_LongPads
U2, U47: 74LS32; DIP-14_W7.62mm_Socket_LongPads
U3: 74LS00; DIP-14_W7.62mm_Socket_LongPads
U4: 74LS21; DIP-14_W7.62mm_Socket_LongPads
U5: 74LS123; DIP-16_W7.62mm_Socket_LongPads
U6, U46: 74LS74; DIP-14_W7.62mm_Socket_LongPads
U9, U43: 74LS04; DIP-14_W7.62mm_Socket_LongPads
U14, U15, U16: 74LS139; DIP-16_W7.62mm_Socket_LongPads
U17: 74LS08; DIP-14_W7.62mm_Socket_LongPads
U22, U49: 74LS20; DIP-14_W7.62mm_Socket_LongPads
U33: 74LS86; DIP-14_W7.62mm_Socket_LongPads
U44: 4066; DIP-14_W7.62mm_Socket_LongPads
Ureg1: LM309K; TO-3; MPN LM7805CT; Digi-Key_PN LM7805CT-ND

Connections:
unnamed: C34.1, J5.2, Ureg1.2 (VI)
unnamed: D2.1 (K), R1.1
unnamed: D2.2 (A), R2.2

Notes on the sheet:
Aamber Pegasus 2023 Revival
by Neil Farrall
Power Supply
POWER

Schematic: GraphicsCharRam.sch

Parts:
U2: 74LS32; DIP-14_W7.62mm_Socket_LongPads
U33: 74LS86; DIP-14_W7.62mm_Socket_LongPads
U34, U35, U37, U38: MC2114; DIP-18_W7.62mm_Socket_LongPads
U42: 74LS245; DIP-20_W7.62mm_Socket_LongPads

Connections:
unnamed: U2.6, U34.10 (~W), U35.10 (~W), U37.10 (~W), U38.10 (~W)
unnamed: U33.6, U35.8 (~S), U38.8 (~S)
Nrw: U42.1 (A->B); also elsewhere on the board
c0: U37.14 (D01), U38.14 (D01), U42.11 (B7); also elsewhere on the board
c1: U37.13 (D02), U38.13 (D02), U42.12 (B6); also elsewhere on the board
c2: U37.12 (D03), U38.12 (D03), U42.13 (B5); also elsewhere on the board
c3: U37.11 (D04), U38.11 (D04), U42.14 (B4); also elsewhere on the board
c4: U34.14 (D01), U35.14 (D01), U42.15 (B3); also elsewhere on the board
c5: U34.13 (D02), U35.13 (D02), U42.16 (B2); also elsewhere on the board
c6: U34.12 (D03), U35.12 (D03), U42.17 (B1); also elsewhere on the board
c7: U34.11 (D04), U35.11 (D04), U42.18 (B0); also elsewhere on the board
charram: U2.4, U42.19 (CE); also elsewhere on the board
cr0: U34.15 (A9), U35.15 (A9), U37.15 (A9), U38.15 (A9); also elsewhere on the board
cr1: U34.7 (A2), U35.7 (A2), U37.7 (A2), U38.7 (A2); also elsewhere on the board
cr2: U34.6 (A1), U35.6 (A1), U37.6 (A1), U38.6 (A1); also elsewhere on the board
cr3: U34.5 (A0), U35.5 (A0), U37.5 (A0), U38.5 (A0); also elsewhere on the board
cr4: U34.4 (A3), U35.4 (A3), U37.4 (A3), U38.4 (A3); also elsewhere on the board
cr5: U34.3 (A4), U35.3 (A4), U37.3 (A4), U38.3 (A4); also elsewhere on the board
cr6: U33.4, U34.8 (~S), U37.8 (~S); also elsewhere on the board
d0: U42.9 (A7); also elsewhere on the board
d1: U42.8 (A6); also elsewhere on the board
d2: U42.7 (A5); also elsewhere on the board
d3: U42.6 (A4); also elsewhere on the board
d4: U42.5 (A3); also elsewhere on the board
d5: U42.4 (A2); also elsewhere on the board
d6: U42.3 (A1); also elsewhere on the board
d7: U42.2 (A0); also elsewhere on the board
pa0: U34.2 (A5), U35.2 (A5), U37.2 (A5), U38.2 (A5); also elsewhere on the board
pa1: U34.1 (A6), U35.1 (A6), U37.1 (A6), U38.1 (A6); also elsewhere on the board
pa2: U34.17 (A7), U35.17 (A7), U37.17 (A7), U38.17 (A7); also elsewhere on the board
pa3: U34.16 (A8), U35.16 (A8), U37.16 (A8), U38.16 (A8); also elsewhere on the board
rwCharRam: U2.5; also elsewhere on the board

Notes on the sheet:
opt.
Optional Graphics Character Ram
Aamber Pegasus 2023 Revival
1.0
by Neil Farrall
Character Address Selection
Graphics Char Data To Video Output Source Selector

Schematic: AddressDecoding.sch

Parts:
JP1: rom2; SolderJumper-2_P1.3mm_Open_Pad1.0x1.5mm
JP2: rom3; SolderJumper-2_P1.3mm_Open_Pad1.0x1.5mm
JP3: rom2 alt; SolderJumper-2_P1.3mm_Open_Pad1.0x1.5mm
JP4: rom3 alt; SolderJumper-2_P1.3mm_Open_Pad1.0x1.5mm
JP5, JP8: opt.; SolderJumper-2_P1.3mm_Open_Pad1.0x1.5mm
R13: 1K; R_Axial_DIN0411_L9.9mm_D3.6mm_P15.24mm_Horizontal
U2: 74LS32; DIP-14_W7.62mm_Socket_LongPads
U3: 74LS00; DIP-14_W7.62mm_Socket_LongPads
U4: 74LS21; DIP-14_W7.62mm_Socket_LongPads
U9: 74LS04; DIP-14_W7.62mm_Socket_LongPads
U14, U15, U16: 74LS139; DIP-16_W7.62mm_Socket_LongPads
U17: 74LS08; DIP-14_W7.62mm_Socket_LongPads

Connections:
unnamed: JP1.1 (A), U16.11 (O1)
unnamed: JP2.1 (A), U16.12 (O0)
unnamed: JP3.2 (B), U15.5 (O1)
unnamed: JP4.2 (B), U15.4 (O0)
unnamed: JP5.1 (A), JP8.1 (A), U16.4 (O0), U16.15 (E)
unnamed: JP5.2 (B), R13.2, U17.13
unnamed: U3.2, U9.2
unnamed: U2.11, U14.1 (E)
unnamed: U14.15 (E), U15.9 (O3)
unnamed: U15.1 (E), U16.7 (O3)
unnamed: U2.13, U9.1, U15.6 (O2)
unnamed: U4.12, U15.10 (O2)
unnamed: U4.10, U15.11 (O1)
unnamed: U4.9, U15.12 (O0)
unnamed: U15.15 (E), U16.6 (O2)
unnamed: U4.13, U16.5 (O1)
unnamed: U3.3, U17.9
unnamed: U17.10, U17.11
unnamed: U4.8, U17.12
Nsel: U17.8; also elsewhere on the board
a9: U14.2 (A0); also elsewhere on the board
a10: U14.3 (A1), U14.14 (A0); also elsewhere on the board
a11: U2.12, U3.1, U14.13 (A1); also elsewhere on the board
a12: U15.2 (A0), U15.14 (A0), U16.14 (A0); also elsewhere on the board
a13: U15.3 (A1), U15.13 (A1), U16.13 (A1); also elsewhere on the board
a14: U16.2 (A0); also elsewhere on the board
a15: U16.3 (A1); also elsewhere on the board
charram: U14.5 (O1); also elsewhere on the board
pia1: U14.7 (O3); also elsewhere on the board
pia2: U14.6 (O2); also elsewhere on the board
ram1: U14.9 (O3); also elsewhere on the board
ram2: U14.10 (O2); also elsewhere on the board
ram3: U14.11 (O1); also elsewhere on the board
ram4: U14.12 (O0); also elsewhere on the board
rom1: U15.7 (O3); also elsewhere on the board
rom2: JP1.2 (B), JP3.1 (A); also elsewhere on the board
rom3: JP2.2 (B), JP4.1 (A); also elsewhere on the board
rom4: JP8.2 (B); also elsewhere on the board

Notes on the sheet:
0000 - 3FFF
4000-7FFF
8000-BFFF
C000-FFFF
C000-CFFF
D000-DFFF
F000-FFFF
8000-8FFF
9000-9FFF
A000-AFFF
B000-BFFF
0000-0FFF
1000-1FFF
2000-2FFF
3000-3FFF
E000-EFFF
E000-E7FF
E000-E1FF
E200-E3FF
E400-E5FF
E600-E7FF
(Ram Expansion)
8000-AFFF
4000-AFFF
E800-EFFF
Reserved
B000-B3FF
B400-B7FF
B800-BBFF
BC00-BFFF
Optional D27128 16Kx8 Eprom
Select For Off Board Devices
(Break JP1,2,5 Make JP8,3,4)
- Move Rom address space 0000-3FFF to I/O bus by: Break JP8 and Make JP5
NSEL will then map the following to the external bus: 0000-3FFF - 16K Rom expansion 4000-7FFF - 16K Ram expansion 8000-AFFF - 12K Ram expansion E800-EFFF - 2K I/O expansion
- If using external Rom board, remap Rom2 and 3 to their alternative addresses by: Break JP1,2 and Make JP3,4
Aamber Pegasus 2023 Revival
by Neil Farrall
Address Decoding / Chip Select

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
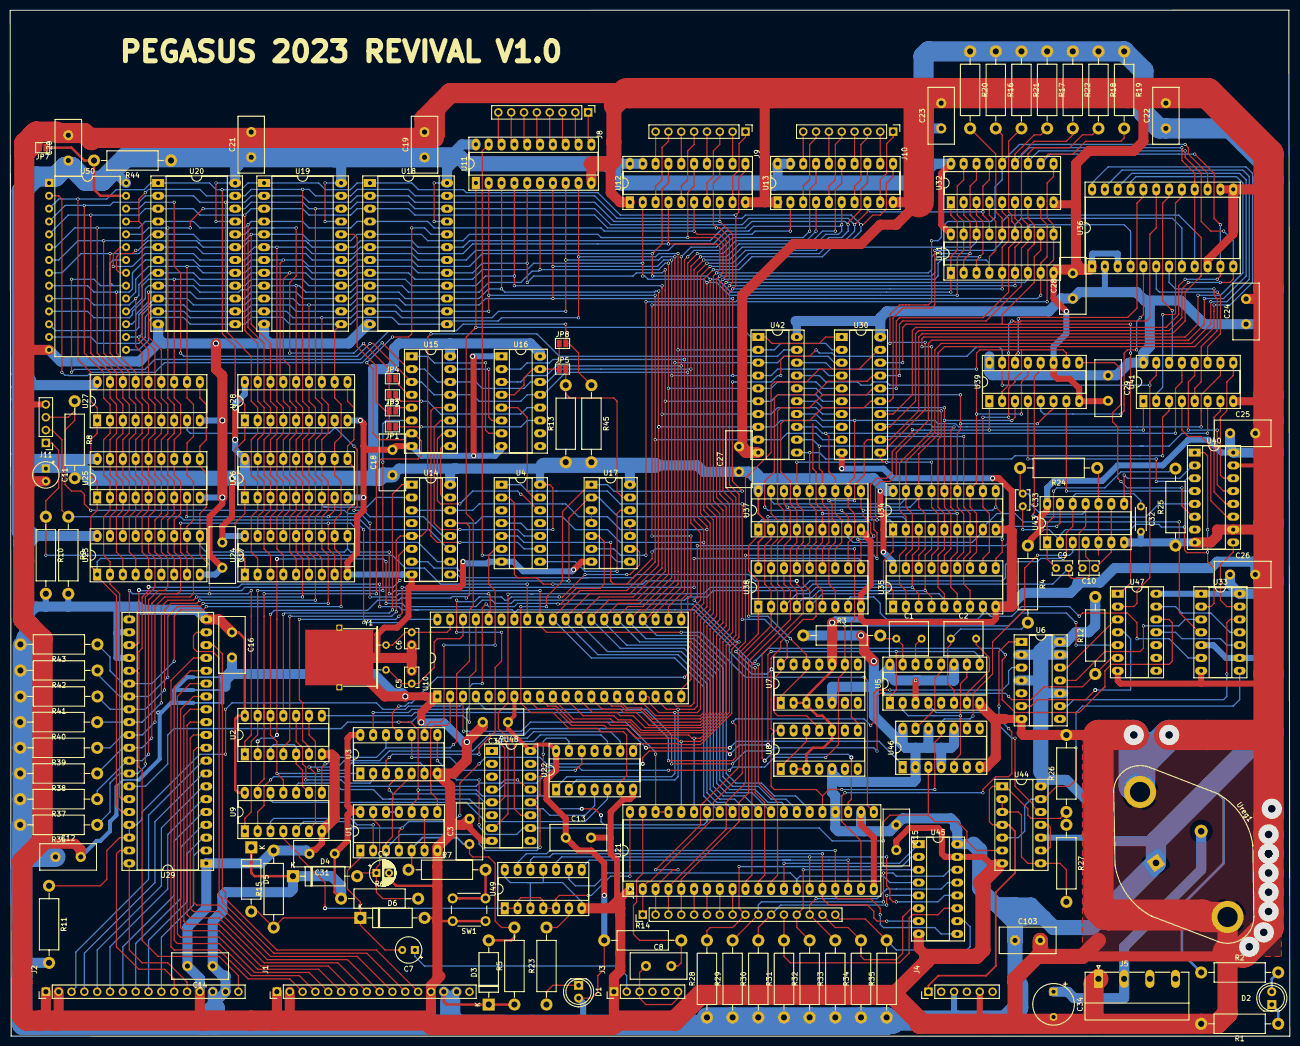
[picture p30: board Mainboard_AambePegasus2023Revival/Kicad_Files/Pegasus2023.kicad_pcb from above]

Board: 2 copper layers, 253.2 x 203.0 mm, 156 parts (0 on the bottom side), 239 nets.
